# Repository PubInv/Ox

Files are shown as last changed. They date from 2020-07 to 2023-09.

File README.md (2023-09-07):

# NASA-COG

## Final Report

The final report delivered to NASA for this project can be [read here](https://drive.google.com/file/d/1jfJcSLfsybuC49I7llPhfTNI8ucRUW3h/view?usp=sharing).

## Introduction

This is a repo for a control system made for NASA to drive a Ceramic Oxygen Generation
technology they have developed. It was forked from ["The Ox"]() project of Public Invention run by Mr. Ben Coombs, which was in turn a fork of the VentOS project of Helpful Engineering let my Ben Coombs, Dr. Erich Schulz, and Robert L. Read.

However, the main reason we are starting with this fork is not that the Pressure Swing
Adsorption system of the Ox is a particularly relevant, but rather that the code
represents a nice platform of simple microcontroller control of related machines.

To wit, includes PlatformIO configuration, a state machine (finite automata),
a superloop architecutre, and a hardware abstraction layer.

This particular project of NASA will improve life support technology in space,
but may eventually greatly improve global health.

An unlisted [YouTube video](https://youtu.be/1nq-Mw7jZ5A) has been uploaded that shows this work in progress as of September, 2022.

## How to run

At present, this code does little (for the NASA COG project). We intend
to build a native (that is, laptop) simulation using mock hardware components.
The fundamental way to run this is to perform:
> cd firmware

> pio run -e native && ./.pio/build/native/program

We are currently creating the [RibbonFish](https://github.com/PubInv/NASA-COG/blob/develop/RibbonFish.md) proof-of-concept.

This can be run on a Due by executing:

> make pio-run-due_ribbonfish

As this develops, it will use a specific Due hardware configuration,
please see the [documentation](https://github.com/PubInv/NASA-COG/blob/develop/RibbonFish.md) for details to build your own.

## Annoyances

AFAIK, PlatformIO forces a directory tree depth of 5 levels.

This is not enough to organize the Hardware Abstraction Level they way I would prefer, forcing us to make some messy directories that are less than clear.

For example, to implement a Temperature Sensor, we would ideally have an
abstract (or virtual) implementation, a folder for real hardware,
and a folder for mock sensors.  I have no choice now but to jam
the mock sensors into the same directory with the real hardware and
use a naming convnention.

## The Command System

The NASA-COG system needs to allow the user to enter commands. The most obvious of these is "turn off".
Because the system should avoid thermal shocks, this is actually not simple.

We have previously used an [approach](https://github.com/PubInv/PIRCS-pubinv-respiration-control-standard) of using simple JSON objects to represent commands. We propose to use the same idea here, but obviously,
the command will be custom to the NASA-COG.

### Parameter Setting Commands
The general scheme is to use a JSON object like:

```JavaScript
{ "com": "T",
  "par": 7,
  "mod": "T",
  "val" : 732.3
  }
```

1. "com" is the command. For example, "T" can mean "set Temperature".
2. "par" is a parameter used to specify something about how to execute the command. For example, 7 could mean location 7, which might be between the 6th and 7th stack.
3. "mod" is a modifier of the command. For example, the "set Temperature" command could be used to
set the minimum, maximum, or the target temperature.
4. "val" is the value that is to be set.

For this problem space, we can specify some global parameters of the problem, some of which
involve safety. These can of course have default values "hard wired" into the code, but an
experimenter may wish to change these values (carefully).

1. The maximum rate of voltage change applied to a stack. Nominally we have defined this as 1 volt/second.
We have evidence that too rapid a voltage change (such as that caused by pulse-width modulation) can destroy
a stack.
2. The maximum rate of temperature change for a stack. Nominally we may say this as 2 degree K per minute,
which would allow the machine to reach operating temperature in 6 hours.
3. The maximum temperature difference across a stack in any dimenstion. We may not be able to control
this directly, but we can use it as a target.
4. The maximum voltage applied to a stack.
5. The maximum amperage applied to a stack.

### Event-like Commands

We will need other commands that represent discrete events in time. For example, each transition in the
state transition diagram below may be initiated by a command from the user (they may also occur
automatically due to an internal fault or even normal operation.)

COG State Machine

We can implement particular commands with the same scheme.

For example, the simple object:

```JavaScript
{ "com": "C",
  "par": 0,
  "int": "s",
  "mod": "U",
  "val" : 0.0
  }
```

Could mean "Cool Down". The value "U" is used becasue the "mod" command is "unusued" in this case.

```JavaScript
{ "com": "W",
  "par": M,
  "int": "s",
  "mod": "U",
  "val" : 0.0
  }
```

In actual practice, these commands will be pasted into the serial port using either PlatformIO or the Arduino IDE.

Eventually, a user interface may be implemented that uses a knob or a nice webpage to enter commands.
However, by having each of these take only actions that can be implemented as such a command,
we bring discipline to the internal code.

## Actual Serial Commands

The serial port currently supports 6 one-character commands: w,c,e,a,i,o.
These mean:
1. warmup
2. cool down
3. emergency shutdown
4. acknowledge
5. idle
6. operate

Note: "acknowledge" means that the operator acknowledges that a critical
state has occurred and asserts it is okay to return to normal operation,
either because the problem as been removed or for some other reason.

Addtionally, the system supports "full commands", that look like this:

> { "com": "W", "par": "M", "int": "s", "mod": "U", "val" : 0.0 }

> { "com": "C", "par": "M", "int": "s", "mod": "U", "val" : 0.0 }

> { "com": "E", "par": "M", "int": "s", "mod": "U", "val" : 0.0 }

> { "com": "A", "par": "M", "int": "s", "mod": "U", "val" : 0.0 }

> { "com": "I", "par": "M", "int": "s", "mod": "U", "val" : 0.0 }

> { "com": "O", "par": "M", "int": "s", "mod": "U", "val" : 0.0 }

In fact, each "one character" command is a short hand for these commands.

The following format can be used to set parameters (P).
The three most important parameters are:
1. T : Temperature (in C) going into the stack
2. C : Current (in milliamps) going into the stack
3. F : Fan speed in RPM (we expect this to change to flow rate in SLM)
> { "com": "P", "par": "T", "int": "T", "mod": "U", "val" : 35 }

> { "com": "P", "par": "C", "int": "T", "mod": "U", "val" : 500 }

> { "com": "P", "par": "F", "int": "T", "mod": "U", "val" : 2000 }

These three commands set the:
1. Temperature into the stack to 35C
2. Set the Target current into the stack to 500 milliamps
3. Set the flow rate to 2000 ml/seconds

## License

In general we intend to follow the [Public Invention Licensed Guidelines](https://github.com/PubInv/PubInv-License-Guidelines) unless
NASA requests something different. If you are starting your own project, please
feel free to fork the license guidelines as a starting point if you like our
license policy.

This program includes free software: you can redistribute it and/or modify it under the terms of the GNU Affero General Public License as published by the Free Software Foundation, either version 3 of the License, or (at your option) any later version.

See the GNU Affero General Public License for more details. You should have received a copy of the GNU Affero General Public License along with this program. If not, see <https://www.gnu.org/licenses/>.

This program is distributed in the hope that it will be useful, but WITHOUT ANY WARRANTY; without even the implied warranty of MERCHANTABILITY or FITNESS FOR A PARTICULAR PURPOSE.

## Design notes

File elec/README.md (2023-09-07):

# Electrical Information on ODECOS Controler(s) and Plant(s)
PCB Connector Pin signal names, Due Signal Names, Chassis wiring and related information
Inverse cronological order

## Unit 3-???
A place holder for future work
See: TBD

## Unit 2
### Notes for creation of a new PCB  
This table pulls from information in the references 1 and 2.   
References:
1. Due Pin-Out Map for OEDCS1 : https://docs.google.com/spreadsheets/d/18wP1Cyg5-j3FP92x7no_JsCCFNvo9y2avyn5nvmAj6I/edit#gid=0
2. Fan Controller and Fan Wiring for OEDCS1: https://docs.google.com/document/d/1n3v-AxqNKEzcKqmHicGKnFmG8sKbNEL_pGaUlU9CZ8U/edit

   WARNING! At present pin D4 works without an external pull up resistor for the termocouples, but D5 does not; it requires an external pull up resistor
   Until we have time to rework our perf board, I am going to continue to use D4 for the MAX31850 OneWire interface.

#### Due Pin Wiring
| **Due Pin Number** 	| **Breakout** 	| **Signal Name** 	| **Set as I/O** 	| **Connection** 	| **Notes** 	|
|---	|---	|---	|---	|---	|---	|
| D0 	| J6-2 	| NA 	| Input pullup. 	| None 	| Not used 	|
| D1 	| J6-1 	| NA 	| Input pullup. 	| None 	| Not used 	|
| D2 	| J6-3 	| NA 	| Input pullup. 	| None 	| Not used 	|
| D3 	| J6-4 	| NA 	| Input pullup. 	| None 	| Not used 	|
| D4 	| J6-5 	| SD ENABLE (BUT ALSO TEMP1) | Input pullup. 	| None 	| SD CS on Ethernet card. 	|
| D5 	| J6-6 	| TEMP1 	| BiDirection 	| Dallas 1 Wire / MAX31850K 	| Three daisy chained, requires 4.7k ohm pull up resistor (but D4 does not!) Please see note 	|
| D6 	| J6-7 	| NA 	| Input pullup. 	| None 	| Not used 	|
| D7 	| J6-8 	| NA 	| Input pullup. 	| None 	| Not used 	|
| D8 	| J7-1 	| NA 	| Input pullup. 	| None 	| Not used 	|
| D9 	| J7-2 	| nFAN1_PWM 	| Output 	| Controlles transistor Q1 	| Was BLOWER_PWM 	|
| D10 	| J7-3 	| NA 	| Input pullup. 	| None 	| Not used 	|
| D11 	| J7-4 	| NA 	| Input pullup. 	| None 	| Not used 	|
| D12 	| J7-5 	| NA 	| Input pullup. 	| None 	| Not used 	|
| D13 	| J7-6 	| NA 	| Input pullup. 	| None 	| Not used 	|
| D13 	| J7-6 	| NA 	| Input pullup. 	| None 	| Not used 	|
| D14 	| J2-1 	| NA 	| 	| None 	| Not used 	|
| D15 	| J2-2 	| NA 	| Input pullup. 	| None 	| Not used 	|
| D16 	| J2-3 	| NA 	| Input pullup. 	| None 	| Can be TX2 	|
| D17 	| J2-4 	| NA 	| Input pullup. 	| None 	| Can be RX2 	|
| D18 	| J2-5 	| D_PSU_TX 	| UART1 TX 	| D_PSU_TX, R15 (then to Power Supply 	| TX1 	|
| D19 	| J2-6 	| D_PSU_RX 	| UART1 RX 	| D_PSU_RX, R14 (then to Power Supply 	| RX1 	|
| D20 	| J2-7 	| SDA 	| SDA 	| test point SDA1, R4, R13 	| SDA 	|
| D21 	| J2-8 	| SCL 	| SCL 	| test point SCL1, R2, R16 	| SCL 	|
| D22 	| J8-4 	| BLOWER_ENABLE 	| OUTPUT 	| R10 	| Enable Switched_Fan_Power at J15 9-12 	|
| D23 	| J8-3 	| NA 	| Input pullup. 	| None 	| Not used 	|
| D24 	| J8-6 	| NA 	| Input pullup. 	| None 	| Not used 	|
| D25 	| J8-5 	| NA 	| Input pullup. 	| None 	| Not used 	|
| D26 	| J8-8 	| NA 	| Input pullup. 	| None 	| Not used 	|
| D27 	| J8-7 	| NA 	| Input pullup. 	| None 	| Not used 	|
| D28 	| J8-10 	| NA 	| Input pullup. 	| None 	| Not used 	|
| D29 	| J8-9 	| NA 	| Input pullup. 	| None 	| Not used 	|
| D30 	| J8-12 	| NA 	| Input pullup. 	| None 	| Not used 	|
| D31 	| J8-11 	| NA 	| Input pullup. 	| None 	| Not used 	|
| D32 	| J8-14 	| nCS_GPAD 	| Output for nCS 	| R55, R61, Q5 	| on 3.3 Volt 	|
| D33 	| J8-13 	| TC_nCS1 	| Output for nCS 	| Thermocouple 1, R7 	| on 3.3 Volt 	|
| D34 	| J8-16 	| TC_nCS2 	| Output for nCS 	| Thermocouple 2, R3 	| on 3.3 Volt 	|
| D35 	| J8-15 	| TC_nCS3 	| Output for nCS 	| Thermocouple 3, R1 	| on 3.3 Volt 	|
| D36 	| J8-18 	| NA 	| Input pullup. 	| None 	| Not used 	|
| D37 	| J8-17 	| NA 	| Input pullup. 	| None 	| Not used 	|
| D38 	| J8-20 	| NA 	| Input pullup. 	| None 	| Not used 	|
| D39 	| J8-19 	| NA 	| Input pullup. 	| None 	| Not used 	|
| D39 	| J8-19 	| NA 	| Input pullup. 	| None 	| Not used 	|
| D40 	| J8-22 	| NA 	| Input pullup. 	| None 	| Not used 	|
| D41 	| J8-21 	| NA 	| Input pullup. 	| None 	| Not used 	|
| D42 	| J8-24 	| NA 	| Input pullup. 	| None 	| Not used 	|
| D43 	| J8-23 	| NA 	| Input pullup. 	| None 	| Not used 	|
| D44 	| J8-26 	| NA 	| Input pullup. 	| None 	| Not used 	|
| D45 	| J8-25 	| NA 	| Input pullup. 	| None 	| Not used 	|
| D46 	| J8-28 	| NA 	| Input pullup. 	| None 	| Not used 	|
| D47 	| J8-27 	| NA 	| Input pullup. 	| None 	| Not used 	|
| D48 	| J8-30 	| NA 	| Input pullup. 	| None 	| Not used 	|
| D49 	| J8-29 	| NA 	| Input pullup. 	| None 	| Not used 	|
| D50 	| J8-32 	| NA 	| Input pullup. 	| None 	| Not used 	|
| D51 	| J8-31 	| SSR_PWM 	| OUTPUT 	| R9 	| Active High. 	|
| D52 	| J8-34 	| NA 	| Input pullup. 	| None 	| Not used 	|
| D53 	| J8-33 	| NA 	| Input pullup. 	| None 	| Not used 	|
| SDA1 	| J7-9 	| NA 	| Input pullup. 	| None 	| Not used 	|
| SCL1 	| J7-10 	| NA 	| Input pullup. 	| None 	| Not used 	|
| CANR 	| J4-7 	| NA 	| Input pullup. 	| None 	| Not used 	|
| CANT 	| J4-8 	| NA 	| Input pullup. 	| None 	| Not used 	|
| DAC0 	| J4-5 	| Disable 	| Only Output 	| None 	| Not used 	|
| DAC1 	| J4-6 	| Disable 	| Only Output 	| None 	| Not used 	|
| A0 	| J5-1 	| BLOWER_TACH 	| Input pullup. 	| R11 	| Measure RPM 	|
| A1 	| J5-2 	| NA 	| Input pullup. 	| None 	| Not used 	|
| A2 	| J5-3 	| NA 	| Input pullup. 	| None 	| Not used 	|
| A3 	| J5-4 	| NA 	| Input pullup. 	| None 	| Not used 	|
| A4 	| J5-5 	| NA 	| Input pullup. 	| None 	| Not used 	|
| A5 	| J5-6 	| NA 	| Input pullup. 	| None 	| Not used 	|
| A6 	| J5-7 	| NA 	| Input pullup. 	| None 	| Not used 	|
| A7 	| J5-8 	| NA 	| Input pullup. 	| None 	| Not used 	|
| A8 	| J4-1 	| NA 	| Input pullup. 	| None 	| Not used 	|
| A9 	| J4-2 	| NA 	| Input pullup. 	| None 	| Not used 	|
| A9 	| J4-2 	| NA 	| Input pullup. 	| None 	| Not used 	|
| A10 	| J4-3 	| NA 	| Input pullup. 	| None 	| Not used 	|
| A11 	| J4-4 	| NA 	| Input pullup. 	| None 	| Not used 	|
| AREF 	| J7-8 	| NA 	| From DUE 	| None 	| Not used 	|
| nRST1 	| J3-6 	| NA 	| Pulled up on DUE 	| None 	| Not used 	|
| IOREF 	| J3-7 	| NA 	| NA 	| None 	| Not used 	|
| VIN 	| J3-1 	| VIN 	| NA 	| +12V into this pin through R76 	| 	|
| +5V 	| J3-4 	| VIN+5V 	| NA 	| Power from Due voltage regulator 	| Three pins. 	|
| 3.3V 	| J3-5 	| 3.3V 	| NA 	| Power from Due voltage regulator 	| One pin. 	|
| MISO 	| tp CPIO1 	| CIPO 	| Input 	| SPI bus 	| 	|
| MOSI 	| tp COPI 	| COPI 	| Output 	| SPI bus 	| 	|
| SCK 	| tp SPI_SCK 	| SPI_SCK 	| Output 	| SPI bus 	| 	|
| nRST2 	| NA 	| SPI_nRST 	| Input 	| S1 reset switch 	| 	|
| end 	| 	| 	| 	| 	| 	|  

**Ethernet pin usage:**
Pins usage on Arduino
* D4: SD card chip select
* D10: W5200 Chip Select
* D11: SPI MOSI
* D12: SPI MISO
* D13: SPI SCK

### Chassis Wiring of ODECOS Unit 2.
Diagram(s) here...

## Unit 1
Wiring of ODECOS Unit 1 Notes
1. Due Pin-Out Mape for OEDCS1 : https://docs.google.com/spreadsheets/d/18wP1Cyg5-j3FP92x7no_JsCCFNvo9y2avyn5nvmAj6I/edit#gid=0
2. Fan Controller and Fan Wiring for OEDCS1: https://docs.google.com/document/d/1n3v-AxqNKEzcKqmHicGKnFmG8sKbNEL_pGaUlU9CZ8U/edit

Wiring of thermocouple amplifires


Revisions:
* 20230821, Update DB25 Male 2-5 from +12V to "+24V Switched (fans)"

| Fan Breakout 	| Signal-Function 	| DB25 MALE Pin # 	| DB25 FEMALE Pin # 	| Other 	| Due Pin 	| Due Signal 	|
|---	|---	|---	|---	|---	|---	|---	|
| 1 	| +24V Switched (fans) 	| 2-5 	| 9-12 	| 	| ??? 	| FAN_POWER 	|
| 2 	| GND for all fans  	| 22-25 	| 14-17 	| 	| GND 	| NA 	|
| 3 	| #1 PWM 	| 13 	| 1 	| J10-1 	| D9 	| nFAN1_PWM  	|
| 4 	| #1 Tach 	| 9 	| 5 	| J9-1  	| A0 	| FAN1_FG 	|
| 5 	| #2 PWM 	| 12 	| 2 	| J10-2 	| 	| nFAN2_PWM  	|
| 6 	| #2 Tach 	| 8 	| 6 	| J9-2  	| 	| FAN2_FG 	|
| 7 	| #3 Tach 	| 11 	| 3 	| J10-3 	| 	| nFAN3_PWM  	|
| 8 	| #3 PWM 	| 7 	| 7 	| J9-3  	| 	| FAN3_FG 	|
| 9 	| #4 Tach 	| 10 	| 4 	| J10-4 	| 	| nFAN4_PWM  	|
| 10 	| #4 PWM 	| 6 	| 8 	| J9-4  	| 	| FAN4_FG 	|
| 	| 	| 	| 25 	| J11-3 	| 	| 	|
| 	| 	| 	| 13 	| J11-4 	| 	| 	|
| 	| 	| 	| 18 	| J12-1 	| 	| 	|
| 	| 	| 	| 19 	| J12-2 	| 	| 	|
| 	| 	| 	| 20 	| J12-3 	| 	| 	|
| 	| 	| 	| 21 	| J12-4 	| 	| 	|
| 	| 	| 	| 22 	| J12-5 	| 	| 	|
| 	| 	| 	| 23 	| J12-6 	| 	| 	|
| 	| 	| 	| 24 	| J12-7 	| 	| 	|

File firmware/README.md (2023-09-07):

# Firmware
This folder contains...

### References:

* Data sheet of the ST Power Electronics power supply TF800A12K  
[https://slpower.com/data/collateral/AN_TF800.pdf](https://slpower.com/data/collateral/AN_TF800.pdf)
* Programing of the ST Power Electronics power supply  
[https://slpower.com/data/collateral/AN-P0036%20TF%20Series%20Communication%20Protocal%20User%20Manual.pdf](https://slpower.com/data/collateral/AN-P0036%20TF%20Series%20Communication%20Protocal%20User%20Manual.pdf)

# Ox Firmware

Ox firmware uses [PlatformIO](https://platformio.org/) for development.

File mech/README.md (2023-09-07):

# OEDCS
Oxygen Engine Digital Control System, enclosure for.

## Mechanical Files

* The "frontpanel" folder has FreeCAD drawing which generate the DXF and other files for fabrication of the frontpanel, bottompanel and rear panel.
* The "enclosure" folder has an OpenSCAD drawing of the Unit 1 enclosure. With in the folder is a folder "FreeCADAssy" which has a FreeCAD drawing using the A2plus work bench and duplicates roughly the Unit 1 assembly but which has the Unit 2 frontpanel, bottompanel and rear panel files.

## Front Panel and Enclosure Folders  Unit 2
Place holder for July-August 2023 Begin Construction of Unit 2. 

* Goal: Mimimal design changes from Unit 1. Possible retrofit to Unit 1 of any changes.
* Fabrication of Version 2 unit Frontpanel, Bottompanel and Rearpanel not by hand in house. 
* The Frontpanel Version 2 has enlarged AC receiptical opehnings and will require reciptical cover plates.

## Front Panel and Enclosure Folders  Unit 1
A March 2023 enclosure for prototyping, proof of concept for the COG controller. 
This prototype has:
* A programmable power supply (Voltage and current), 
* Solid state relays for switching AC power to preheaters
* Power and PWM control for fans to force air into the COG
* Air Temperature and air flow rate sensors
* An Arduino Due for system control.
Navigate into the folders to see more.

Overhead view of Unit 1 wiring as of June - July 2023

https://user-images.githubusercontent.com/5836181/250552512-68546480-32a5-4593-8a75-600ff2462f9f.png

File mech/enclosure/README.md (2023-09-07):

# Enclosure
Bottom, back and sides on which to mount the Front Panel which is defined in the front panel folder

## Details
Parts drawings developed in OpenSCAD
An assembly drawing in FreeCAD. This drawing shows an intermediate horizontal shelf which was not fabricated. This drawing does not show the sides or rear panel.  

## First Enclosure Fabrication Notes and Photos

Open SCAD View of Enclosure
Drawings used during parts order for Unit 1
  

Drawings used during parts order for Unit 2
FreeCAD view of Assembly (including one power supply)  


## Parts List (Partial)
| Quantity 	| Description 	| Manufacturer 	| Man Part Number 	| Distributor 	| Distributor Part Number 	| Drawing 	| Cost Each 	|
|---	|---	|---	|---	|---	|---	|---	|---	|
| 1 	| BottomPanelTechDrawVersion120230406_0024.pdf 	| PublicInvention 	| TBD 	| NA 	| NA 	| [BottomPanelTechDrawVersion120230406_0024.pdf](../frontpanelBottomPanelTechDrawVersion120230406_0024.pdf) 	| 	|
| 1 	| RearPanel2Version120230407_1358.pdf 	| PublicInvention 	| TBD 	| 	| 	| [RearPanel2Version120230407_1358.pdf](RearPanel2Version120230407_1358.pdf) 	| 	|
| 1 	| Side Panel Left 	| PublicInvention 	| TBD 	| 	| 	| None, Freehanded. 	| 	|
| 1 	| Side Panel Left 	| PublicInvention 	| TBD 	| 	| 	| None, Freehanded. 	| 	|
| 10 approximately 	| 2020 Corner Bracket Plate Anodised L Shape 5 Hole 90 Degree Outside Joining Plate 	| 	| 	| Amazon 	| 10 approximately 	| 	| 1.50 	|
| 150 	| 2020 Series Screws and T Nuts T-Slot Nut Hammer Head Fastener, (M5) 	| 	| 	| Amazon 	| https://www.amazon.com/Fastener-Nickel-Plated-Sliding-Aluminum-Profile/dp/B086MKNYDS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 	| 	| 0.06 	|
| 2 	| 400mm V Slot 2040 Aluminum Extrusion European Standard Anodized Black Linear Rail 	| 	| 	| Amazon 	| https://www.amazon.com/Aluminum-Extrusion-European-Standard-Anodized/dp/B0BZ57L6CB/ref=sr_1_1_sspa 	| 	| 9.50 	|
| 4 	| 400mm T Slot 2020 Aluminum Extrusion European Standard Anodized Linear Rail 	| 	| 	| Amazon 	| https://www.amazon.com/European-Standard-Anodized-Aluminum-Extrusion/dp/B099MRRKJ2/ref=sr_1_2_sspa 	| 	| 4.75 	|
| 4 	| 700mm T Slot 2020 Aluminum Extrusion European Standard Anodized Linear Rail 	| 	| 	| Amazon 	| https://www.amazon.com/Aluminum-Extrusion-European-Standard-27-56inch/dp/B09SF2TX3G/ref=sr_1_1 	| Cut down for cabnet length. 	| 10.00 	|
| 1 	| Rocker Switch DPST 4 Pin Red Lighted 120V Rocker Toggle Switch ON Off 	| 	| 	| Amazon 	| https://www.amazon.com/Yoiilnz-250VAC-125VAC-Rocker-Lighted/dp/B0BB9KJDCN/ref=sr_1_1 	| 	| 2.73 	|
| 1 	| 10 ft - 12 Gauge Heavy Duty Lighted SJTW Indoor/Outdoor Yellow Extension 	| 	| 	| Amazon 	| https://www.amazon.com/10-Extension-12-Gauge-Grounded-Power-Cord/dp/B0835TCLF5/ref=sr_1_2 	| 	| 	|
| 1 	| 1-1/4-in Die Cast Zinc Clamp-on Type Service Entrance Connector Conduit Fittings  	| 	| 	| Lowes 	| https://www.lowes.com/pd/Sigma-Electric-ProConnex-1-1-4-in-Clamp-on-Type-Service-Entrance-Connector-Conduit-Fitting/1087431 	| 	| 2.65 	|
| 1 	| 3/4-in Die Cast Zinc Clamp-on Type Service Entrance Connector Conduit Fittings 	| 	| 	| Lowes 	| https://www.lowes.com/pd/Sigma-Electric-ProConnex-3-4-in-Clamp-on-Type-Service-Entrance-Connector-Conduit-Fitting/1087283 	| 	| 1.50 	|
| 1 	| 1/2" NM Clamp Type Cable Connectors 	| 	| 	| Amazon 	| https://www.amazon.com/Connectors-Metallic-Conduit-Protect-Silver-Zinc/dp/B09M3MKL74/ref=sr_1_1_sspa 	| 	| 0.91 	|
| 3 	| DIN Rail Slotted Aluminum RoHS 12" Inches Long 35mm Wide 7.5mm High 	| 	| 	| Amazon 	| https://www.amazon.com/Pieces-Slotted-Aluminum-Inches-7-5mm/dp/B079TX7WDQ/ref=sr_1_1_sspa 	| Cut to fit. 	| 5.00 	|

Other:
This does not include the internal wiring description.
Does not include the COG power supply, Due controller, thermocouple amplifiers, Fan Relays, air heater Controllers, 
This does not include systems external to the enclosure such as thermocouple wires, air flow sensors or their wiring.  

### Some deviations of note:
Miscellaneous 6-32, 8-32 and 10-24 screws may have been used.  
? April 2023? Robert relocated the ground lug terminal strip inside the cabinet. Lee believes new holes had to be drilled.

### Wiring of Assemblies In Enclosure
**The Arduino Due Ethernet Rail Mount Shield. ** 
For controller Unit 1, before we have the Controller V1 PWA, make doe with this for Due and Ethernet on Rail mount 
 
**From an email:**
> On Wed, Aug 23, 2023 at 10:00 AM Robert Read wrote:
Last night I used a variant of Lawrence's approach; after talking with him, I used not one but TWO stack able headers to obtain the correct height on all pins. I had to trim the posts to about half their normal height with side cutters to make this work. (The two-row header at the end is a pain, I need to order proper headers for it, I built it out of spare parts.)
> But the result works. I have notest connectivity on every pin, but it works for the Ethernet card, which is now working. I am working with Geoff to make some tweaks, but we are now producing a datalog at his data server which we can feed into Cumulocity, though at present it is boring because I am not turning it on.

### Cautions
None.

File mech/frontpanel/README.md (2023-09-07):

# Frontpanel
An aluminum plate on which the NASA-COG control system electrical intefaces are mounted from, and presented to the controlled elements.
This front panel was later mounted to an enclosure defined in the enclosure folder.

## Details
Developed in FreeCAD
One FreeCAD drawing defins the **Frontpanel**, **Rearpanel** and **Bottompanel**. There is a drawing representing two DIN rails that may be mounted on the bottom panel.
Images of many parts to be mounted on the front panel are scaled and place in a group. This group can be displayed on the front panel to check the design and convey the resulting device.

## Second Front Panel Fabrication Notes
Fabrication of a Second controler beginning late July 2023.
Version 2 front panel.
FreeCAD view


Fabrication drawing for front panel Version 2.0 of 20230731


## Parts List Second Controller (Partial)
| Quantity 	| Description 	| Manufacturer 	| Man Part Number 	| Distributor 	| Distributor Part Number 	| Drawing 	| Cost Each 	|
|---	|---	|---	|---	|---	|---	|---	|---	|
| 1 	| frontpanel-PartFrontPanel2frontpanel2.dxf 	| PublicInvention 	| TBD 	| NA 	| NA 	| [frontpanel-PartFrontPanel2frontpanel2.dxf](frontpanel-PartFrontPanel2frontpanel2.dxf) 	| 	|

<hr> 

## First Front Panel Fabrication Notes
Fabrication drawing for front panel of 20230324


## Parts List (Partial)

| Quantity | Description | Manufacturer | Man Part Number | Distributor | Distributor Part Number | Drawing | Cost Each |
|---|---|---|---|---|---|---|---|
| 1 | frontpanel_Rev1_3.dxf | PublicInvention | TBD | NA | NA | [frontpanel_Rev1_3.dxf](frontpanel_Rev1_3.dxf) | |
| 3 | Panel Plate SB1 Dual | | | Powerwerx | PanelPlateSBDual | [SB1 Drawing](Parts/Mech/PanelplateSB1-SB1DuaulDimensions.pdf) | 14.99 |
| 6 | Protective Plug with Lanyard | | | Powerwerx | PLUG-SB50 | https://powerwerx.com/rigid-plug-cap-lanyard-sb50 | 4.49 |
| 3 | Circuit Breaker | Carling Technologies | AA1-B0-34-615 -5D1-C | Granger | 10C591 | [Breaker Drawing](Parts/Mech/Breaker_10C588_1.pdf) | 14.77 |
| 3 | GFI Receptical | | | Harbor Freight | 57958 | https://www.harborfreight.com/15-amp-125v-self-test-gfci-duplex-outlet-57958.html | 9.99 |
| 1 | DB25 Panel Mount, FanControllerBareBoardPCB  | PublicInvention | TBD | | | [FanControllerBareBoardPCB.jpg](../develop/elec/FanControllerBareBoardPCB.jpg) | |
| 1 | DB9 Panel Mount, I2C interface | PublicInvention | TBD | | | | |
| 1 | ground bar | GE | TGK12CP | Lowes | 105748 | https://www.lowes.com/pd/GE-1-in-Ground-Bar-Kit/1001535 | $8.98 |
| 1 | Jack Panel for Thermocouple 1x12 | Omega | MJP1-12-BLANK | Omega | MJP1-12-BLANK | [Jack Panel Drawing](Parts/Mech/mpj-j-f-thermocouple/JackPanel_MJP.pdf) | $26.76 |
| 1 | Snap Strip for Thermocouple  1x12 | Omega | MMS-12 | Omega | MSS-12 | [SnapStrip Drawing](Parts/Mech/MSS_Series.pdf) | 12.34 |
| 3 | Miniature Thermocouple Panel Jack Connectors | Omega | MPJ-K-F | Omega | MPJ-K-F | [SnapStrip Drawing](Parts/Mech/MSS_Series.pdf) | $4.26 |
| 24 | M5-8mm pan head screw | | | Amazon | | https://www.amazon.com/M5-0-8-Button-Socket-Stainless-Quantity/dp/B084MMND2L/ref=asc_df_B084MMND2L | $.0899 |
| 24 | 5mm T Nut Sliding 10mmx6mm | | | Amazon | | https://www.amazon.com/Fastener-Nickel-Plated-Sliding-Aluminum-Profile/dp/B086MKNYDS/ref=sr_1_1_sspa | $0.053 |

### Some deviations of note:
I drilled and tapped the holes for mounting the GFI receipticals for 6-32 screw holes and screwed the GFI from the rear with shortened screws. The protuding ends of these screews are a minor hazard for scratching flesh.  
I drilled and tapped the screw holes for 10-32 for mounting the ground bar.
I attached a single teathered connector cap for the Anderson connector with a plastic cable clamp to a near by screw mounting the circuit breaker.  

?April 2023? Robert relocated the ground lug terminal strip inside the cabnet. Lee believes new holes had to be drilled.

## Older FreeCAD screen capture showing images of some of the parts behind the "frontpanel".  
These drawings and ideas lead up to the first fabricated front panel and differ from it.  
Images as of 20230317 2107 EDT




### Cautions
There appears to be an error on the holes for the Anderson front panel connector mount. (20230326 FLE, Corrected before fabrication.)

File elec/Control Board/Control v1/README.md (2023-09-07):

# Control V1
Version 1 control board for NASA COG
On line schematic viewing from **Kicanvas** See: https://kicanvas.org  
The Control V1 is an Arduino DUE "Shield". The DUE will live below this printed wiring assembly. An Ethernet shield will live above as a "Socket". See KiCad Symbol & Footprint Library for Arduino Modules for "Shield" and "Socket"

## Schematics
### Browser page view of the schematic by KiCanvas.org 
Top page is "Control v1.kicad_sch". Note the page for MAX31856 is actualy for an MCP9600 but the page was not renamed (as of 20230830)
*  [Control v1.kicad_sch](https://kicanvas.org/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)
* [Adafruit-MAX31850-thermocouple-breakout-board.kicad_sch](https://kicanvas.org/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)
* [Adafruit-MAX31855-breakout-board.kicad_sch](https://kicanvas.org/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)
* [Adafruit-MAX31856-PCB-master.kicad_sch](https://kicanvas.org/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)
* [Fan controller.kicad_sch](https://kicanvas.org/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)
* [I2C_Level_Shifter.kicad_sch](https://kicanvas.org/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)
* [SPI_ControllerLevel_Shifter.kicad_sch](https://kicanvas.org/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)
* [SSR Interface.kicad_sch](https://kicanvas.org/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)

## PCB / PWA
### Browser page view of the PCB by KiCanvas.org 
Printed Circuit Board, Printed Wiring Assembly
* [Control v1.kicad_pcb](https://kicanvas.org/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](https://kicanvas.org/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))

### PCB / PWA 3D Snapshot


File Notes:
Add BOM spread sheet and a JLCPCB BOM.  The instructions / notes for generating the BOM and JLCPCB BOM are embedded in the file, Control_V1_BOM.xls. The proccess starts in KiCad with the BOM gewnerator nick name, "bom_csv_grouped_by_value"
* Control_V1_BOM.xls
* Control_V1_BOM_JLCPCB_20230829_2137.csv

## License, Public Invention for this PCB, PWA
* [Firmware: Affero GPL 3.0](https://www.gnu.org/licenses/agpl-3.0.en.html#license-text)
* [CERN Open Hardware Licence Version 2 - Strongly Reciprocal](https://ohwr.org/cern_ohl_s_v2.txt)
<hr> 

## KiCad Symbol & Footprint Library for Arduino Modules
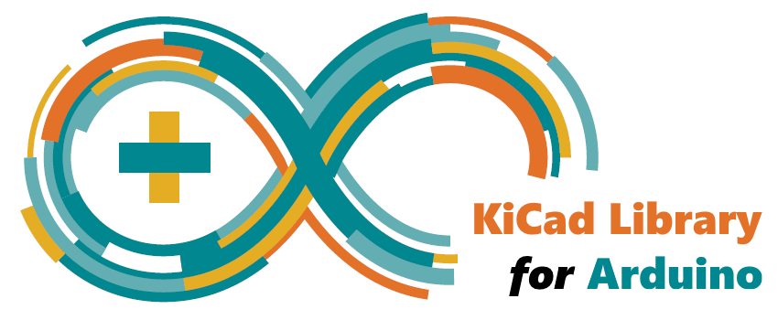
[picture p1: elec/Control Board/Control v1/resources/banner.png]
<a href="./PICS/Rev2/PWA_FrontView.png">  
*Version 4.1.0*  

     

This is a library of KiCad schematic symbols and PCB footprints for most Arduino modules. You can use them to make your own PCB design which will effortlessly connect with your chosen Arduino module.

Currently included modules:
- Arduino **101** Shield
- Arduino **Due** Shield
- Arduino **Giga R1 WiFi** Shield
- Arduino **Leonardo** Shield
- Arduino **M0** Shield
- Arduino **M0 Pro** Shield
- Arduino **Mega 2560 R3** Shield
- Arduino **Micro** Socket
- Arduino **Mini** Socket
- Arduino **MKR 1000 WiFi** Socket
- Arduino **MKR WiFi 1010** Socket
- Arduino **MKR FOX 1200** Socket
- Arduino **MKR WAN 1300** Socket
- Arduino **MKR WAN 1310** Socket
- Arduino **MKR GSM 1400** Socket
- Arduino **MKR NB 1500** Socket
- Arduino **MKR Vidor 4000** Socket
- Arduino **MKR Zero** Socket
- Arduino **Nano** Socket
- Arduino **Nano 33 BLE** Socket / Tile
- Arduino **Nano 33 BLE Sense** Socket / Tile
- Arduino **Nano 33 BLE Sense R2** Socket / Tile
- Arduino **Nano 33 IoT** Socket / Tile
- Arduino **Nano Every** Socket / Tile
- Arduino **Nano RP2040 Connect** Socket / Tile
- Arduino **Nicla Sense ME** Socket / Tile
- Arduino **Nicla Vision** Socket / Tile
- Arduino **Nicla Voice** Socket / Tile
- Arduino **Pro Mini** Socket
- Arduino **Uno R1** Shield
- Arduino **Uno R2** Shield
- Arduino **Uno R3** Shield
- Arduino **Uno R3 SMD** Shield
- Arduino **Uno R4 Minima** Shield
- Arduino **Uno R4 WiFi** Shield
- Arduino **Uno WiFi R2** Shield
- Arduino **Zero** Shield
- Clone **Mega 2560 Pro** Socket
- Clone **Pro Mini** Socket

*"Shield" means the module is designed to plug in from beneath your PCB. "Socket" means the module is designed to plug in from above your PCB. "Tile" means the module is designed to be soldered directly on to your PCB using surface-mount pads.*

## KiCad Version Compatibility
This library requires at least KiCad 6 to function, and is tested on KiCad versions 6.0.8 and 7.0.2. Note that the installation procedure is different for KiCad 6 and 7; please see the [Library Installation](#library-installation) section below.

## Comments, Requests, Bugs & Contributions
All are welcome!
Please open an [Issue](https://github.com/Alarm-Siren/arduino-kicad-library/issues) or [Pull Request](https://github.com/Alarm-Siren/arduino-kicad-library/pulls), as appropriate.

## Library Installation
To install this library in your copy of KiCad, choose the correct section for your version of KiCad and follow the steps given. These instructions only cover automated installation using KiCad's built-in Package and Content Manager (PCM); manual installation is possible but not supported.

### KiCad 7

**Warning**: Do not change the nickname prefix from that given in step 4 below. If you do so KiCad will not assign the correct footprints to the symbols by default.

1. Open KiCad and open the Preferences window at "Preferences" -> "Preferences..."
2. Select the "Plugin and Content Manager" section in the left-hand pane.
3. Ensure that the "Automatically add installed libraries to the global lib table" option is ticked.
4. Ensure that the "Library nickname prefix" is set to "PCM_".
5. Ensuring that the "Check for package updates on startup" option is ticked is recommended. **(Optional)**
6. Click "OK" to close the Preferences window.
7. Click the "Plugin and Content Manager" button.
8. Select the "KiCad official repository" from the top drop-down box (if not already selected).
9. Go the Libraries tab and locate the "KiCad Library for Arduino Modules" in the list.
10. Click the "Install" button for that entry in the list.
11. Click "Apply Pending Changes".
12. Close the "Applying Package Changes" window once it has finished.
13. You should now find that this library is listed in the "Installed" tab.
14. Close the Plugin and Content Manager.
15. You may need to restart KiCad for the library installation to fully take effect. **(Optional)**
16. All done: you are now ready to use these schematic components and footprints in your projects!

### KiCad 6
**Recommendation:** If you can, you should upgrade to KiCad 7.

**Warning**: Do not change the Nicknames from those given in steps 12 and 18 below. If you do so KiCad will not assign the correct footprints to the symbols by default.

1. Open KiCad and click the "Plugin and Content Manager" button.
2. Select the "KiCad official repository" from the top drop-down box (if not already selected).
3. Go the Libraries tab and locate the "KiCad Library for Arduino Modules" in the list.
4. Click the "Install" button for that entry in the list.
5. Click "Apply Changes".
6. Close the "Applying Package Changes" window once it has finished.
7. You should now find that this library is listed in the "Installed" tab.
8. Close the Plugin and Content Manager.
9. Go to the "Preferences" -> "Manage Symbol Libraries..." menu option.
10. In the Symbol Libraries dialogue that appears, switch to the "Global Libraries" tab (if not already selected).
11. Click "Add empty row to table" button (the button with a big cross in it, beneath the table).
12. In the new line of the table, set the Nickname to "PCM_arduino-library", and ensure the Library Format is set to "KiCad".
13. In the same line of the table, set Library Path to "${KICAD6_3RD_PARTY}/symbols/com_github_alarm-siren_arduino-kicad-library/arduino-library.kicad_sym".
14. Click "OK" to close the Symbol Libraries dialogue.
15. Go to "Preferences" -> "Manage Footprint Libraries..." menu option.
16. In the Footprint Libraries dialogue that appears, switch to the "Global Libraries" tab (if not already selected).
17. Click "Add empty row to table" button (the button with a big cross in it, beneath the table).
18. In the new line of the table, set the Nickname to "PCM_arduino-library", and ensure the Library Format is set to "KiCad".
19. In the same line of the table, set Library Path to "${KICAD6_3RD_PARTY}/footprints/com_github_alarm-siren_arduino-kicad-library/arduino-library.pretty".
20. Click "OK" to close the Footprint Libraries dialogue.
21. All done: you are now ready to use these schematic components and footprints in your projects!

## Donations

I really hope you've found this library useful. If you'd like to buy me a beer in thanks for the work I put into it, you can make a donation using the button below:



## License & Legal
Copyright 2017-2023, [Nicholas Parks Young](https://github.com/Alarm-Siren).

Except as otherwise noted, all content of this library is licensed under the 
[Creative Commons Attribution-ShareAlike 4.0 International License](https://creativecommons.org/licenses/by-sa/4.0/), with the following additional exception:
> To the extent that the creation of electronic designs that use the Licensed Material can be considered to be Adapted Material, the Licensor waives Section 3 of the Public License with respect to these electronic designs and any generated files which incorporate data provided as part of the Licensed Material.



### "KiCad Library for Arduino" Banner & Icon

The two images "resources/banner.png" and "resources/icon.png" are licensed under the [Creative Commons Attribution-NonCommercial-ShareAlike 4.0 International License](https://creativecommons.org/licenses/by-nc-sa/4.0/). These images are derivatives of ["Arduino Open-Source Community: Main Logotype RGB Colors" originally created by Arduino](https://www.arduino.cc/en/trademark/community-logo). 

Original Images: Copyright 2013, [Arduino](https://www.arduino.cc/). Derived Images: Copyright 2023, [Nicholas Parks Young](https://github.com/Alarm-Siren).



### Arduino Trademark

The word "Arduino" is a registered trademark of [Arduino](https://www.arduino.cc/). This trademark is used in this library to refer to Arduino products and to identify Arduino-related non-commercial content, as permitted by Arduino's [trademark guidelines](https://www.arduino.cc/en/trademark). This project is not affiliated with nor endorsed by Arduino.

## FAQ

Answers to some common questions about this library.

### Is this library in active development?

Yes. For the foreseeable future, I will be providing support, bug-fixes and updating the library with any new Arduino modules as they are released.

### What does the license exception in the License & Legal section mean?

This library uses the same license as KiCad's own built-in parts library does, including the exception. The KiCad Libraries team have a [page which explains the meaning of the exception](https://www.kicad.org/libraries/license/). My version of the exception uses slightly better wording, but the effect is the same.

### Why do the footprints not have an `Edge.Cuts` outline?

If I put in an `Edge.Cuts` outline, then those users who want to have a PCB larger than the module footprint would have to modify the footprint to do so. In my experience, it is far more common for users to want a PCB larger than the module anyway, so I prefer to cater to those users. If you want your PCB to be the same size and shape as the Arduino module, you can trace the `F.Silkscreen` or `B.Silkscreen` layer (as appropriate) out in the `Edge.Cuts` layer yourself, or you can modify the footprint to change the outline from `F.Silkscreen` or `B.Silkscreen` layer to `Edge.Cuts`.

### Why do the Nicla Vision and Nicla Voice tile footprints have cut-outs?

The cut-outs are necessary to accommodate components on the back of those modules; without them the components would physically prevent you from getting the module's pads down to the footprint's SMD pads.

### Why does the whole footprint have an `F.Courtyard` or `B.Courtyard` outline? I can't place my components where I need to!

Firstly, this does not stop you from placing your components wherever you want. It does mean that the KiCad DRC will, by default, report errors or warnings in some circumstances because the module footprint and your circuit's footprints' courtyards are overlapping, but you can ignore or disable these errors/warnings without issue.

Secondly, the intention is that it acts as a warning to the user that they've put components in the 'danger zone' between their PCB and the Module. I do not model all of the tall components on the module, so it is possible that a user might unknowingly place their own tall component in a position that would conflict with one on the module. My hope is that the DRC errors/warnings will flag this potential problem to the user to manually check that their placement does not conflict with the module.

In principle I'm open to marking the taller components specifically, which would remove this issue, but this is a lot of work and requires data I don't have access to for all the modules.

### Why is this Power Pin set to Power Input/Power Output/Unconnected? I get DRC errors because of it!

The short answer is that some power pins on some modules can be used as either inputs or outputs, depending on your circuit design / where you're powering the assembly from.

For those pins where I've been able to categorically confirm that the given power pin is Unconnected by default, or must necessarily be a Power Input or a Power Output, I have set it as such. For those pins that can be used as either an input or output, I have set it to Power Input as this is the more flexible option whilst still preserving some element of DRC capability. If you're using one of these Power Input pins as a Power Output from the module, you'll need to add the special "PWR_FLAG" component to the affected net to make the DRC error go away.

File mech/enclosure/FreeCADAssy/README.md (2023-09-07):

# Enclosure Drawings

## FreeCAD Drawing of Enclosure Unit 2



Note the 20x20mm extrustions are approximated by square tubes.

## Parts List, Unit 2
| **Item** | **Quantity** | **Part Number** | **Description** | **Cost** | **Note** |
|---|---|---|---|---|---|
| 1 | 4 | | 20x20x240mm Extrusion  | | Sets height when combined with 40mm |
| 2 | 4 | | 20x20x460mm Extrusion  | | Sets length when combined with 3.15mm |
| 3 | 4 | | 20x20x400mm Extrustion | | Sets width when combined with 40mm |
| 4 | 2 | | 20x20x420mm Extrusion  | | Possible shelf support. |
| 5 | 1 | frontpanel-PartFrontPanel2frontpanel2.dxf | Front panel V2 DXF | | |
| 6 | 1 | frontpanel-PartBottomPlateV2.oBodyBottomPlateV2.dxf | Bottom panel V2 DXF | | |
| 7 | 1 | RearPanel3.dxf | Rear panel for V2 DXF  | | |
| 8 | | | | | |
| 9 | | | | | |

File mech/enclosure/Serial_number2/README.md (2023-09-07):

# Serial Number 2 OEDCS Enclosure
Information capturing the build of Serial_number2 OEDCS 

## Details

## Second Enclosure Fabrication Notes and Photos
### CAD drawings. 
Isometric view of FreeCad assembly drawing showing the Ethernet, Controller V1 and Due assembly off to the side.
> 

### Parts
Enclosure 2 parts and assembly stuff  
> 

Front and bottom panels  
> 

Bottom and rear panel  
> 

### Some deviations of note during assembly
We had to......
Lawrence made modifications to the DXF files for rear panel holes
and may include the following
> On 08/14/2023 5:56 PM EDT Lawrence Kincheloe <lokimail@gmail.com> wrote:
> I would also like to add a USB and Ethernet jack to the back as well.
> Both require a 30 mm hole. 
> https://www.adafruit.com/product/4212
> https://www.adafruit.com/product/4130
> Something missing from this diagram is cutouts for the fans for the power supplies and SSR. These WILL need active cooling and we will need to account for air flow from the back to the side panels 

## Parts List (Partial)
*stuff here in a table*

### Other:
This does not include the ...

### Wiring of Assemblies In Enclosure

*stuff here such as the asembly of the DUE, Controller V1, and Ethernet cards*
The Due and ethernet cards mount with the Controler V1 card something like this:
Perspective view showing the ethernet card above the Controler V1 card  
>   

Top view showing the ethernet card above the Controler V1 card  
>   

Bottom view showing the Due card above the Controler V1 card  
> 

Side view showing the ethernet card above the Controler V1 card and the Due below
> 

### Cautions
None.

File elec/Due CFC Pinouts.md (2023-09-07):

# Due CFC Pinouts

This document describes the pinouts for the OEDCS designed for the CFC of approximately Aug. 18th.

| Due Pin Number  | 	Signal Name  | Set as I/O  | Connection  |  Notes |
|---|---|---|---|---|
| A0 |	FAN1_FG | Input | Blower 1 Tachometer
| D4 |	TEMP1	| BIDirect |	Dallas One-Wire connection to Thermocouple Breakouts |	Daisy chain connection to temprature probes. Address of ???
| D9 | nFAN1_PWM | Output | Blower PWM | This output will be inverted
| D18 |	TX1 | Output |	Digital Power Supply TF800 Pin 23 | This is Serial1 TX for (power supply)[https://assets.alliedelec.com/v1560852133/Datasheets/1d230174086e96b6e4801d1c963649f3.pdf]
| D19 | RX1 |Input | Digital Power Supply TF800 Pin 24 | This is Serial1 RX for (power supply) [https://assets.alliedelec.com/v1560852133/Datasheets/1d230174086e96b6e4801d1c963649f3.pdf]
| D22 | BLOWER_ENABLE |Output |	Blower Enable 
| D32 | GPAD_nCS | Output |	 External SPI inverted select (for the GPAD)
| D44 |LPBK0 |Output |	Varying loopback signal
| D45 |LPBK1 |Input |	Read of digital loopback signal
| D51 |HEAT1 |Output |	Positive SSR signal
| 3.3V | Pull up rail of blower board| Source | This is the small perfboard I soldered to gether with pullup/pulldown reistors and then glued onto the DB25 PCB.
| GND |	Pull down rail and GND of blower board |Sink|	Please see the Fritzing Diagram of this breakout board: https://github.com/PubInv/NASA-COG/blob/develop/fancontroller/SanyoAceBreakout.fzz
| GND | | Sink | |			Digital Power Supply TF800 Pin 22
| GND |

Notes: 			
Most components require a GND rail. There are three of them on the DUE. I have tied the all of these to GND.			
The GND rail is tied to the GND of the 12V (fixed) power supply, which is also tied to the GND bus bar.			
Pin Signal Names are constant, all upper case. 			
Leading "n" indicated active low naming convention			

## Digitaly controled Power Supply				
Note: The DPS connections are particularly delicate in the OEDCS SN#1.				
Two signal wires and one GND wire are used. Jumper wires are plugged into a female connector which is plugged into the power supply. 				
The numbering of this power supply is a little tricky. Please see the datasheet: [https://assets.alliedelec.com/v1560852133/Datasheets/1d230174086e96b6e4801d1c963649f3.pdf](https://assets.alliedelec.com/v1560852133/Datasheets/1d230174086e96b6e4801d1c963649f3.pdf)			
In additon to the GND wire, the DUE's Serial1 interface is used. This is pins 19(RX) and 18(TX). 				
These are connected to Pins on the TF800:				

| TF800 Signal Name  | 	TF800 PIN  | Due PIN  | Due Signal Name  |
|---|---|---|---|
| TX|	24|	19|	RX|	
|RX |	23|	18|	TX|	
|GND|	22|	GND|	GND|

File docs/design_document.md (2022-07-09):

# Design Document
## Public Invention OxyCon

### 1.0 Design Specification

The Public Invention OxyCon aims to meet or exceed the WHO specification for oxygen concentrators [1]. OxyCon is intended for use in remote communities with little access to medical resources and basic infrastructure.

#### 1.1 Functional
1. Deliver medical grade oxygen at 90% O2 concentration or greater at a flow rate of 20LPM or greater.
1. Meets FDA safety regulations for design.
1. Documentation completed sufficiently for a 3rd party to manufacture.
1. Can be manufactured with common engineering tools such as those found in a car mechanics workshop - drill press, lathe etc.
1. Can be made from local resources using local labor.
1. Multi-lingual touch screen interface.
1. Operate in field hospital conditions - hot, humid and/or dusty.
1. Minimum maintenance required - ideally 6+ months between servicing.
1. Tool-less servicing.
1. Uses external air supply of 50-100PSI at 200LPM.
1. Clean, dry and filter the air to provide medical grade air from a standard workshop-type pneumatic ring main.
1. Easy to transport.
1. Sound level less than 40dB at 1m (WHO suggests 60dB).
1. Battery backup power supply for 20 minutes.
1.
#### 1.2 Performance
1. Flow rate shall be +- 5% of the target value.
1. Pressure shall be +- 5% of the target value.
1. Oxygen concentration shall be += 3% of the target value.
1. No more than 70W electrical power is to be consumed per LPM of oxygen delivered.
1. Operational temperature 0-50 degrees Celcius.
1. Operational humidity 0-95% humidity.
#### 1.3 Usability
1. Multi-language UI
1. Graphics display with language agnostic design
#### 1.4 Materials
1. Biocompatability
1. Flammability
1. Standards compliance.
#### 1.5 Electrical
1. 110-240V 50Hz electrical input.
1. Must be able to handle electrical spike up to 480V.
#### 1.6 Manufacturing
1. Can be assembled from components that are sourced and shipped internationally.
1. Large components shall able to be manufactured in a car mechanics workshop or engineering workshop with local skills.
1. Standards compliance.
#### 1.7 Servicing
1. Instructional maintenance process on labels inside device and on interactive walk-through on touch screen
1. Consider Android app to support servicing model
#### 1.8 Documentation
1. Documentation to be completed per Quality Plan.
#### 1.9 Standards
1. Insert relevant standards.
#### 2.0 Regulatory
#### 2.1 Relevant Standards
1. Regulatory requirements

#### 2.2 Failure Mode and Effects Analysis

#### 2.3 Risk Management

### 3.0 Literature Review
#### 3.1 Open Source Projects
- Project Apollo
- Enaccess Open O2
- OxiKit
- Zurich ETH

#### 3.2 Commercial Units

#### 3.3 Processing Methods
##### 3.3.1 Pressure Swing Adsorption

##### 3.3.2 Membrane Filtration

### 4.0 User Needs Research

### 5.0 Concept Design

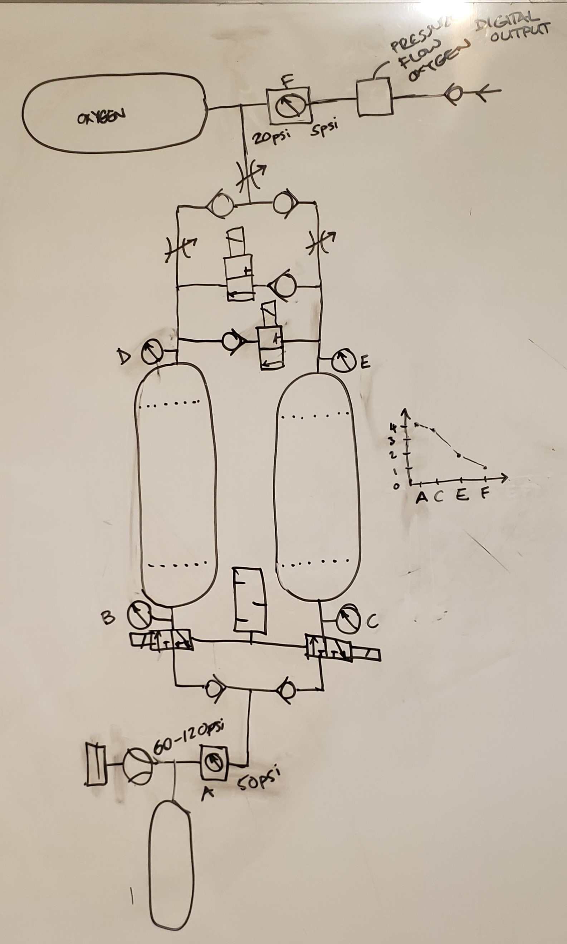
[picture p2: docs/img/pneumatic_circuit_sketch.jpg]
sketch


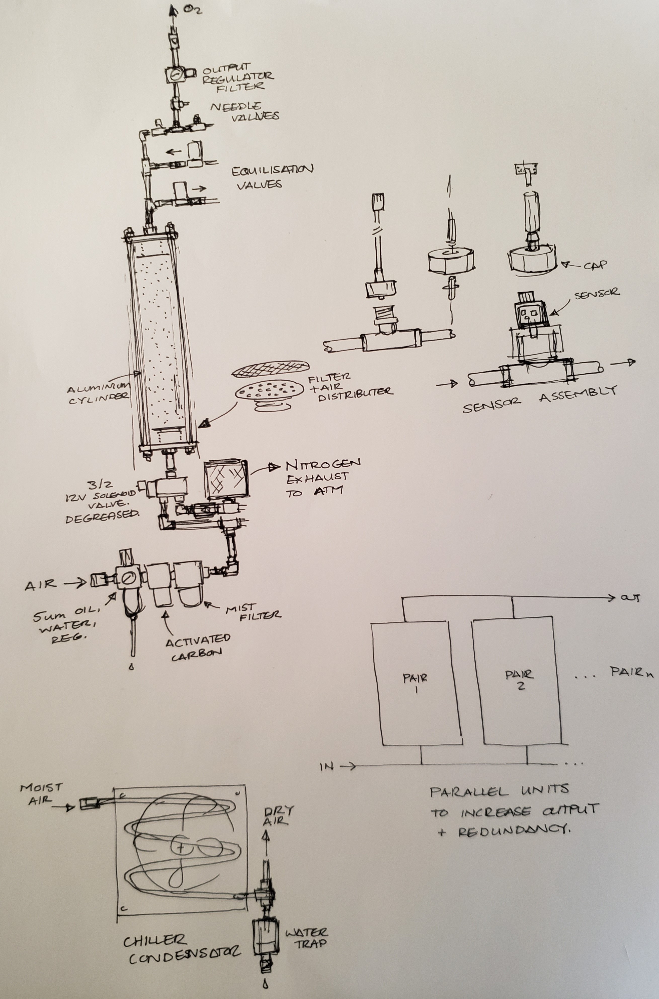
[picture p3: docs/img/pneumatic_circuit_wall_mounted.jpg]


### 6.0 Prototyping
#### 6.1 Requirements

#### 6.2 First Protoype
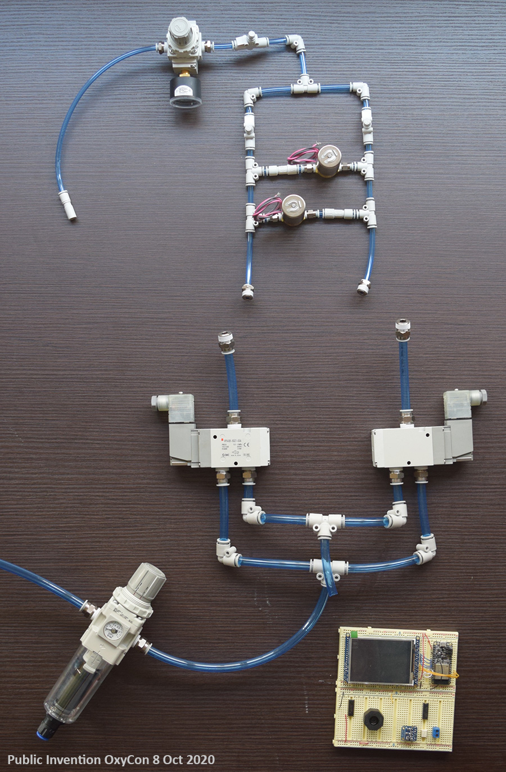
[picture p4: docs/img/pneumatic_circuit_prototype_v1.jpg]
OxyCon Pneumatic Circuit Prototype


### 7.0 Software Architecture
#### 7.1 Overview
RTOS
Timing requirements
Logging
Connectivity
Security
Libraries
### 8.0 Electrical
#### 8.1 Architecture

### References

1. COVID-19 Technical specifications for procurement of oxygen therapy and monitoring devices. 2015. World Health Organization. https://www.who.int/medical_devices/publications/tech_specs_oxygen-concentrators/en/

2. Technical Specifications for Oxygen Concentrators. World Health Organization.

To organise:
https://www.who.int/medical_devices/management_use/mde_tech_spec/en/

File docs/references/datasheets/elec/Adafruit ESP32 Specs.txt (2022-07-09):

240 MHz dual core Tensilica LX6 microcontroller with 600 DMIPS
Integrated 520 KB SRAM
Integrated 802.11b/g/n HT40 Wi-Fi transceiver, baseband, stack and LWIP
Integrated dual mode Bluetooth (classic and BLE)
4 MByte flash
On-board PCB antenna
Ultra-low noise analog amplifier
Hall sensor
10x capacitive touch interface
32 kHz crystal oscillator
3 x UARTs (only two are configured by default in the Feather Arduino IDE support, one UART is used for bootloading/debug)
3 x SPI (only one is configured by default in the Feather Arduino IDE support)
2 x I2C (only one is configured by default in the Feather Arduino IDE support)
12 x ADC input channels
2 x I2S Audio
2 x DAC
PWM/timer input/output available on every GPIO pin
OpenOCD debug interface with 32 kB TRAX buffer
SDIO main/secondary 50 MHz
SD-card interface support

https://learn.adafruit.com/adafruit-huzzah32-esp32-feather/overview
https://www.espressif.com/en/products/socs/esp32

// ADAFRUIT FEATHER ESP32
// 1 RST
// 2 3V
// 3 NC
// 4 GND
// 5 A0     BATT
// 6 A1     EN
// 7 A2     USB
// 8 A3     13 A12
// 9 A4     12 A11
// 10 A5    27 A10
// 11 SCK   33 A9
// 12 MO    15 A8
// 13 MI    32 A7
// 14 RX    14 A6
// 15 TX    SCL 22
// 16 21    SDA 23

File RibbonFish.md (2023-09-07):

# RibbonFish Proof-of-Concept

Using the principle of Agile development, we are building a quick-dirty proof-of-concept codenamed RibbonFish.

The RibbonFish is a low-temperature (less than 100C) model consisting of two heating cloths and 12V fan, controlled with three simple thermocouples.
Although weak compared to the goal-product, this allows us to exercise much of the functionality that we will
eventually need.

## Hardware Choices

Because the RibbonFish is a real machine, it forces us to make hardware pin choices for the Arduino to
control the 6 hardware electronic devices. These choices are documented here to allow duplication
of the device; the hardware choices (GPIO pins) must match the software configuration.

1. The thermocouples are DS18B20 Temperatures sensors purchased from Adafruit, and configured using the [OneWire digial
protocal](https://learn.adafruit.com/adafruits-raspberry-pi-lesson-11-ds18b20-temperature-sensing/ds18b20) We use Digial Pin 2 as the signal pin for this.
3. The Fan and Heaters #1 and #2  are controlled via PWM (ranging from 0-12V.) The pins are: Fan = PIN 3, Heater #1 (Preheater) = PIN 4, Heater #2 (stack simulation) = PIN 5

The Fan is a simple DC 12 Vote Fan that fits inside a 4" PVC pipe. The heaters are Adafruit 4" x 5"  heating cloths, around 1 ohm each.

Note: We do not believe an unfiltered PWM signal is appropriate for the actual chemical stacks due to internal chemistry,
or at least this has not yet been tested. However, as a prelude to a real system, PWM can be used with the heating cloth
using simple power transistors.

## Photo of the RibbonFish

The Ribbon Fish consists of a PVC vent fan (12V, inline) connected via a heavy paper cone to piece of 3/4" PVC piping.
There are 3 such pipe sgements, each about 16mm long. These each have a 1/4" hole for the temeperature sensor in the middle.
In the two joints between the three pipes, a heating cloth is rolled up into a cylinder and inserted into both pipes.
The leads are exposed to power the heating cloths.



## Libraries

PlatformIO provides useful package and configuration management, but
it still requires thought and documentation.

We believe teh DS18B20 thermometers require these libraries

> pio lib install paulstoffregen/OneWire
> pio lib install milesburton/DallasTemperature

## Simple Commands for the RibbonFish

In order to continue moving to more versimilitude, we need to implement a serial-port based
command structure within the RibbonFish.  Without being ready to specify everything,
let me describe a few commands.

### Parameter Commands

The first commands for the Ribbon Fish are:

1. W - Warmup
2. C - Cool Down
3. Set exhuast temperature than (first or second) heater
4. Set the speed of the fan

The command set the target temperatures for the first and second heater
```JavaScript
{ "com": "T",
  "par": 0,
  "mod": "T",
  "val" : 34.3
  }
```

```JavaScript
{ "com": "T",
  "par": 1,
  "mod": "T",
  "val" : 36.0
  }
```

This command says enter the cool down mode:
```JavaScript
{ "com": "C",
  "par": 0,
  "mod": "U",
  "val" : 0.0
  }
```

This command says enter the warm up mode:
```JavaScript
{ "com": "W",
  "par": 0,
  "mod": "U",
  "val" : 0.0
  }
```

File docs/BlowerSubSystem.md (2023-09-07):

We are currently using the SanyoAceB97 blower.

The best documentation of this is: [https://docs.rs-online.com/1c09/0900766b816e68bb.pdf](https://docs.rs-online.com/1c09/0900766b816e68bb.pdf).

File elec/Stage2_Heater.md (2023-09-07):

# Due CFC Pinouts

This document describes the pinouts for the Stage 2 heater

| Due Pin Number  | 	Signal Name  | Set as I/O  | Connection  |  Notes |
|---|---|---|---|---|
| A0 |	FAN1_FG | Input | Blower 1 Tachometer
| D4 |	TEMP1	| BIDirect |	Dallas One-Wire connection to Thermocouple Breakouts |	Daisy chain connection to temprature probes. Address of ??? and conflicts with D4: SD card chip select on Ethernet sheild 
| D9 | nFAN1_PWM | Output | Blower PWM | This output will be inverted
| D18 |	TX1 | Output |	Digital Power Supply TF800 Pin 23 | This is Serial1 TX for (power supply)[https://assets.alliedelec.com/v1560852133/Datasheets/1d230174086e96b6e4801d1c963649f3.pdf]
| D19 | RX1 |Input | Digital Power Supply TF800 Pin 24 | This is Serial1 RX for (power supply) [https://assets.alliedelec.com/v1560852133/Datasheets/1d230174086e96b6e4801d1c963649f3.pdf]
| D22 | BLOWER_ENABLE |Output |	Blower Enable 
| D32 | GPAD_nCS | Output |	 External SPI inverted select (for the GPAD)
| D44 |LPBK0 |Output |	Varying loopback signal
| D45 |LPBK1 |Input |	Read of digital loopback signal
| D51 |HEAT1 |Output |	Positive SSR signal for Internal Heater
| D50 |HEAT2 |Output |	Positive SSR signal for External Heater 1
| D49 |HEAT3 |Output |	Positive SSR signal for External Heater 2
| 3.3V | Pull up rail of blower board| Source | This is the small perfboard I soldered to gether with pullup/pulldown reistors and then glued onto the DB25 PCB.
| GND |	Pull down rail and GND of blower board |Sink|	Please see the Fritzing Diagram of this breakout board: https://github.com/PubInv/NASA-COG/blob/develop/fancontroller/SanyoAceBreakout.fzz
| GND | | Sink | |			Digital Power Supply TF800 Pin 22
| D10 | SD_CD | Pull up |	Pull Up for SD carde detect | D10: W5200 Chip Select conflict
| D24 | BTN_2 | Pull Up |	Pull up for EncoderB
| D40 | BTN_1 | Pull Up |	Pull up for EncoderA
| D39 | BTN_ENC | Pull Up |	Pull up for Encoder push button
| D48 | LCD_SS | Output |	Signal Select for LCD SPI
| D47 | MOSI | Output |	SPI MOSI signal | D11: SPI MOSI Ethernet Shield(conflict needs resolution)
| D2 | MISO | Output |	SPI MISO signal and DO signal | D12: SPI MISO Ethernet Shield (conflict needs resolution)
| D8 | CLK | Output |	SPI Clock signal | D13: SPI SCK Ethernet shield (conflict needs resolution)
| D38 | LCD_CS | Output |	SPI LCD Chip Select signal LCD_EN
| D31 | LCD_A0 | Output |	SPI LCD A0 RS signal 
| D53 | LCD_LED_Blue | Output |	LED Enable High On
| D37 | LCD_LED_Red | Output |	LED Enable High On
| D23 | LCD_LED_Green | Output |	LED Enable High On
| D30 | LCD_BEEP | Output |	Buzzer Enable High On
| D3 | TC_1_CS | Output |	SPI TC_1 Chip Select signal
| D29 | TC_2_CS | Output |	SPI TC_2 Chip Select signal
| D28 | TC_3_CS | Output |	SPI TC_3 Chip Select signal
| D46 | LCD_RST | Input |	Reset pin, could be left unconnected also indicates LCD present
| RST | KILL / RST | INPUT |	Pull Down reset pin, with external 10k pull up resistor and filter capacitor 0.1uF
| D3 | TC_1_CS | Output |	SPI TC_1 Chip Select signal

Notes: 			
Most components require a GND rail. There are three of them on the DUE. I have tied the all of these to GND.			
The GND rail is tied to the GND of the 12V (fixed) power supply, which is NOT tied to the GND bus bar.			
Pin Signal Names are constant, all upper case. 			
Leading "n" indicated active low naming convention

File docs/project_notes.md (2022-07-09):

# Project Status

[Download](docs/PubInvCon2021.pdf) the PIOC presentation from PubInvCon 2021!

**2 February 2021**

Development of an test rig has been underway. Unfortunately the pressure sensors originally intended for this purpose were not easy to prototype with which has caused delays. New sensors have been identified for testing, along with additional gas sensors to gain further insight into the process. After much research PCB design for the PIOC will be starting this month.

**10 January 2021**

PIOC was taken apart to diagnose issues in the previous iteration.

During testing the spool valves started to stick. They were disassembled which revealed significant zeolite contamination! The valves were cleaned and reassembled. An attempt to use the valves without lubrication was unsuccessful so a thin coat of silicone oil was used to lubricate the spools. The spool valves will be replaced with poppet valves in the next iteration.

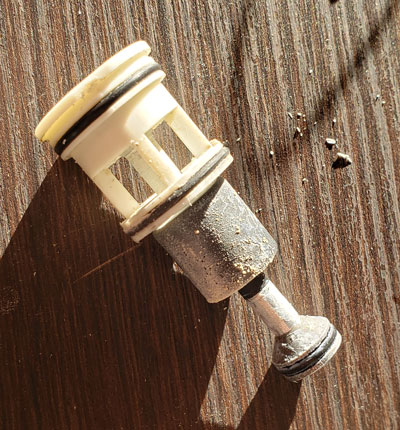
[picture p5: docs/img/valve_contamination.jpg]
valve-contamination


A compact and low-cost intercooler was built from 1 meter (3 feet) of copper gas pipe and a 120mm 12V fan. The surface area of the copper that is exposed to the fan was maximized using a spiral shape. Droplets of water were observed after the intercooler which demonstrates that the water vapour is still present after the coalescing filter. The water is directed into a reservoir with a 2/2 valve on the end - this should be replaced with an automatic drain in the future to minimize maintenance.

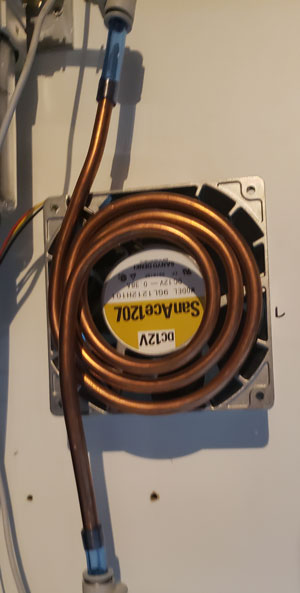
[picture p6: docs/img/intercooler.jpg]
intercooler


Various configurations of the equalizing valve have been tried and the low pressure of the circuit may allow for the 2 brass valves to be reduced to 1.

A power issue was encountered with the 12V power regulator which needs further investigation. Space for 2 additional valves has also been added to the circuit board.

Some small improvements have been made to the tanks; one end of the threaded rods is fixed to one end-plate to allow for easier assembly/disassembly, push-fit connections are being tested and a new filter design is being tested which uses a fine stainless steel mesh and improved foam filters to filter out the zeolite dust.

The latest build is shown below:

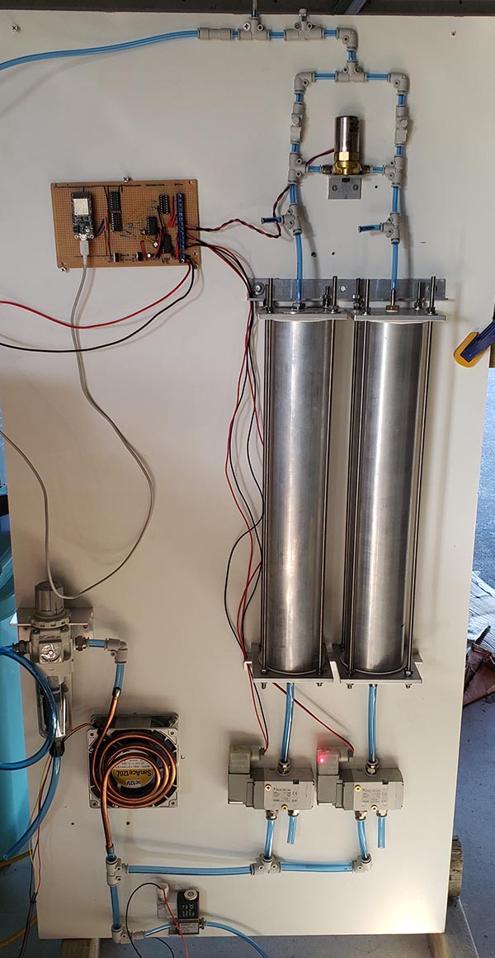
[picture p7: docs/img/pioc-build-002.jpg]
build-004


**1 November 2020**

It's alive! Running for the first time PIOC reached 95% O2! VentMon is being used to monitor the O2 output, pressure and flowrate. Unfortunately the single stage water filter let enough water vapour past that after a few hours the concentration dropped to 35% - the water separator was half full with a small puddle underneath it. PIOC has been made by hand without much effort to be exacting as to test the idea of manufacturing in an automotive or small engineering workshop - tolerances are +-millimeters not fractions of a millimeter. Next steps are to dry out the zeolite and build a simple chiller and desiccant drier to remove any excess water vapour - some digital pressure sensors will then be installed to tune the system and test various configurations.

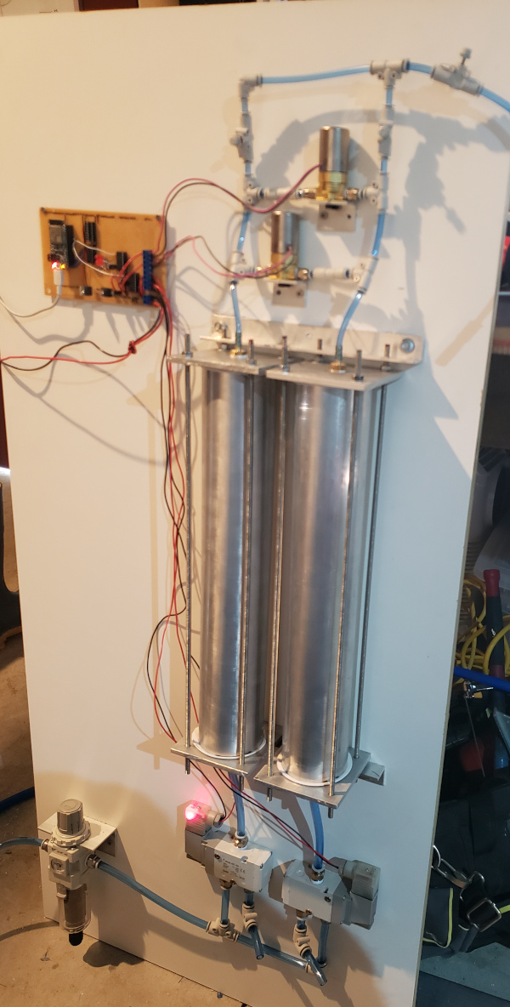
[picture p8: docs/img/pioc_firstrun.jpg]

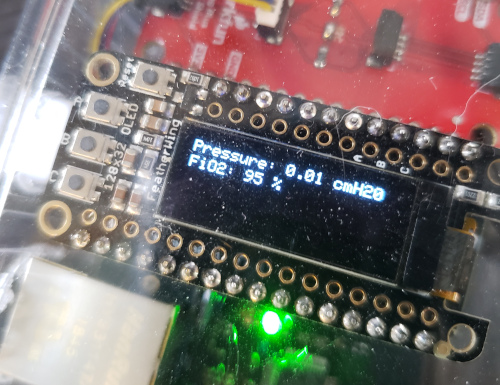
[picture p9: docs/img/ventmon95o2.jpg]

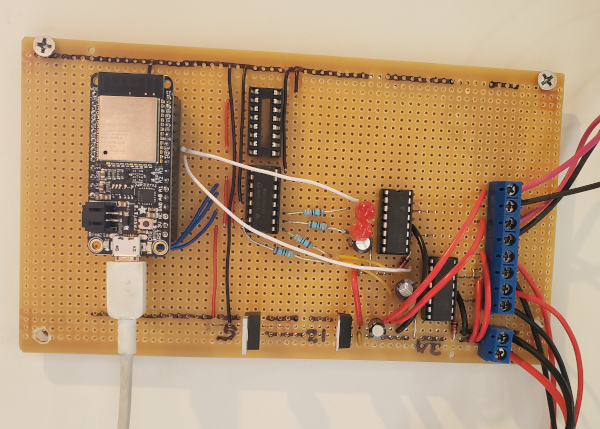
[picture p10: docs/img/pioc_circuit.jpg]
build-003


**22 October 2020**

The system is now mounted to the board! Some changes have been made during the build to simplify it - the sieves now use 1/4" NPT barb fittings as a step towards making an all metal "sealed for life" sieve that can be heated to 300C to regenerate the zeolite without opening the sieves. Standardizing the end plates also helps to make manufacturing easier and remove the need to drill and tap 3/8" BSPT which is costly and requires a drill press. The pneumatic circuit has been modified to shorten the overall height. The valves have been tested manually and the overall operation appears to be correct. Next steps are to finish the driver circuits and fill the sieves.

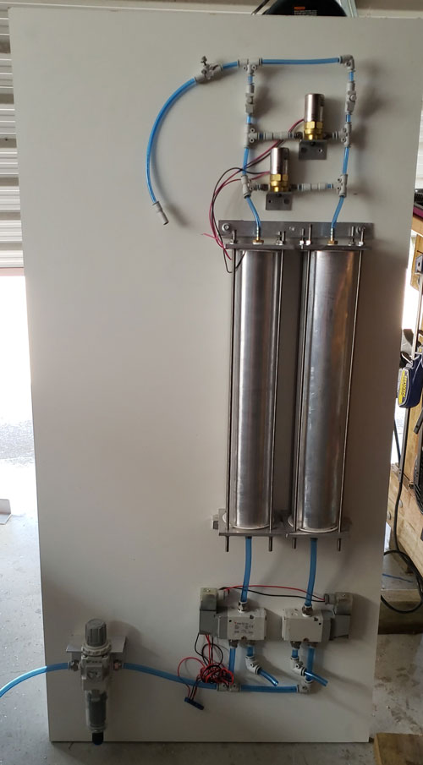
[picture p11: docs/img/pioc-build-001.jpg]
build-001


**19 October 2020**

First build is almost ready for testing! Parts of the system have been tested independently. Next is to complete assembly for a full pressure test. Then fill the sieves with zeolite and start tuning the control system.

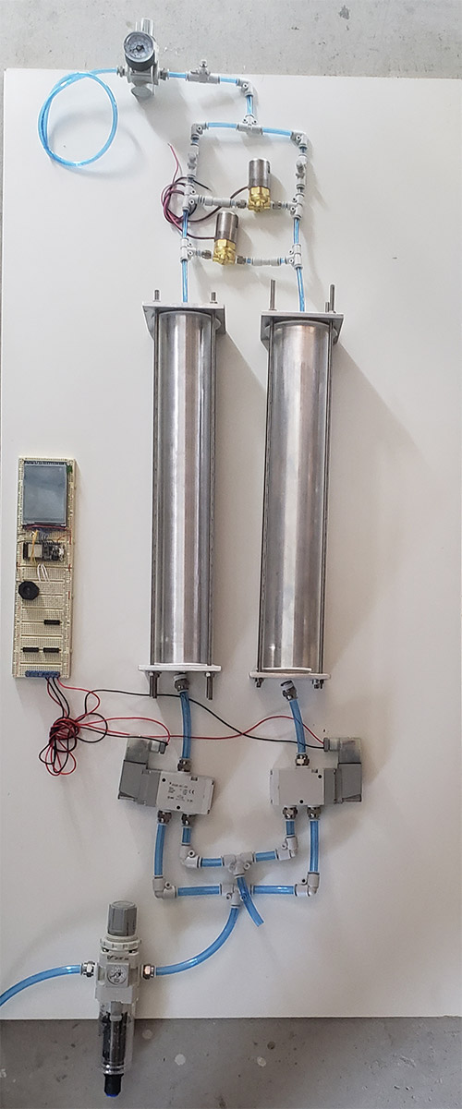
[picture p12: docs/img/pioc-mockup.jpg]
mockup


## Project Structure

Please see subdirectories for relevant files and documentation.

## Thanks

Many thanks to [Project Apollo](https://github.com/oxycon/ProjectApollo), [Helpful Engineering](https://helpfulengineering.org/) and [EnAccess OpenO2](https://enaccess.org/projects/openo2/) for their ongoing collaboration.

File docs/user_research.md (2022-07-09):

# Design Document
## Public Invention Oxygen Concentrator

### 1.0 User Needs Research

User research has been collected from the community at www.helpfulengineering.org, www.pubinv.org and one-on-one interviews.

#### 1.1 Countries

##### 1.1.1. Kenya

- Currently locally distributing oxygen cylinders from bottling facilities.
- Difficulty tracking and distributing oxygen cylinders due to theft.
- Difficulty purchasing and importing large shipments of medical aid.
- Low financial and technical resources.
- Lack of trained medical staff.
- Lack of basic medical facilities.

##### 1.1.2. Guatemala
- Lack of basic resources such as water and staff

##### 1.1.3. Afghanistan
- Home care patients currently take oxygen cylinders to fill stations.
- Cylinders cost of $200USD each, which is expensive for average citizen.
- Currently ~1500 cylinders per day in the entire country, 1 patient needs 4 cylinder per day 5-6 days
- People present to specialist hospitals at late stages (stigma), now 42 hospitals (none have central O2 supply), level of reliability of skillset poor - high fatalities
- Infection rates are very high
- What equipment?
- Cost?
- How would we use it?
- What concentration or level of O2 will they supply?
- What mechanism can we use to intro the tech into the country?
- Two approaches - central facilities for hospitals (20 person ward) or individual CPAP
- Cryogenic facilities - fill tanks, fill cryo tanks, industrial, not practical for rural areas
(estimates of 1 metric tonne for 20 beds per day)
- Pressure swing/membrane technology - these consume a lot of power
- Secure power supply or allow intermittent power supply
- Containerised high pressure cylinders - backup
- Specify power supply, geography, size of institution
- Afghanistan hospital (Kabul - dedicated 75 beds for COVID) 100 beds in another, most vary between 20-50 beds or smaller in provincial
- bring your own cylinder ($250 per cylinder, $7 per fill)
- oxygen is industrial grade not medical grade (possibly affecting level of treatment)
- what regulatory standards do we have to meet? Perhaps none - little but requests for proposals may reference international standards.
- Current: is industrial O2 with no oversight.
- Cost proportionate to level of standard of filter (perhaps target somewhere midway)
- Hospitals - 10-20 beds up to 2,3-400 beds
- Hospitals in provinces (~50)
- Maybe target 20 people
- Oxygen balloon
- Don't speak English, understand content etc. eg. they don't understand error messages
- Price point needs to be competitive.
- Bring in finished items attract customs duties
- How much can you produce in-country?
- What are the costs? Long, short term viability
- 15-20L/min for high flow oxygen therapy
- 1-3 day period with supplemental oxygen. 10-15PLM high flow oxygen.
- Goal is keep people out of hospitals.

##### 1.1.4. Indonesia
- High temperatures and humidity
- Demand but no research has been conducted by open source teams

##### 1.1.5. India
- High temperatures
- Manufacturing capacity
- Engineering capacity
- Challenges of rural locations, infrastructure, training remain

##### 1.1.6 Nepal
- Power supply spikes and interuptions
- Language barriers
- Lack of infrastructure
- Floors are not flat
- Car battery might be used
- Dust on the floor gets sucked into ground level intakes; put the units on stands/tables
- Long life ceramic bearing fans
- Modular components that are easy to replace (plug and play)
- Humidity causes mold build up on HEPA filters

#### 1.2 Proposed Generic Solution

The proposed generic solution is to mail essential components such as the electronics, valves and zeolite. The larger and heavier materials such as aluminum plates and cylinders can be sourced locally and manufactured using basic workshop tools such as drill presses and lathes - simple 3 axis CNC machining could be used in countries with the capability to manufacture at scale.

The proposed design connects to a standard engineering workshop-style pneumatic ring main. It is assumed that a locally sourced compressor will be used to supply a group of oxygen concentrators - this is likely to be a diesel compressor from a local mechanic or engineering workshop. This will save shipping the heaviest component, the oil-less compressor, from overseas suppliers - these compressors also draw a lot of power which creates a fire risk with poor electrical infrastructure.

An industrial compressor will not be oil-less, as such the air must first be filtered to become medical grade air, before the oxygen concentration process begins. Modular air filtration units are proposed to be flexible to the users needs - these could be per unit or per group of units. The assumption is a filter setup will be more compact, lighter to ship and be more robust and long lasting compared to compressors.

The electrical demand must be low and adapt to a wide range of voltages, from a 12V car battery to a 480V power spike. Electricity is not a given and availability is irregular. Therefore the electronics and valves should work at 12V.

The shipped device must be lightweight and compact to minimize the burden on logistics.

The device must be robust to survive the supply chain, including bumpy roads and being dropped from trucks.

A multi-lingual touch screen with a visual interface that uses icons and language agnostic visual design to communicate visually to the end user. Touch screen must be robust. The only other UI component is a power on/off switch.

Maintenance periods must be as long as possible, with tool-less servicing and frequently used spare parts included within the device, eg. washers, fuses etc.

#### 1.3 Questions Remaining

1. What is the flow rate required? Indications of flow rate of 5, 10, 15 and 20LPM as the target. 20LPM is the target for this device, although this could be as low as 5LPM for a portable 12V at-home device, or multiple 100LPM+ units for a small clinic. Currently keeping the design flexible to accomodate changing user needs.
2. What is the FiO2 required? Current target is minimium 90% O2, ideally 95% O2. Costs raise disproportionally beyond 95% O2 as further steps to remove Argon are required.
3. What is the distribution mechanism of the devices? Carried by hand, bicycles, cars, trucks?
4. What are the local manufacturing capabilities? Currently assumed to be a car mechanics workshop, up to basic engineering facilities to service local industries.
5. Some countries could have great capabilities for production at scale, for example India. What are these capacities? Potential for partnerships?
6. What local universities and governing bodies could support local research and development of the proposed generic design?
7. How would local manufacture and testing work in practice? Keeping in mind the need for 'clean room' conditions.
8. Our current best research indicates the need for a bedside unit connected to a remote air supply providing 20LPM for high flow nasal canular oxygen therapy. This needs to be confirmed as medically impactful.
9. Demand for oxygen concentrators for invasive ventilation has not been analysed.
10. What documentation would need to be produced for local health authorities? Currently working to FDA requirements.
11. What languages would the documentation need to be translated to?
12. What manufacturing guides would be required? Can paper or 3D printed jigs/templates be made and distributed to aid manufacturing?
13. What bureaucratic and security concerns are there? Large containers may be held up at customs and are targets for theft.
14. How would servicing work? What service facilities or training is required for maintenance of the devices?
15. What is the demand for rural care vs hospital care? Stigma and population distrition creates rural demand, however hospitals have better infrastructure, staff and presumably shorter distance to engineering workshops.
16. What is the current state of the electrical wiring in the hospital and the load that can be placed on it?
17. How can we make the cost competitive with existing solutions?
18. How can we overcome stigma? What local words, symbols, colors are taboo and should be avoided in our design?
19. What international manufacturers need to be contacted? Multiple vendors have been identified and outreach has begun to supply electronics, valves and zeolite.
20. What local manufacturers, assemblers, service agents need to be contacted?

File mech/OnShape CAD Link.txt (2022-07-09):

View the latest OnShape CAD design here:

https://cad.onshape.com/documents/c00f6fd6678c69ef9431de94/w/14a281098703d7aa957a6ca3/e/0b25edb21b265ac0a5709a8b

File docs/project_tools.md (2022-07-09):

# Project Tools

All of the following tools are available on Mac OS, Linux and Windows for free, or have free licenses for open source projects.

GitHub is used for version control and collaboration. https://github.com/

VSCode is used to edit text files and code - or use your favorite text editor.  https://code.visualstudio.com/

PlatformIO is used for C/C++ firmware development and Unit Testing. https://platformio.org/

Python 3 is used for scripting and modelling. https://www.python.org/

Jupyter Notebooks are useful for organising Python code, math and notes. https://jupyter.org/

EAGLE is used for electronic CAD. https://www.autodesk.com/products/eagle/overview

Fusion 360 is used for mechanical CAD. https://www.autodesk.com/products/fusion-360/personal

Libre Office is used for general engineering calcs and diagrams. https://www.libreoffice.org/

Markdown is used for text documentation. https://www.markdownguide.org/

LaTeX is used for scientific papers. https://www.latex-project.org/

GIMP is used for image editing. https://www.gimp.org/

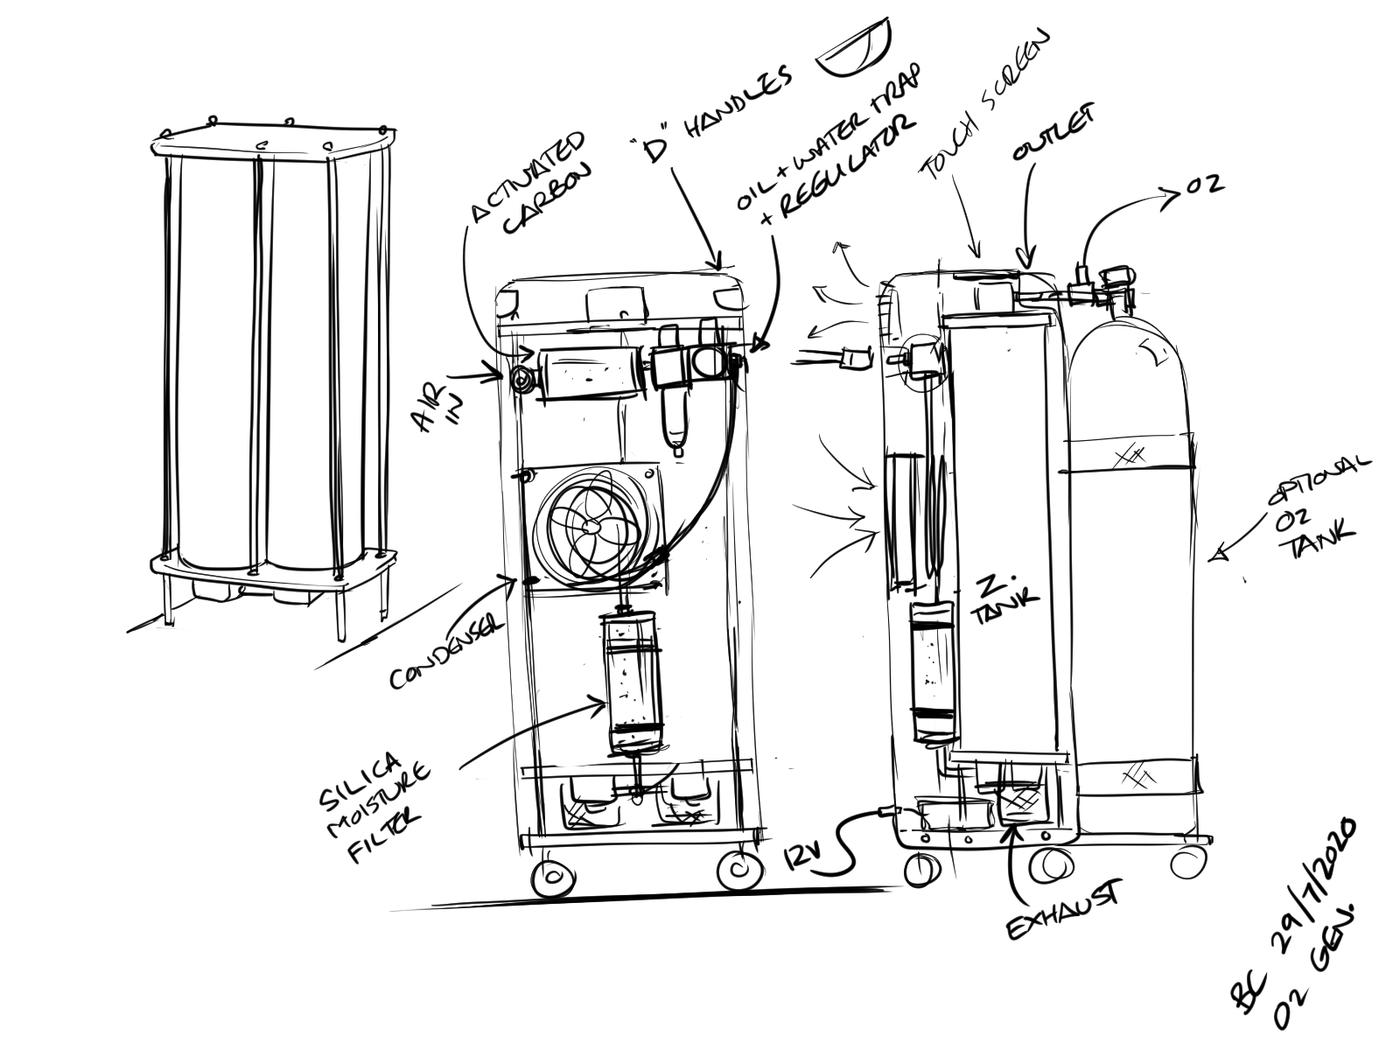
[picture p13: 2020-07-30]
docs/img/concept_sketch.jpg

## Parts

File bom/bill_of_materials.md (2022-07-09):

# Bill of Materials

## Mechanical 

| Name | Description | Supplier | Part Number | Quantity |
| --- | --- | --- | --- | --- |
| Pressure vessel cylinder wall | 2 x 70 x 500mm | | | 2 |
| Pressure vessel end cap | 100 x 100 x 6mm | | | 4 |
| Pressure vessel threaded rod | M6 x 550mm | | | 8 |
| Nuts | M6 | | | 16 |
| Flat washers | M6 | | | 16 |
| Spring washers | M6 | | | 16 |
| NPT push fitting | 1/4" x 8mm | | | 16 |
| NPT push fitting | 1/4" x 6mm | | | 16 |
| 2/3 solenoid valve | 24V | SMC | | 4 |
| 2/2 solenoid valve | 12V | SMC | | 2 |
| 2/2 proportional solenoid valve  | 12V | SMC | | 2 |
| Regulator, filter, drier | | SMC | | 1 |
| Muffler | | SMC | | 2 |

## Electrical

| Name | Description | Supplier | Part Number | Quantity |
| --- | --- | --- | --- | --- |
| | | | | |
| | | | | |
| | | | | |

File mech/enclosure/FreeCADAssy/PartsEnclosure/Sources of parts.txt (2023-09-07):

20x20x100 extrustions from 
https://grabcad.com/library/aluminium-extrusion-20x20-1

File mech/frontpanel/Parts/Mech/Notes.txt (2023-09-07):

Origin of models:

https://grabcad.com/library/extrusion-profile-20x20mm-1

https://grabcad.com/library/2020-extrusion-corner-bracket-1

https://grabcad.com/library/aluminium-corner-bracket-2028-1

https://grabcad.com/library/mpj-j-f-thermocouple-connector-omega-1

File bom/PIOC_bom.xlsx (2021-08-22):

License Info for this sheet: | CC0 Public Domain License | https://creativecommons.org/publicdomain/zero/1.0/
Manufacturer | Mfr Part Number | Supplier | Supplier Part Number | Part Description | Unit | Qty | Unit Price (USD) | Total Price (USD) | Notes
Adafruit | 3405 | Mouser | 485-3405 | HUZZAH32 - ESP32 Feather Board | each | 2 | $19.95 | $39.90
Arduino | ABX00027 | Mouser | 782-ABX00027 | ARM Arduino Nano 33 IoT | each | 2 | $20.25 | $40.50
Adafruit | 2652 | Mouser | 485-2652 | BME280 Temp Humidity Press | each | 2 | $19.95 | $39.90
Honeywell | MPRLS0025PA00001AB | Mouser | 785-MPRLS25PA00001AB | Breakout board with 0 psi to 25 psi absolute sensor, long port, with gel, SPI | each | 2 | $15.00 | $30.00
Honeywell | ABP2LSNT060PG2A3XX | Mouser | 785-P2LSNT060PG2A3XX | Board Mount Pressure Sensors BASIC PRESSURE 60PSI GAU SMT | each | 6 | $11.98 | $71.88
Honeywell | ABP2LANT150PG2A3XX | Mouser | 785-P2LANT150PG2A3XX | Board Mount Pressure Sensors BASIC PRESSURE 150PSI GAU SMT | each | 2 | $11.98 | $23.96
Adafruit | 2478 | Mouser | 485-2478 | Adafruit 2.4 TFT LCD with Touchscreen Breakout w/MicroSD Socket – ILI9341 | each | 0 | $27.50 | $0.00
Adafruit | 1743 | Mouser | 485-1743 | 3.2 TFT LCD with Touchscreen Breakout Board w/MicroSD Socket - ILI9341 | each | 2 | $29.95 | $59.90
Artesyn Embedded Technologies | DA10-050AU-M | Mouser | 826-DA10-050AU-M | Wall Mount AC Adapters 10W 5V 2A 2.5mm DC AU AC Contacts | each | 2 | $13.16 | $26.32
CUI Inc. | SMM30-24-K-P5 | Mouser | 490-SMM30-24-K-P5 | Wall Mount AC Adapters ac-dc, 24 Vdc, 1.5 A, SW, multi-blade, no blades, P5 center pos, level VI, MED | each | 2 | $20.63 | $41.26
Mallory Sonalert | MSS5M0 | Mouser | 539-MSS5M0 | Speakers & Transducers IEC ALARM 4-6VDC 90DB CONTINUOUS | each | 2 | $12.41 | $24.82
Mallory Sonalert | MSS5MMG | Mouser | 539-MSS5MMG | Speakers & Transducers IEC SPKR ALARM 90DB GENERAL | each | 0 | $22.86 | $0.00
Toshiba | TB67S112PG,HJ | Mouser | 757-TB67S112PGHJ | Motor/Motion/Ignition Controllers & Drivers 50V 1.5A DIP16 2-n-1 Solenoid Drive | each | 6 | $2.36 | $14.16
ON Semiconductor / Fairchild | 1N4758A | Mouser | 512-1N4758A | 56V 1W Zener diode | each | 10 | $0.25 | $2.50
Welwyn Components / TT Electronics | MFR3-10KFC | Mouser | 756-MFR3-10KFC | 10k 0.4W Resistor | each | 10 | $0.10 | $1.00
United Chemi-Con | ELE-500ELL470MF11D | Mouser | 661-E-500L470MF11D | 47uF 50V capacitor | each | 10 | $0.29 | $2.90
Nichicon | UVR2A0R1MDD1TA | Mouser | 647-UVR2A0R1MDD1TA | 0.1uF 100V Capacitor | each | 10 | $0.16 | $1.60
Sanyo Denki | 9GL1212H101 | Mouser | 978-9GL1212H101 | DC Fan, 120x38mm, 12VDC, 4.56W Long Life, High Performance, Ribless, Tachometer | each | 2 | $25.83 | $51.66
STMicroelectronics | L7812CV | Mouser | 511-L7812CV | Linear Voltage Regulators 12V 1.5A Positive | each | 4 | $0.45 | $1.80
Texas Instruments | LM7805CT/NOPB | Mouser | 926-LM7805CT/NOPB | Linear Voltage Regulators 5 Volt Reg | each | 4 | $1.54 | $6.16
AVX | SR125C104KAATR1 | Mouser | 581-SR125C104KAATR1 | 0.1uF 50V Ceramic Capacitor | each | 10 | $0.74 | $7.40
AVX | AR205C224K4R3347 | Mouser | 581-AR205C224K4R3347 | .22uF 50V Ceramic Capacitor | each | 10 | $1.01 | $10.10
AVX | 581-SR215E334MARAP1 | Mouser | 581-SR215E334MARAP1 | .33uF 50V Ceramic Capacitor | each | 10 | $0.27 | $2.70
 |  |  |  |  |  |  |  | $500.42
Cubic |  | Cubic |  | O2/flow ultrasonic sensor combo unit (<10LPM) | each | 1 |  |  | Select if flow <= 10LPM
Cubic |  | Cubic |  | O2 ultrasonic sensor (>10LPM) | each | 1 |  |  | Select if flow > 10LPM
Sensiron |  |  |  | Flow sensor (>10LPM) | each | 1 |  |  | Select if flow > 10LPM
 |  |  |  | Clean Series https://www.smcworld.com/products/en/s.do?ca_id=561#rp
 |  |  |  | Moisture filter
 |  |  |  | Super Mist Separator AME (equivalent to oiless)
SMC |  | SMC |  | Oder Removal Separator AMF
SMC |  | SMC | LVMK20/200 | Direct Operated 2/3 Port Isolated Valve LVMK20/20
SMC |  | SMC | VDW | Compact Direct Operated 2 Port Solenoid Valve (2 Way Valve)
SMC |  | SMC | VXZ | Zero Differential Pressure Type/Pilot Operated 2 Port Solenoid Valve (2 Way Valve), 10mm- 1”
SMC |  | SMC | VXS | Zero Differential Pressure Type/Pilot Operated 2 Port Solenoid Valve (2 Way Valve) 1/4”-1” | each | 1
SMC |  | SMC | VXB | Angle Seat Valve (2 Way Valve)/Air Operated Type
SMC
 |  |  |  | SMC 5/3 Pneumatic Control Valve Pilot/Pilot G 1/4 SYA7000 Series
 |  |  |  | SMC 5/2 Pneumatic Control Valve Solenoid/Pilot G 1/4 SY7000
 |  |  |  | VUVG-L18-M52-MT-G14-1P3 solenoid valve
SMC JP |  | SMC |  | Pressure regulator | each | 1
 |  |  |  | Silencer/Compact Resin Type AN 30dB | each | 2
 |  |  |  | 3/8" NPT fittings | each
 |  |  |  | Pressure tubing, 10mm Polyurethane? | m
ZeoChem |  | ZeoChem |  | Zeolite Nax 13X 0.4mm (04-08) | kg | 12 |  | $200.00 | Shipping only for sample
Xintao |  | Xintao |  | Zeolite Nax 13X 0.4mm (04-08) | kg | 5 | $25.00 | $125.00
Xintao |  | Xintao |  | Zeolite LiX 0.4mm (04-08) | kg | 2 | $45.00 | $90.00
Xintao |  | Xintao |  | Alumina Silica | kg | 2 | $25.00 | $50.00
Xintao |  | Xintao |  | Silica Gel | kg | 2 | $25.00 | $50.00
Xintao |  | Xintao |  | Activated Carbon | kg | 2 | $25.00 | $50.00
 |  |  |  |  |  |  |  | $365.00
 |  |  |  | Sieve plunger filter | each
 |  |  |  | HEPA filter + housing | each
 |  |  |  | Bacterial filter + housing | each
 |  | Ulrich Aluminium | UA1658 | Aluminium tube 1.2x75 | m | 2 |  |  | NZD$136+gst per 5m, half length available
 |  | Ulrich Aluminium | UA1557 | Aluminium plate 6x150mm | m | 1 |  |  | NZD$332+gst per 5m, half length available
 |  | Bunnings |  | Threaded rod M6 | m | 3
 |  | Bunnings |  | Nuts M6 | each | 6
 |  | Bunnings |  | Zip ties | each
 |  | Bunnings |  | Cooling coil (copper) | each
 |  | RS-Components |  | 1.5mm Silicone gasket sheet | each | 1
 |  |  |  | Viton O-rings | each | 4
 |  |  |  | Stainless steel mesh 100 grade
 |  | 3D Printer Store NZ/Stratasys |  | Sieve plunger, PEEK, 3D printed for test | each | 4
 |  |  |  | Sieve plunger alternative, SS punched mesh
 |  |  |  | Sieve plunger spring, SS316, 50x50mm, 30kg? | each | 4
 |  |  |  | Body | each | 1
 |  |  |  | Chassis base plate, steel | each | 1
 |  |  |  | Castor wheels, rubber, 50mm | each | 4
 |  |  |  | Wheel fasteners | each | 16

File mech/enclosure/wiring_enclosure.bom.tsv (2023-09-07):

Id | Description | Qty | Unit | Designators
1 | Connector, Anderson Power SB50 SB, Dual, 4 pins | 4 |  | X3, X4, X5, X6
2 | Connector, Crimp ferrule, spade | 46
3 | Connector, D-Sub, male, 25 pins | 1 |  | X2
4 | Connector, D-Sub, male, 9 pins | 1 |  | X1
5 | Connector, JST PHDR-24VS, female, 24 pins | 1 |  | CN2
6 | Connector, jumpers, 42 pins | 1 |  | Arduino_Due
7 | Wire, 0.25 mm², BK | 1.0 | m | W2
8 | Wire, 0.25 mm², BN | 1.5 | m | W2
9 | Wire, 0.25 mm², BU | 1.0 | m | W2
10 | Wire, 0.25 mm², GN | 1.0 | m | W2
11 | Wire, 0.25 mm², GY | 1.0 | m | W2
12 | Wire, 0.25 mm², OG | 1.5 | m | W2
13 | Wire, 0.25 mm², RD | 1.5 | m | W2
14 | Wire, 0.25 mm², VT | 1.0 | m | W2
15 | Wire, 0.25 mm², WH | 1.0 | m | W2
16 | Wire, 0.25 mm², YE | 1.5 | m | W2
17 | Wire, 1 mm², BN | 0.5 | m | W0
18 | Wire, 1 mm², OG | 0.5 | m | W0
19 | Wire, 1 mm², RD | 0.5 | m | W0
20 | Wire, 12 AWG, BK | 0.6 | //15ft | W7, W8, W9
21 | Wire, 12 AWG, GN | 0.6 | //15ft | W7, W8, W9
22 | Wire, 12 AWG, WH | 0.6 | //15ft | W7, W8, W9
23 | Wire, 6.0 mm², BK | 0.5 | m | W1
24 | Wire, 6.0 mm², RD | 0.5 | m | W1
25 | Wire, 6.00 mm², BK | 1.6 | m | W3, W4, W5, W6
26 | Wire, 6.00 mm², RD | 1.6 | m | W3, W4, W5, W6
27 | Wire, BK | 5000.0 | //15ft | power_cord
28 | Wire, GN | 5000.0 | //15ft | power_cord
29 | Wire, WH | 5000.0 | //15ft | power_cord

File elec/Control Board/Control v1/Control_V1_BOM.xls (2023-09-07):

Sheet: RAW
Source: | C:\Users\Public\Downloads\Arduino\PubInv\NASA-COG\elec\Control Board\Control v1\Control v1.kicad_sch
Date: | 8/29/2023 9:37:10 PM
Tool: | Eeschema 7.0.5
Generator: | C:\Program Files\KiCad\6.0\bin\scripting\plugins/bom_csv_grouped_by_value.py
Component Count: | 215
Individual Components:
Item | Qty | Reference(s) | Value | LibPart | Footprint | Datasheet | Assembly Type | AssemblyType | Category | Cost | DK_Datasheet_Link | DK_Detail_Page | Description | Digi-Key_PN | Distributor 1 | Distributor 1 PN | Distributor 2 | Distributor 2 PN | Family | LongLead | MPN | Manufacturer | Part Number | Status
 |  | A1 | Arduino_Due_Shield | arduino-library:Arduino_Due_Shield | Arduino:Arduino_Due_Shield | https://docs.arduino.cc/hardware/due
 |  | C1 | 39pF | Device:C | Capacitor_SMD:C_0603_1608Metric_Pad1.08x0.95mm_HandSolder | https://datasheet.lcsc.com/lcsc/1811082118_YAGEO-CC0603JRNPO9BN390_C107049.pdf |  | SMT |  | 0.003 |  |  | 50V 39pF NP0 Â±5% 0603 Multilayer Ceramic Ca |  | JLCPCB | C107049 |  |  |  | NO | CC0603JRNPO9BN390 | YAGEO
 |  | C2 | 39pF | Device:C | Capacitor_SMD:C_0603_1608Metric_Pad1.08x0.95mm_HandSolder | https://datasheet.lcsc.com/lcsc/1811082118_YAGEO-CC0603JRNPO9BN390_C107049.pdf |  | SMT |  | 0.003 |  |  | 50V 39pF NP0 Â±5% 0603 Multilayer Ceramic Ca |  | JLCPCB | C107049 |  |  |  | NO | CC0603JRNPO9BN390 | YAGEO
 |  | C3 | 39pF | Device:C | Capacitor_SMD:C_0603_1608Metric_Pad1.08x0.95mm_HandSolder | https://datasheet.lcsc.com/lcsc/1811082118_YAGEO-CC0603JRNPO9BN390_C107049.pdf |  | SMT |  | 0.003 |  |  | 50V 39pF NP0 Â±5% 0603 Multilayer Ceramic Ca |  | JLCPCB | C107049 |  |  |  | NO | CC0603JRNPO9BN390 | YAGEO
 |  | C4 | 39pF | Device:C | Capacitor_SMD:C_0603_1608Metric_Pad1.08x0.95mm_HandSolder | https://datasheet.lcsc.com/lcsc/1811082118_YAGEO-CC0603JRNPO9BN390_C107049.pdf |  | SMT |  | 0.003 |  |  | 50V 39pF NP0 Â±5% 0603 Multilayer Ceramic Ca |  | JLCPCB | C107049 |  |  |  | NO | CC0603JRNPO9BN390 | YAGEO
 |  | C5 | 39pF | Device:C | Capacitor_SMD:C_0603_1608Metric_Pad1.08x0.95mm_HandSolder | https://datasheet.lcsc.com/lcsc/1811082118_YAGEO-CC0603JRNPO9BN390_C107049.pdf |  | SMT |  | 0.003 |  |  | 50V 39pF NP0 Â±5% 0603 Multilayer Ceramic Ca |  | JLCPCB | C107049 |  |  |  | NO | CC0603JRNPO9BN390 | YAGEO
 |  | C6 | 39pF | Device:C | Capacitor_SMD:C_0603_1608Metric_Pad1.08x0.95mm_HandSolder | https://datasheet.lcsc.com/lcsc/1811082118_YAGEO-CC0603JRNPO9BN390_C107049.pdf |  | SMT |  | 0.003 |  |  | 50V 39pF NP0 Â±5% 0603 Multilayer Ceramic Ca |  | JLCPCB | C107049 |  |  |  | NO | CC0603JRNPO9BN390 | YAGEO
 |  | C7 | 39pF | Device:C | Capacitor_SMD:C_0603_1608Metric_Pad1.08x0.95mm_HandSolder | https://datasheet.lcsc.com/lcsc/1811082118_YAGEO-CC0603JRNPO9BN390_C107049.pdf |  | SMT |  | 0.003 |  |  | 50V 39pF NP0 Â±5% 0603 Multilayer Ceramic Ca |  | JLCPCB | C107049 |  |  |  | NO | CC0603JRNPO9BN390 | YAGEO
 |  | C8 | 39pF | Device:C | Capacitor_SMD:C_0603_1608Metric_Pad1.08x0.95mm_HandSolder | https://datasheet.lcsc.com/lcsc/1811082118_YAGEO-CC0603JRNPO9BN390_C107049.pdf |  | SMT |  | 0.003 |  |  | 50V 39pF NP0 Â±5% 0603 Multilayer Ceramic Ca |  | JLCPCB | C107049 |  |  |  | NO | CC0603JRNPO9BN390 | YAGEO
 |  | C9 | 39pF | Device:C | Capacitor_SMD:C_0603_1608Metric_Pad1.08x0.95mm_HandSolder | https://datasheet.lcsc.com/lcsc/1811082118_YAGEO-CC0603JRNPO9BN390_C107049.pdf |  | SMT |  | 0.003 |  |  | 50V 39pF NP0 Â±5% 0603 Multilayer Ceramic Ca |  | JLCPCB | C107049 |  |  |  | NO | CC0603JRNPO9BN390 | YAGEO
 |  | C10 | 39pF | Device:C | Capacitor_SMD:C_0603_1608Metric_Pad1.08x0.95mm_HandSolder | https://datasheet.lcsc.com/lcsc/1811082118_YAGEO-CC0603JRNPO9BN390_C107049.pdf |  | SMT |  | 0.003 |  |  | 50V 39pF NP0 Â±5% 0603 Multilayer Ceramic Ca |  | JLCPCB | C107049 |  |  |  | NO | CC0603JRNPO9BN390 | YAGEO
 |  | C11 | 39pF | Device:C | Capacitor_SMD:C_0603_1608Metric_Pad1.08x0.95mm_HandSolder | https://datasheet.lcsc.com/lcsc/1811082118_YAGEO-CC0603JRNPO9BN390_C107049.pdf |  | SMT |  | 0.003 |  |  | 50V 39pF NP0 Â±5% 0603 Multilayer Ceramic Ca |  | JLCPCB | C107049 |  |  |  | NO | CC0603JRNPO9BN390 | YAGEO
 |  | C12 | 39pF | Device:C | Capacitor_SMD:C_0603_1608Metric_Pad1.08x0.95mm_HandSolder | https://datasheet.lcsc.com/lcsc/1811082118_YAGEO-CC0603JRNPO9BN390_C107049.pdf |  | SMT |  | 0.003 |  |  | 50V 39pF NP0 Â±5% 0603 Multilayer Ceramic Ca |  | JLCPCB | C107049 |  |  |  | NO | CC0603JRNPO9BN390 | YAGEO
 |  | C13 | 39pF | Device:C | Capacitor_SMD:C_0603_1608Metric_Pad1.08x0.95mm_HandSolder | https://datasheet.lcsc.com/lcsc/1811082118_YAGEO-CC0603JRNPO9BN390_C107049.pdf |  | SMT |  | 0.003 |  |  | 50V 39pF NP0 Â±5% 0603 Multilayer Ceramic Ca |  | JLCPCB | C107049 |  |  |  | NO | CC0603JRNPO9BN390 | YAGEO
 |  | C14 | 39pF | Device:C | Capacitor_SMD:C_0603_1608Metric_Pad1.08x0.95mm_HandSolder | https://datasheet.lcsc.com/lcsc/1811082118_YAGEO-CC0603JRNPO9BN390_C107049.pdf |  | SMT |  | 0.003 |  |  | 50V 39pF NP0 Â±5% 0603 Multilayer Ceramic Ca |  | JLCPCB | C107049 |  |  |  | NO | CC0603JRNPO9BN390 | YAGEO
 |  | C15 | 39pF | Device:C | Capacitor_SMD:C_0603_1608Metric_Pad1.08x0.95mm_HandSolder | https://datasheet.lcsc.com/lcsc/1811082118_YAGEO-CC0603JRNPO9BN390_C107049.pdf |  | SMT |  | 0.003 |  |  | 50V 39pF NP0 Â±5% 0603 Multilayer Ceramic Ca |  | JLCPCB | C107049 |  |  |  | NO | CC0603JRNPO9BN390 | YAGEO
 |  | C16 | 1uF | Device:C | Capacitor_SMD:C_0603_1608Metric_Pad1.08x0.95mm_HandSolder | CC0603JRX7R9BB104.pdf |  | SMT |  | 0.0037 |  |  | 50V 1uF Â±5% 0603 Multilayer Ceramic Ca |  | JLCPCB | C91183 |  |  |  | NO | CC0603JRX7R9BB104 | YAGEO
 |  | C17 | 1uF | Device:C | Capacitor_SMD:C_0603_1608Metric_Pad1.08x0.95mm_HandSolder | CC0603JRX7R9BB104.pdf |  | SMT |  | 0.0037 |  |  | 50V 1uF Â±5% 0603 Multilayer Ceramic Ca |  | JLCPCB | C91183 |  |  |  | NO | CC0603JRX7R9BB104 | YAGEO
 |  | C18 | 1uF | Device:C | Capacitor_SMD:C_0603_1608Metric_Pad1.08x0.95mm_HandSolder | CC0603JRX7R9BB104.pdf |  | SMT |  | 0.0037 |  |  | 50V 1uF Â±5% 0603 Multilayer Ceramic Ca |  | JLCPCB | C91183 |  |  |  | NO | CC0603JRX7R9BB104 | YAGEO
 |  | C19 | 1uF | Device:C | Capacitor_SMD:C_0603_1608Metric_Pad1.08x0.95mm_HandSolder | CC0603JRX7R9BB104.pdf |  | SMT |  | 0.0037 |  |  | 50V 1uF Â±5% 0603 Multilayer Ceramic Ca |  | JLCPCB | C91183 |  |  |  | NO | CC0603JRX7R9BB104 | YAGEO
 |  | C20 | 39pF | Device:C | Capacitor_SMD:C_0603_1608Metric_Pad1.08x0.95mm_HandSolder | https://datasheet.lcsc.com/lcsc/1811082118_YAGEO-CC0603JRNPO9BN390_C107049.pdf |  | SMT |  | 0.003 |  |  | 50V 39pF NP0 Â±5% 0603 Multilayer Ceramic Ca |  | JLCPCB | C107049 |  |  |  | NO | CC0603JRNPO9BN390 | YAGEO
 |  | C21 | 39pF | Device:C | Capacitor_SMD:C_0603_1608Metric_Pad1.08x0.95mm_HandSolder | https://datasheet.lcsc.com/lcsc/1811082118_YAGEO-CC0603JRNPO9BN390_C107049.pdf |  | SMT |  | 0.003 |  |  | 50V 39pF NP0 Â±5% 0603 Multilayer Ceramic Ca |  | JLCPCB | C107049 |  |  |  | NO | CC0603JRNPO9BN390 | YAGEO
 |  | C22 | 10nF | Device:C | Capacitor_SMD:C_0603_1608Metric_Pad1.08x0.95mm_HandSolder | ~ |  | SMT |  | 0.0132 |  |  |  |  | JLCPCB | C389113 |  |  |  |  | CC0603JRNPO9BN103 | YAGEO
 |  | CIPO1 | CIPO | Connector:TestPoint | TestPoint:TestPoint_Loop_D2.54mm_Drill1.5mm_Beaded | ~ |  | HAND |  | 0
 |  | COPI1 | COPI | Connector:TestPoint | TestPoint:TestPoint_Loop_D2.54mm_Drill1.5mm_Beaded | ~ |  | HAND |  | 0
 |  | D1 | DNI | Diode:BZV55B3V3 | Diode_SMD:D_MiniMELF | https://assets.nexperia.com/documents/data-sheet/BZV55_SER.pdf BZV55B3V3 |  | SMT |  | 1000000
 |  | D2 | DNI | Diode:BZV55B3V3 | Diode_SMD:D_MiniMELF | https://assets.nexperia.com/documents/data-sheet/BZV55_SER.pdf BZV55B3V3 |  | SMT |  | 1000000
 |  | D_PSU_RX1 | D_PSU_RX | Connector:TestPoint | TestPoint:TestPoint_Loop_D2.54mm_Drill1.5mm_Beaded | ~ |  | HAND |  | 0
 |  | D_PSU_TX1 | D_PSU_TX | Connector:TestPoint | TestPoint:TestPoint_Loop_D2.54mm_Drill1.5mm_Beaded | ~ |  | HAND |  | 0
 |  | H1 | MountingHole_Pad_3.5mm | GPAD_SCH_LIB:MountingHole_Pad_3.5mm | PubInv_KiCad_PCB:MountingHole_3.5mm_Pad_Via | ~ |  | NA |  | 0 |  |  | MountingHole_Pad_3.5mm |  | NA | NA
 |  | H2 | MountingHole_Pad_3.5mm | GPAD_SCH_LIB:MountingHole_Pad_3.5mm | PubInv_KiCad_PCB:MountingHole_3.5mm_Pad_Via | ~ |  | NA |  | 0 |  |  | MountingHole_Pad_3.5mm |  | NA | NA
 |  | H3 | MountingHole_Pad_3.5mm | GPAD_SCH_LIB:MountingHole_Pad_3.5mm | PubInv_KiCad_PCB:MountingHole_3.5mm_Pad_Via | ~ |  | NA |  | 0 |  |  | MountingHole_Pad_3.5mm |  | NA | NA
 |  | H4 | MountingHole_Pad_3.5mm | GPAD_SCH_LIB:MountingHole_Pad_3.5mm | PubInv_KiCad_PCB:MountingHole_3.5mm_Pad_Via | ~ |  | NA |  | 0 |  |  | MountingHole_Pad_3.5mm |  | NA | NA
 |  | H5 | MountingHole_Pad_3.5mm | GPAD_SCH_LIB:MountingHole_Pad_3.5mm | PubInv_KiCad_PCB:MountingHole_3.5mm_Pad_Via | ~ |  | NA |  | 0 |  |  | MountingHole_Pad_3.5mm |  | NA | NA
 |  | ISO1 | MountingHole_Pad_3.5mm | GPAD_SCH_LIB:MountingHole_Pad_3.5mm | PubInv_KiCad_PCB:MountingHole_3.5mm_Pad_Via | ~ |  | NA |  | 0 |  |  | MountingHole_Pad_3.5mm |  | NA | NA
 |  | ISO2 | MountingHole_Pad_3.5mm | GPAD_SCH_LIB:MountingHole_Pad_3.5mm | PubInv_KiCad_PCB:MountingHole_3.5mm_Pad_Via | ~ |  | NA |  | 0 |  |  | MountingHole_Pad_3.5mm |  | NA | NA
 |  | ISO3 | MountingHole_Pad_3.5mm | GPAD_SCH_LIB:MountingHole_Pad_3.5mm | PubInv_KiCad_PCB:MountingHole_3.5mm_Pad_Via | ~ |  | NA |  | 0 |  |  | MountingHole_Pad_3.5mm |  | NA | NA
 |  | ISO4 | MountingHole_Pad_3.5mm | GPAD_SCH_LIB:MountingHole_Pad_3.5mm | PubInv_KiCad_PCB:MountingHole_3.5mm_Pad_Via | ~ |  | NA |  | 0 |  |  | MountingHole_Pad_3.5mm |  | NA | NA
 |  | ISO5 | MountingHole_Pad_3.5mm | GPAD_SCH_LIB:MountingHole_Pad_3.5mm | PubInv_KiCad_PCB:MountingHole_3.5mm_Pad_Via | ~ |  | NA |  | 0 |  |  | MountingHole_Pad_3.5mm |  | NA | NA
 |  | J1 | DB9_Female_MountingHoles | Connector:DB9_Female_MountingHoles | Connector_Dsub:DSUB-9_Female_Horizontal_P2.77x2.84mm_EdgePinOffset4.94mm_Housed_MountingHolesOffset7.48mm | C141882_D-DMR009PF-D002.pdf |  | HAND |  | 0.2718 |  |  | 9P Female D-Sub Shrouded 2 3A -50â„ƒ~+105â„ƒ Plugin D-Sub/DVI/HDMI Connectors ROHS |  | JLCPCB | C141882 |  |  |  |  | D-DMR009PF-D002 | Ckmtw(Shenzhen Cankemeng)
 |  | J2 | Conn_01x08 | Connector_Generic:Conn_01x08 | Connector_PinSocket_2.54mm:PinSocket_1x08_P2.54mm_Vertical | https://jlcpcb.com/partdetail/Hctl-PZ254_1_08_Z_85/C2894931 |  | HAND |  | 0.0762 |  |  | 3A Straight Square Pins 2.5mm 8P 6mm -40â„ƒ~+105â„ƒ 3mm 2.54mm Plugin Black 1x8P Plugin,P=2.54mm Pin Headers ROHS |  | JLCPCB | C2894931 |  |  |  |  | PZ254-1-08-Z-8.5 | HCTL
 |  | J3 | Conn_01x08 | Connector_Generic:Conn_01x08 | Connector_PinHeader_2.54mm:PinHeader_1x08_P2.54mm_Vertical | https://jlcpcb.com/partdetail/Hctl-PZ254_1_08_Z_85/C2894931 |  | HAND |  | 0.0762 |  |  | 3A Straight Square Pins 2.5mm 8P 6mm -40â„ƒ~+105â„ƒ 3mm 2.54mm Plugin Black 1x8P Plugin,P=2.54mm Pin Headers ROHS |  | JLCPCB | C2894931 |  |  |  |  | PZ254-1-08-Z-8.5 | HCTL
 |  | J4 | Conn_01x08 | Connector_Generic:Conn_01x08 | Connector_PinSocket_2.54mm:PinSocket_1x08_P2.54mm_Vertical | https://jlcpcb.com/partdetail/Hctl-PZ254_1_08_Z_85/C2894931 |  | HAND |  | 0.0762 |  |  | 3A Straight Square Pins 2.5mm 8P 6mm -40â„ƒ~+105â„ƒ 3mm 2.54mm Plugin Black 1x8P Plugin,P=2.54mm Pin Headers ROHS |  | JLCPCB | C2894931 |  |  |  |  | PZ254-1-08-Z-8.5 | HCTL
 |  | J5 | Conn_01x08 | Connector_Generic:Conn_01x08 | Connector_PinSocket_2.54mm:PinSocket_1x08_P2.54mm_Vertical | https://jlcpcb.com/partdetail/Hctl-PZ254_1_08_Z_85/C2894931 |  | HAND |  | 0.0762 |  |  | 3A Straight Square Pins 2.5mm 8P 6mm -40â„ƒ~+105â„ƒ 3mm 2.54mm Plugin Black 1x8P Plugin,P=2.54mm Pin Headers ROHS |  | JLCPCB | C2894931 |  |  |  |  | PZ254-1-08-Z-8.5 | HCTL
 |  | J6 | Conn_01x08 | Connector_Generic:Conn_01x08 | Connector_PinSocket_2.54mm:PinSocket_1x08_P2.54mm_Vertical | https://jlcpcb.com/partdetail/Hctl-PZ254_1_08_Z_85/C2894931 |  | HAND |  | 0.0762 |  |  | 3A Straight Square Pins 2.5mm 8P 6mm -40â„ƒ~+105â„ƒ 3mm 2.54mm Plugin Black 1x8P Plugin,P=2.54mm Pin Headers ROHS |  | JLCPCB | C2894931 |  |  |  |  | PZ254-1-08-Z-8.5 | HCTL
 |  | J7 | Conn_01x10 | Connector_Generic:Conn_01x10 | Connector_PinSocket_2.54mm:PinSocket_1x10_P2.54mm_Vertical | https://jlcpcb.com/partdetail/Hctl-PZ254_1_10_Z_85/C2894933 |  | HAND |  | 0.0942 |  |  | 3A Straight Square Pins 2.5mm 10P 6mm -40â„ƒ~+105â„ƒ 3mm 2.54mm Plugin Black 1x10P Plugin,P=2.54mm Pin Headers ROHS |  | JLCPCB | C2894933 |  |  |  |  | PZ254-1-10-Z-8.5 | HCTL
 |  | J8 | Conn_02x18_Odd_Even | Connector_Generic:Conn_02x18_Odd_Even | Connector_PinSocket_2.54mm:PinSocket_2x18_P2.54mm_Vertical | C132131_DS1023-2_18SF11.pdf |  | HAND |  | 0.3441 |  |  | 2.54mm 2.54mm åŒæŽ’ 36P Straight 2x18P Plugin,P=2.54mm Female Headers ROHS |  | JLCPCB | C132131
 |  | J9 | Conn_01x10 | Connector_Generic:Conn_01x10 | Connector_PinSocket_2.54mm:PinSocket_1x10_P2.54mm_Vertical | https://jlcpcb.com/partdetail/Hctl-PZ254_1_10_Z_85/C2894933 |  | HAND |  | 0.0942 |  |  | 3A Straight Square Pins 2.5mm 10P 6mm -40â„ƒ~+105â„ƒ 3mm 2.54mm Plugin Black 1x10P Plugin,P=2.54mm Pin Headers ROHS |  | JLCPCB | C2894933 |  |  |  |  | PZ254-1-10-Z-8.5 | HCTL
 |  | J10 | Conn_02x12_Odd_Even | Connector_Generic:Conn_02x12_Odd_Even | Connector_PinHeader_2.00mm:PinHeader_2x12_P2.00mm_Vertical | https://www.jst-mfg.com/product/pdf/eng/ePHD.pdf |  | HAND |  | 1000000 |  |  |  |  |  |  | JLCPCB ?https://jlcpcb.com/partdetail/566831-B24B_XADSS_N_A_LF_SN/C545730? | ? https://jlcpcb.com/partdetail/Cnjm-CNJMA2006WV_2X12P9T/C2834570 ? |  |  |  |  | B24B-PHDSS
 |  | J11 | Screw_Terminal_01x02 | Connector:Screw_Terminal_01x02 | TerminalBlock_TE-Connectivity:TerminalBlock_TE_282834-2_1x02_P2.54mm_Horizontal | DB128V-5.08-2P-GN-S.pdf |  | HAND |  | 0.1537 |  |  | 1x2P 20A -40â„ƒ~+105â„ƒ 300V Green 12~30 Straight pin 5.08mm 2.5 1 2 Plugin,P=5.08mm Screw terminal ROHS |  | JLCPCB | C918120 |  |  |  |  | DB125-2.54-2P-GN-S | DIBO
 |  | J12 | Screw_Terminal_01x02 | Connector:Screw_Terminal_01x02 | TerminalBlock_TE-Connectivity:TerminalBlock_TE_282834-2_1x02_P2.54mm_Horizontal | DB128V-5.08-2P-GN-S.pdf |  | HAND |  | 0.1537 |  |  | 1x2P 20A -40â„ƒ~+105â„ƒ 300V Green 12~30 Straight pin 5.08mm 2.5 1 2 Plugin,P=5.08mm Screw terminal ROHS |  | JLCPCB | C918120 |  |  |  |  | DB125-2.54-2P-GN-S | DIBO
 |  | J13 | Screw_Terminal_01x02 | Connector:Screw_Terminal_01x02 | TerminalBlock_TE-Connectivity:TerminalBlock_TE_282834-2_1x02_P2.54mm_Horizontal | DB128V-5.08-2P-GN-S.pdf |  | HAND |  | 0.1537 |  |  | 1x2P 20A -40â„ƒ~+105â„ƒ 300V Green 12~30 Straight pin 5.08mm 2.5 1 2 Plugin,P=5.08mm Screw terminal ROHS |  | JLCPCB | C918120 |  |  |  |  | DB125-2.54-2P-GN-S | DIBO
 |  | J14 | Conn_01x10 | Connector_Generic:Conn_01x10 | Connector_PinSocket_2.54mm:PinSocket_1x10_P2.54mm_Vertical | https://jlcpcb.com/partdetail/Hctl-PZ254_1_10_Z_85/C2894933 |  | HAND |  | 0.0942 |  |  | 3A Straight Square Pins 2.5mm 10P 6mm -40â„ƒ~+105â„ƒ 3mm 2.54mm Plugin Black 1x10P Plugin,P=2.54mm Pin Headers ROHS |  | JLCPCB | C2894933 |  |  |  |  | PZ254-1-10-Z-8.5 | HCTL
 |  | J15 | DB25_Female_MountingHoles | Connector:DB25_Female_MountingHoles | Connector_Dsub:DSUB-25_Female_Horizontal_P2.77x2.84mm_EdgePinOffset4.94mm_Housed_MountingHolesOffset7.48mm | C190083_D-DMR025PF-D002.pdf |  | HAND |  | 0.7217 |  |  | 25P Female D-Sub Shrouded 2 3A -50â„ƒ~+105â„ƒ Plugin D-Sub/DVI/HDMI Connectors ROHS |  | JLCPCB | C190083 |  |  |  |  | D-DMR025PF-D002 | Ckmtw(Shenzhen Cankemeng)
 |  | J16 | Conn_01x04 | Connector_Generic:Conn_01x04 | Connector_PinHeader_2.54mm:PinHeader_1x04_P2.54mm_Vertical | KH-2.54FH-1X4P-H8.5.pdf |  | HAND |  | 0.0342 |  |  | 2.54mm Plugin 3A 4P -40â„ƒ~+105â„ƒ Straight 1x4P 8.5mm Top Square Holes Plugin,P=2.54mm Female Headers ROHS |  | JLCPCB | C2905415 |  |  |  |  | KH-2.54FH-1X4P-H8.5 | Shenzhen Kinghelm Elec
 |  | J17 | Conn_01x05 | Connector_Generic:Conn_01x05 | Connector_PinHeader_2.54mm:PinHeader_1x05_P2.54mm_Vertical | C2897368_PM254-1-05-Z-8.5.pdf |  | HAND |  | 0.0791 |  |  | 2.54mm Plugin 3A 5P -40â„ƒ~+105â„ƒ Straight 1x5P 8.5mm Top Square Holes Plugin,P=2.54mm Female Headers ROHS |  | JLCPCB | C2897368 |  |  |  |  | PM254-1-05-Z-8.5 | HCTL
 |  | J18 | Conn_01x04 | Connector_Generic:Conn_01x04 | Connector_PinHeader_2.54mm:PinHeader_1x04_P2.54mm_Vertical | KH-2.54FH-1X4P-H8.5.pdf |  | HAND |  | 0.0342 |  |  | 2.54mm Plugin 3A 4P -40â„ƒ~+105â„ƒ Straight 1x4P 8.5mm Top Square Holes Plugin,P=2.54mm Female Headers ROHS |  | JLCPCB | C2905415 |  |  |  |  | KH-2.54FH-1X4P-H8.5 | Shenzhen Kinghelm Elec
 |  | J19 | Conn_01x07 | Connector_Generic:Conn_01x07 | Connector_PinHeader_2.54mm:PinHeader_1x07_P2.54mm_Vertical | C2932672_KH-2.54FH-1X7P-H8.5.pdf |  | HAND |  | 0.0543 |  |  | 2.54mm Plugin 3A 7P -40â„ƒ~+105â„ƒ Straight 1x7P 8.5mm Top Square Holes Plugin,P=2.54mm Female Headers ROHS |  | JLCPCB | C2932672
 |  | J20 | Conn_01x04 | Connector:Conn_01x04_Pin | Connector_PinHeader_2.54mm:PinHeader_1x04_P2.54mm_Vertical | KH-2.54FH-1X4P-H8.5.pdf |  | HAND |  | 0.0342 |  |  | 2.54mm Plugin 3A 4P -40â„ƒ~+105â„ƒ Straight 1x4P 8.5mm Top Square Holes Plugin,P=2.54mm Female Headers ROHS |  | JLCPCB | C2905415 |  |  |  |  | KH-2.54FH-1X4P-H8.5 | Shenzhen Kinghelm Elec
 |  | J21 | RJ12_6P6C_HORZ | GPAD_SCH_LIB:RJ12_6P6C_HORZ | PubInv_KiCad_PCB:RJ12_Amphenol_54601 | https://datasheet.lcsc.com/lcsc/1811141146_TE-Connectivity-5555165-1_C305981.pdf |  | HAND |  | 0.8901 |  |  | Jack Modular Connector 6p6c (RJ11, RJ12, RJ14, RJ25) 90Â° Angle (Right) Unshielded Cat3 |  | JLCPCB | C305981 | Digikey | A31422-ND |  | YES | 5555165-1 | TE Connectivity
 |  | J22 | 0.100_2Pin | GPAD_SCH_LIB:22-23-2021 | Connector_PinHeader_2.54mm:PinHeader_1x02_P2.54mm_Vertical | https://datasheet.lcsc.com/lcsc/1811011511_Amphenol-ICC-68000-102HLF_C168673.pdf | HAND | HAND | Connectors, Interconnects | 0.1458 | https://media.digikey.com/pdf/Data%20Sheets/Molex%20PDFs/A-6373-N_Series_Dwg_2010-12-03.pdf | /product-detail/en/molex/22-23-2021/WM4200-ND/26667 | HEADER VERT 2POS 2.54MM | WM4200-ND | JLCPCB | C168673 |  |  | Rectangular Connectors - Headers, Male Pins | YES | 68000-102HLF | Amphenol ICC |  | Active
 |  | J23 | 0.100_2Pin | GPAD_SCH_LIB:22-23-2021 | Connector_PinHeader_2.54mm:PinHeader_1x02_P2.54mm_Vertical | https://datasheet.lcsc.com/lcsc/1811011511_Amphenol-ICC-68000-102HLF_C168673.pdf | HAND | HAND | Connectors, Interconnects | 0.1458 | https://media.digikey.com/pdf/Data%20Sheets/Molex%20PDFs/A-6373-N_Series_Dwg_2010-12-03.pdf | /product-detail/en/molex/22-23-2021/WM4200-ND/26667 | HEADER VERT 2POS 2.54MM | WM4200-ND | JLCPCB | C168673 |  |  | Rectangular Connectors - Headers, Male Pins | YES | 68000-102HLF | Amphenol ICC |  | Active
 |  | J24 | Conn_01x04 | Connector_Generic:Conn_01x04 | Connector_PinHeader_2.54mm:PinHeader_1x04_P2.54mm_Vertical | KH-2.54FH-1X4P-H8.5.pdf |  | HAND |  | 0.0342 |  |  | 2.54mm Plugin 3A 4P -40â„ƒ~+105â„ƒ Straight 1x4P 8.5mm Top Square Holes Plugin,P=2.54mm Female Headers ROHS |  | JLCPCB | C2905415 |  |  |  |  | KH-2.54FH-1X4P-H8.5 | Shenzhen Kinghelm Elec
 |  | J25 | Screw_Terminal_01x02 | Connector:Screw_Terminal_01x02 | TerminalBlock_TE-Connectivity:TerminalBlock_TE_282834-2_1x02_P2.54mm_Horizontal | DB128V-5.08-2P-GN-S.pdf |  | HAND |  | 0.1537 |  |  | 1x2P 20A -40â„ƒ~+105â„ƒ 300V Green 12~30 Straight pin 5.08mm 2.5 1 2 Plugin,P=5.08mm Screw terminal ROHS |  | JLCPCB | C918120 |  |  |  |  | DB125-2.54-2P-GN-S | DIBO
 |  | JP1 | SolderJumper_3_Bridged12 | Jumper:SolderJumper_3_Bridged12 | Jumper:SolderJumper-3_P1.3mm_Bridged12_RoundedPad1.0x1.5mm | NA |  | DNI |  | 0 |  |  | SolderJumper_3_Bridged12 |  | PublicInvention | NA |  |  |  |  | NA | NA
 |  | JP2 | SolderJumper_3_Bridged12 | Jumper:SolderJumper_3_Bridged12 | Jumper:SolderJumper-3_P1.3mm_Bridged12_RoundedPad1.0x1.5mm | NA |  | DNI |  | 0 |  |  | SolderJumper_3_Bridged12 |  | PublicInvention | NA |  |  |  |  | NA | NA
 |  | JP3 | SolderJumper_3_Bridged12 | Jumper:SolderJumper_3_Bridged12 | Jumper:SolderJumper-3_P1.3mm_Bridged12_RoundedPad1.0x1.5mm | NA |  | DNI |  | 0 |  |  | SolderJumper_3_Bridged12 |  | PublicInvention | NA |  |  |  |  | NA | NA
 |  | JP4 | SolderJumper_3_Bridged12 | Jumper:SolderJumper_3_Bridged12 | Jumper:SolderJumper-3_P1.3mm_Bridged12_RoundedPad1.0x1.5mm | NA |  | DNI |  | 0 |  |  | SolderJumper_3_Bridged12 |  | PublicInvention | NA |  |  |  |  | NA | NA
 |  | JP5 | SolderJumper_3_Bridged12 | Jumper:SolderJumper_3_Bridged12 | Jumper:SolderJumper-3_P1.3mm_Bridged12_RoundedPad1.0x1.5mm | NA |  | DNI |  | 0 |  |  | SolderJumper_3_Bridged12 |  | PublicInvention | NA |  |  |  |  | NA | NA
 |  | JP6 | SolderJumper_3_Bridged12 | Jumper:SolderJumper_3_Bridged12 | Jumper:SolderJumper-3_P1.3mm_Bridged12_RoundedPad1.0x1.5mm | NA |  | DNI |  | 0 |  |  | SolderJumper_3_Bridged12 |  | PublicInvention | NA |  |  |  |  | NA | NA
 |  | JP7 | SolderJumper_3_Bridged12 | Jumper:SolderJumper_3_Bridged12 | Jumper:SolderJumper-3_P1.3mm_Bridged12_RoundedPad1.0x1.5mm | NA |  | DNI |  | 0 |  |  | SolderJumper_3_Bridged12 |  | PublicInvention | NA |  |  |  |  | NA | NA
 |  | JP8 | SolderJumper_3_Bridged12 | Jumper:SolderJumper_3_Bridged12 | Jumper:SolderJumper-3_P1.3mm_Bridged12_RoundedPad1.0x1.5mm | NA |  | DNI |  | 0 |  |  | SolderJumper_3_Bridged12 |  | PublicInvention | NA |  |  |  |  | NA | NA
 |  | JP9 | MAX31850K | Connector_Generic:Conn_01x08 | PubInv_KiCad_PCB:Adafruit_MAX31850K_Module | https://www.adafruit.com/product/1727 |  | HAND |  | 14.95 |  |  | Thermocouple Amplifier with 1-Wire Breakout Board - MAX31850K |  | adafruit | 1727 |  |  |  |  | 1727 | Adafruit
 |  | JP10 | MAX31850K | Control v1-eagle-import:microbuilder_HEADER-1X870MIL | PubInv_KiCad_PCB:Adafruit_MAX31850K_Module | https://www.adafruit.com/product/1727 |  | HAND |  | 14.95 |  |  | Thermocouple Amplifier with 1-Wire Breakout Board - MAX31850K |  | adafruit | 1727 |  |  |  |  | 1727 | Adafruit
 |  | JP11 | SolderJumper_3_Bridged12 | Jumper:SolderJumper_3_Bridged12 | Jumper:SolderJumper-3_P1.3mm_Bridged12_RoundedPad1.0x1.5mm | NA |  | DNI |  | 0 |  |  | SolderJumper_3_Bridged12 |  | PublicInvention | NA |  |  |  |  | NA | NA
 |  | JP12 | SolderJumper_3_Bridged12 | Jumper:SolderJumper_3_Bridged12 | Jumper:SolderJumper-3_P1.3mm_Bridged12_RoundedPad1.0x1.5mm | NA |  | DNI |  | 0 |  |  | SolderJumper_3_Bridged12 |  | PublicInvention | NA |  |  |  |  | NA | NA
 |  | JP13 | SolderJumper_3_Bridged12 | Jumper:SolderJumper_3_Bridged12 | Jumper:SolderJumper-3_P1.3mm_Bridged12_RoundedPad1.0x1.5mm | NA |  | DNI |  | 0 |  |  | SolderJumper_3_Bridged12 |  | PublicInvention | NA |  |  |  |  | NA | NA
 |  | JP14 | SolderJumper_3_Bridged12 | Jumper:SolderJumper_3_Bridged12 | Jumper:SolderJumper-3_P1.3mm_Bridged12_RoundedPad1.0x1.5mm | NA |  | DNI |  | 0 |  |  | SolderJumper_3_Bridged12 |  | PublicInvention | NA |  |  |  |  | NA | NA
 |  | JP15 | MAX31850K | Control v1-eagle-import:microbuilder_HEADER-1X870MIL | PubInv_KiCad_PCB:Adafruit_MAX31850K_Module | https://www.adafruit.com/product/1727 |  | HAND |  | 14.95 |  |  | Thermocouple Amplifier with 1-Wire Breakout Board - MAX31850K |  | adafruit | 1727 |  |  |  |  | 1727 | Adafruit
 |  | JP16 | MAX31855 | Control v1-eagle-import:HEADER-1X676MIL | PubInv_KiCad_PCB:Adafruit_MAX31855_Module | https://www.adafruit.com/product/269 |  | HAND |  | 14.95 |  |  | Thermocouple Amplifier MAX31855 breakout board (MAX6675 upgrade) |  | adafruit | 269 |  |  |  |  | 269 | Adafruit
 |  | JP17 | MAX31855 | Control v1-eagle-import:HEADER-1X676MIL | PubInv_KiCad_PCB:Adafruit_MAX31855_Module | https://www.adafruit.com/product/269 |  | HAND |  | 14.95 |  |  | Thermocouple Amplifier MAX31855 breakout board (MAX6675 upgrade) |  | adafruit | 269 |  |  |  |  | 269 | Adafruit
 |  | JP18 | MAX31855 | Control v1-eagle-import:HEADER-1X676MIL | PubInv_KiCad_PCB:Adafruit_MAX31855_Module | https://www.adafruit.com/product/269 |  | HAND |  | 14.95 |  |  | Thermocouple Amplifier MAX31855 breakout board (MAX6675 upgrade) |  | adafruit | 269 |  |  |  |  | 269 | Adafruit
 |  | JP19 | MCP9600 | Control v1-eagle-import:HEADER-1X970MIL | PubInv_KiCad_PCB:Adafruit_MCP9600_Module | https://www.adafruit.com/product/4101 |  | HAND |  | 15.95 |  |  | Adafruit MCP9600 I2C Thermocouple Amplifier - K, J, T, N, S, E, B and R Type T |  | adafruit | 4101 |  |  |  |  | 4101 | Adafruit
 |  | JP20 | MCP9600 | Control v1-eagle-import:HEADER-1X970MIL | PubInv_KiCad_PCB:Adafruit_MCP9600_Module | https://www.adafruit.com/product/4101 |  | HAND |  | 15.95 |  |  | Adafruit MCP9600 I2C Thermocouple Amplifier - K, J, T, N, S, E, B and R Type T |  | adafruit | 4101 |  |  |  |  | 4101 | Adafruit
 |  | JP21 | MCP9600 | Control v1-eagle-import:HEADER-1X970MIL | PubInv_KiCad_PCB:Adafruit_MCP9600_Module | https://www.adafruit.com/product/4101 |  | HAND |  | 15.95 |  |  | Adafruit MCP9600 I2C Thermocouple Amplifier - K, J, T, N, S, E, B and R Type T |  | adafruit | 4101 |  |  |  |  | 4101 | Adafruit
 |  | MF1 | PCB_BKT_OEDCS_01 | GPAD_SCH_LIB:PCB_GPAD_VER1 | NA | PCB_BKT_OEDCS_01 |  | HAND |  | 1000000 |  |  | PCB_BKT_OEDCS_01 |  | PublicInvention | PCB_BKT_OEDCS_01 |  |  |  | YES | PCB_BKT_OEDCS_01 | PublicInvention
 |  | MF2 | PCB_BKT_OEDCS_01 | GPAD_SCH_LIB:PCB_GPAD_VER1 | NA | PCB_BKT_OEDCS_01 |  | HAND |  | 1000000 |  |  | PCB_BKT_OEDCS_01 |  | PublicInvention | PCB_BKT_OEDCS_01 |  |  |  | YES | PCB_BKT_OEDCS_01 | PublicInvention
 |  | MF3 | Stacking Headers Pins Kit | GPAD_SCH_LIB:PCB_GPAD_VER1 | NA | https://www.amazon.com/Treedix-Stacking-Headers-Stackable-Compatible/dp/B08G4FGBPQ/ref=sr_1_6 |  | HAND |  | 4.5 |  |  | Stacking Headers Pins Kit Stackable Female Headers Compatible with Arduino Mega 2560(28pcs in Total) |  | Amazon | https://www.amazon.com/Treedix-Stacking-Headers-Stackable-Compatible/dp/B08G4FGBPQ/ref=sr_1_6 |  |  |  | YES | PCB_BKT_OEDCS_01 | TreeDix
 |  | MF4 | PCB_OEDCS_Control_Ver_0.1 | GPAD_SCH_LIB:PCB_GPAD_VER1 | NA | https://github.com/PubInv/NASA-COG/tree/develop/elec/Control%20Board/Control%20v1 |  | HAND |  | 1000000 |  |  | PCB for OEDCS_Controller Version 0.1 |  | PublicInvention | PCB_PolyVent_SPI_Controller_VER1 |  |  |  | YES | PCB_OEDCS_Control_Ver_0.1 | PublicInvention
 |  | Q1 | BSS138 | Transistor_FET:BSS138 | Package_TO_SOT_SMD:SOT-23 | https://www.onsemi.com/pub/Collateral/BSS138-D.PDF |  | SMT |  | 0.0196 |  |  | 50V 220mA 3.5Î©@10V,220mA 360mW 1.5V@1mA N Channel SOT-23 MOSFETs ROHS |  | JLCPCB | C400505 |  |  |  |  | BSS138 | Yangzhou Yangjie Electronic Technology Co., Ltd
 |  | Q2 | NCE01P30K | Transistor_FET:SUD45P03-09 | Package_TO_SOT_SMD:TO-252-2 | https://jlcpcb.com/partdetail/117243-NCE01P30K/C115991 |  | SMT |  | $0.51 |  |  | P Channel -100V 30A(Tc) 2.5V @ 250uA 58mÎ© @ 15A,10V 120W(Tc) TO-252-2L MOSFET RoHS |  | JLCPCB | C115991 |  |  |  |  | NCE01P30K | Wuxi NCE Power Semiconductor
 |  | Q3 | BSS138 | Transistor_FET:BSS138 | Package_TO_SOT_SMD:SOT-23 | https://www.onsemi.com/pub/Collateral/BSS138-D.PDF |  | SMT |  | 0.0196 |  |  | 50V 220mA 3.5Î©@10V,220mA 360mW 1.5V@1mA N Channel SOT-23 MOSFETs ROHS |  | JLCPCB | C400505 |  |  |  |  | BSS138 | Yangzhou Yangjie Electronic Technology Co., Ltd
 |  | Q4 | BSS138 | Transistor_FET:BSS138 | Package_TO_SOT_SMD:SOT-23 | https://www.onsemi.com/pub/Collateral/BSS138-D.PDF |  | SMT |  | 0.0196 |  |  | 50V 220mA 3.5Î©@10V,220mA 360mW 1.5V@1mA N Channel SOT-23 MOSFETs ROHS |  | JLCPCB | C400505 |  |  |  |  | BSS138 | Yangzhou Yangjie Electronic Technology Co., Ltd
 |  | Q5 | BSS138 | :BSS138_1 | Package_TO_SOT_SMD:SOT-23 | https://www.onsemi.com/pub/Collateral/BSS138-D.PDF |  | SMT |  | 0.0196 |  |  | 50V 220mA 3.5Î©@10V,220mA 360mW 1.5V@1mA N Channel SOT-23 MOSFETs ROHS |  | JLCPCB | C400505 |  |  |  | NO | BSS138 | Yangzhou Yangjie Elec Tech
 |  | Q6 | BSS138 | :BSS138_1 | Package_TO_SOT_SMD:SOT-23 | https://www.onsemi.com/pub/Collateral/BSS138-D.PDF |  | SMT |  | 0.0196 |  |  | 50V 220mA 3.5Î©@10V,220mA 360mW 1.5V@1mA N Channel SOT-23 MOSFETs ROHS |  | JLCPCB | C400505 |  |  |  | NO | BSS138 | Yangzhou Yangjie Elec Tech
 |  | Q7 | BSS138 | :BSS138_1 | Package_TO_SOT_SMD:SOT-23 | https://www.onsemi.com/pub/Collateral/BSS138-D.PDF |  | SMT |  | 0.0196 |  |  | 50V 220mA 3.5Î©@10V,220mA 360mW 1.5V@1mA N Channel SOT-23 MOSFETs ROHS |  | JLCPCB | C400505 |  |  |  | NO | BSS138 | Yangzhou Yangjie Elec Tech
 |  | Q8 | BSS138 | :BSS138_1 | Package_TO_SOT_SMD:SOT-23 | https://www.onsemi.com/pub/Collateral/BSS138-D.PDF |  | SMT |  | 0.0196 |  |  | 50V 220mA 3.5Î©@10V,220mA 360mW 1.5V@1mA N Channel SOT-23 MOSFETs ROHS |  | JLCPCB | C400505 |  |  |  | NO | BSS138 | Yangzhou Yangjie Elec Tech
 |  | Q9 | BSS138 | :BSS138_1 | Package_TO_SOT_SMD:SOT-23 | https://www.onsemi.com/pub/Collateral/BSS138-D.PDF |  | SMT |  | 0.0196 |  |  | 50V 220mA 3.5Î©@10V,220mA 360mW 1.5V@1mA N Channel SOT-23 MOSFETs ROHS |  | JLCPCB | C400505 |  |  |  | NO | BSS138 | Yangzhou Yangjie Elec Tech
 |  | Q10 | BSS138 | :BSS138_1 | Package_TO_SOT_SMD:SOT-23 | https://www.onsemi.com/pub/Collateral/BSS138-D.PDF |  | SMT |  | 0.0196 |  |  | 50V 220mA 3.5Î©@10V,220mA 360mW 1.5V@1mA N Channel SOT-23 MOSFETs ROHS |  | JLCPCB | C400505 |  |  |  | NO | BSS138 | Yangzhou Yangjie Elec Tech
 |  | R1 | 1R0 | Device:R | Resistor_SMD:R_0603_1608Metric_Pad0.98x0.95mm_HandSolder | ~ |  | SMT |  | 0.0015 |  |  | 0.1W Â±5% 1Î© 0603 Chip Resistor - Surface Mount ROHS |  | JLCPCB | C269434 |  |  |  |  | RMC060315%N | TyoHM
 |  | R2 | 1R0 | Device:R | Resistor_SMD:R_0603_1608Metric_Pad0.98x0.95mm_HandSolder | ~ |  | SMT |  | 0.0015 |  |  | 0.1W Â±5% 1Î© 0603 Chip Resistor - Surface Mount ROHS |  | JLCPCB | C269434 |  |  |  |  | RMC060315%N | TyoHM
 |  | R3 | 1R0 | Device:R | Resistor_SMD:R_0603_1608Metric_Pad0.98x0.95mm_HandSolder | ~ |  | SMT |  | 0.0015 |  |  | 0.1W Â±5% 1Î© 0603 Chip Resistor - Surface Mount ROHS |  | JLCPCB | C269434 |  |  |  |  | RMC060315%N | TyoHM
 |  | R4 | 1R0 | Device:R | Resistor_SMD:R_0603_1608Metric_Pad0.98x0.95mm_HandSolder | ~ |  | SMT |  | 0.0015 |  |  | 0.1W Â±5% 1Î© 0603 Chip Resistor - Surface Mount ROHS |  | JLCPCB | C269434 |  |  |  |  | RMC060315%N | TyoHM
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

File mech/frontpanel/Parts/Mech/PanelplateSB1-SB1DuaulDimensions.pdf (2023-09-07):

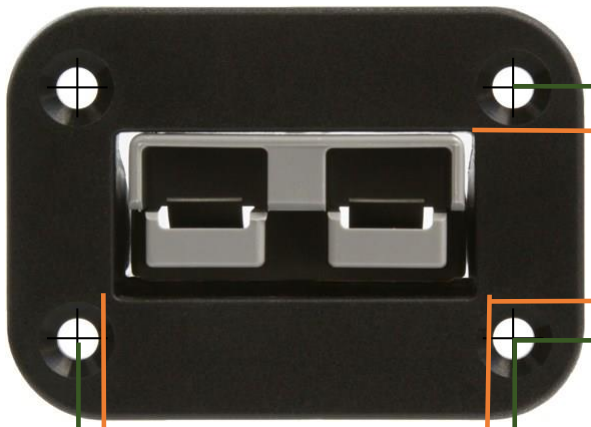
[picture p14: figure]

1.755in

1.6in

.77in 1.02in

## Panelplate SB1/ SB1 Dual Dimensions

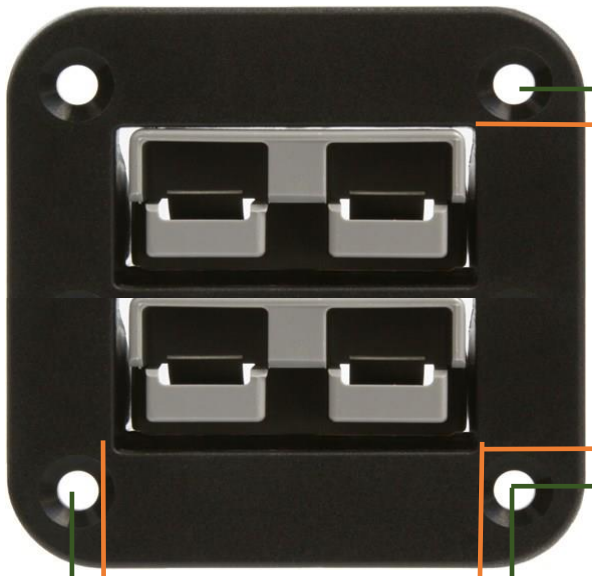
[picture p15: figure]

1.63in

1.755in

1.51in 1.88in

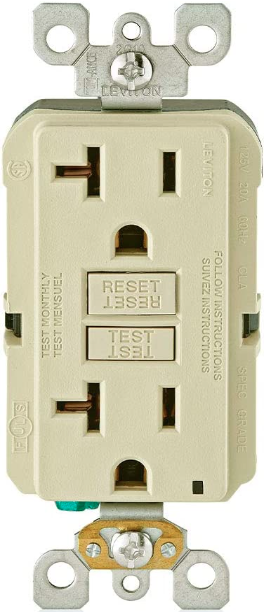
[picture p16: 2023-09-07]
mech/frontpanel/Parts/GFIReceptical.png

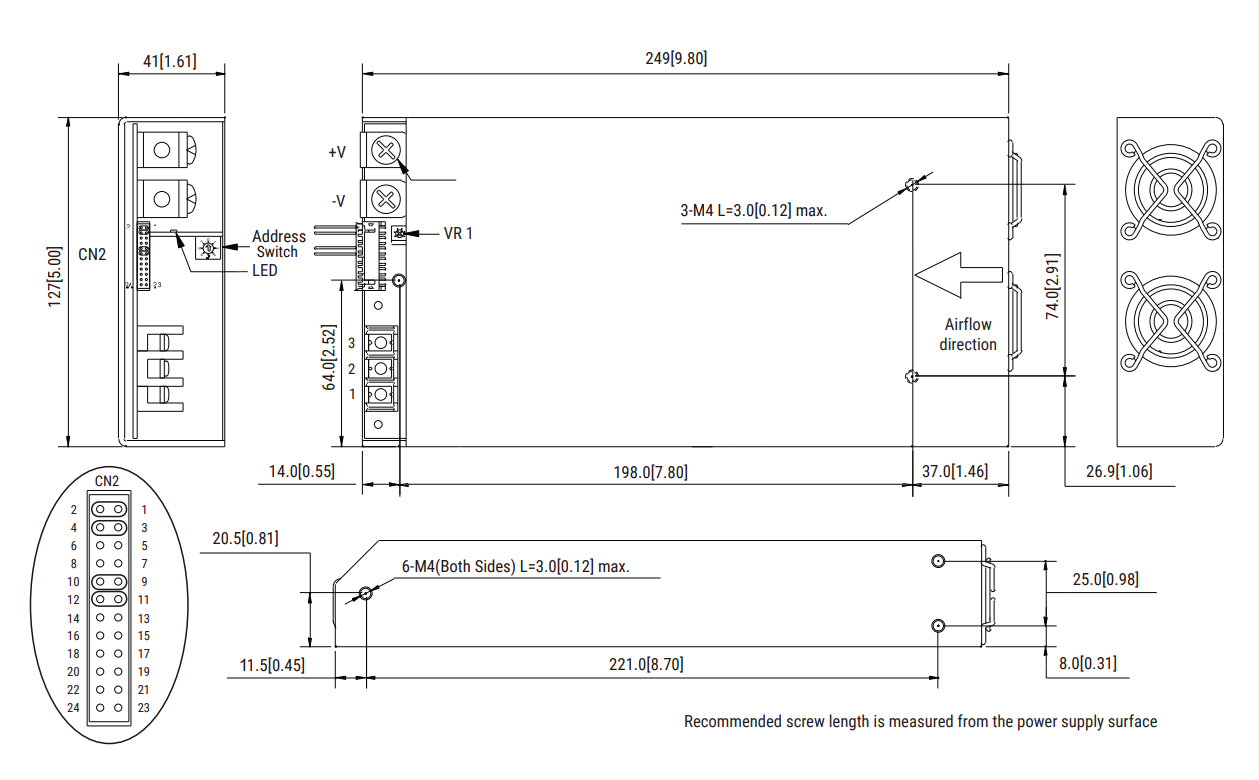
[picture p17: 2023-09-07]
mech/frontpanel/Parts/PowerSupplyDrawing.png

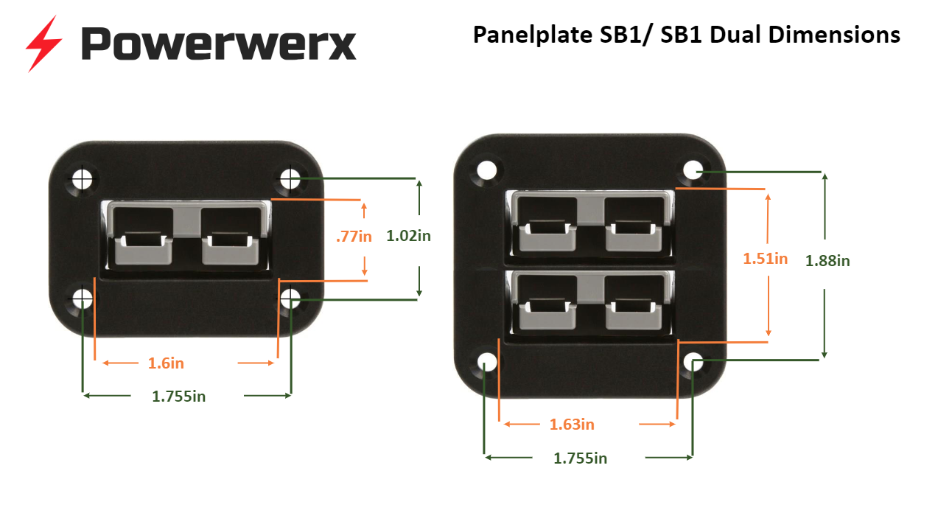
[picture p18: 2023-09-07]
mech/frontpanel/Parts/Anderson/PowererxPanelPlate.png

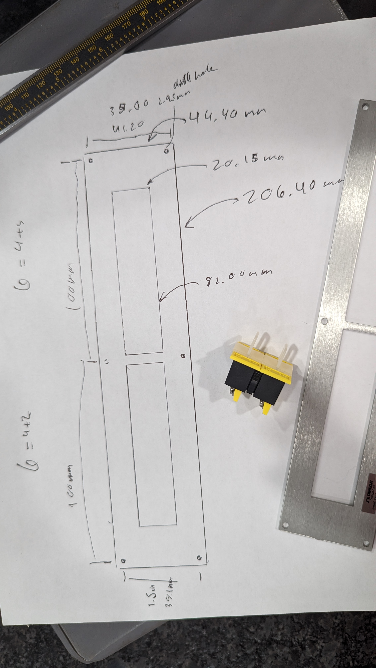
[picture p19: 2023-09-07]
mech/frontpanel/Parts/Mech/mpj-j-f-thermocouple/MJP-12_SketchHand.jpg

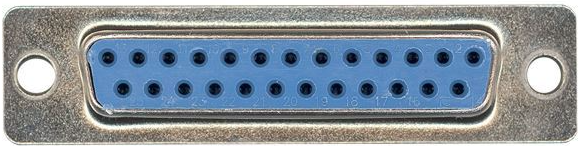
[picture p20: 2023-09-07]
mech/frontpanel/Parts/DB25Female.png

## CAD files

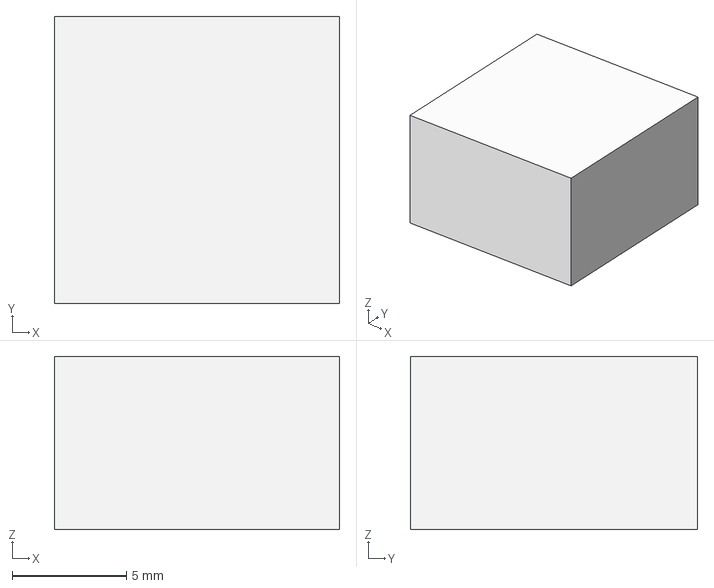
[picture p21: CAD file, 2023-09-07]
elec/fan_I2C/fan_I2C/parts/3D/Cube.step
12.5 x 12.6 x 7.59 mm

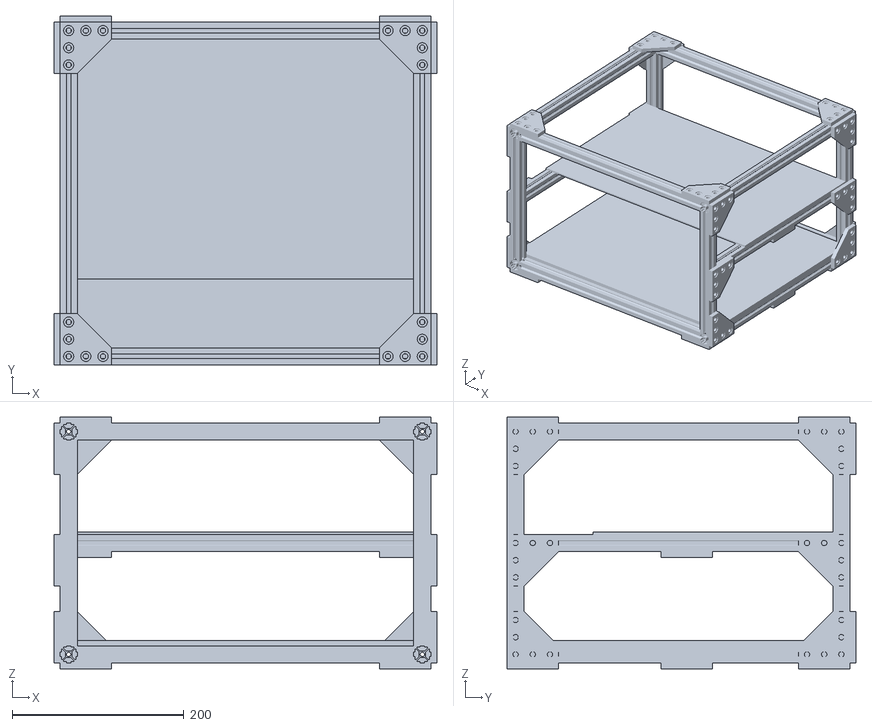
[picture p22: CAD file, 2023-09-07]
mech/enclosure/3D models/enclosure_15.stl
445.8 x 406.4 x 293.4

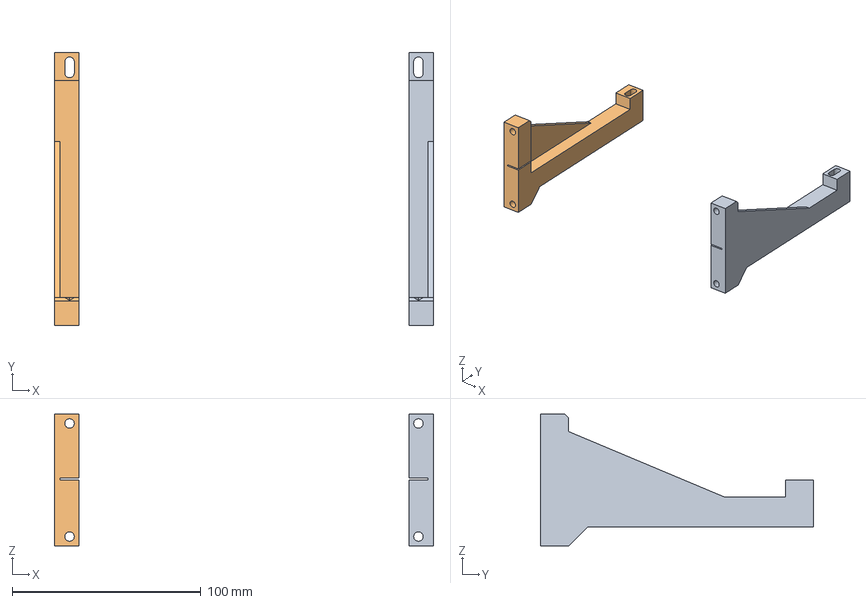
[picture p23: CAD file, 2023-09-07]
mech/enclosure/FreeCADAssy/ControllerSupportRT/ControllerSupportRT.FCStd
201.0 x 145.0 x 70.0 mm
BodySupportRT
CloneBodySupportLR

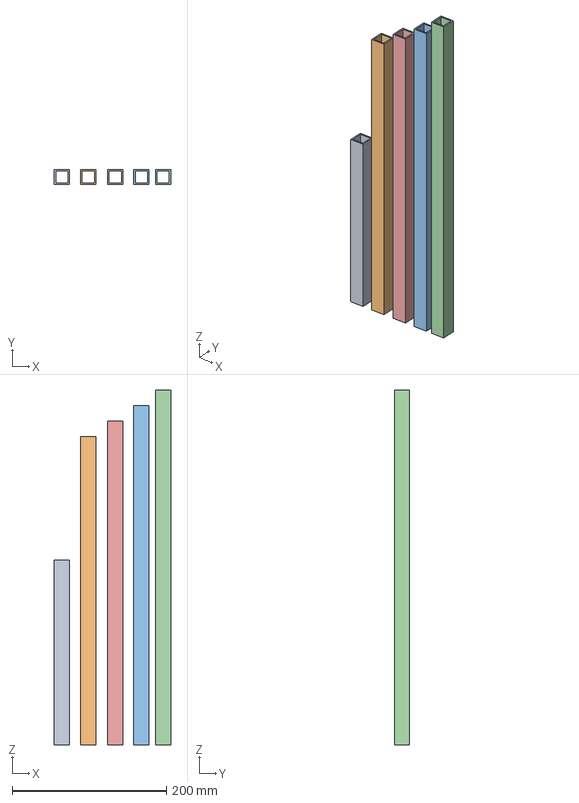
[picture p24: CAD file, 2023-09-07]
mech/enclosure/FreeCADAssy/Extrusions_Simple.FCStd
151.0 x 20.0 x 460.0 mm
Body20x20x240Tube
Body20x20x400Tube
Body20x20x440
Body20x20x460
Body20x20x420Tube

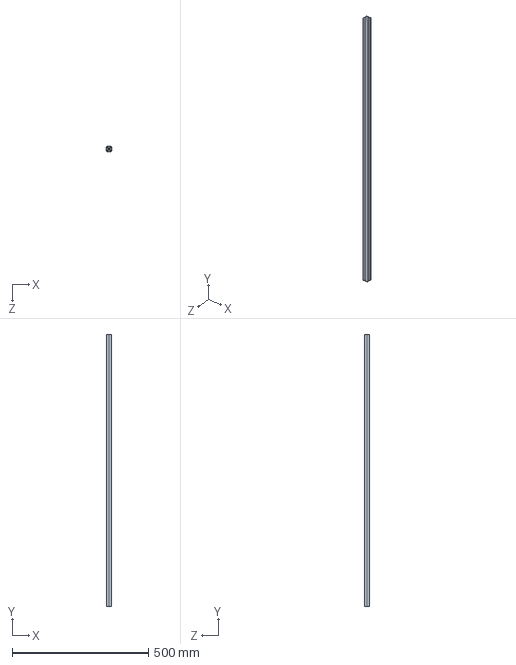
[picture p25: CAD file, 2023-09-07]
mech/enclosure/FreeCADAssy/PartsEnclosure/Aluminium extrusion 20x20x1000.STEP
20.0 x 1000.0 x 20.0 mm

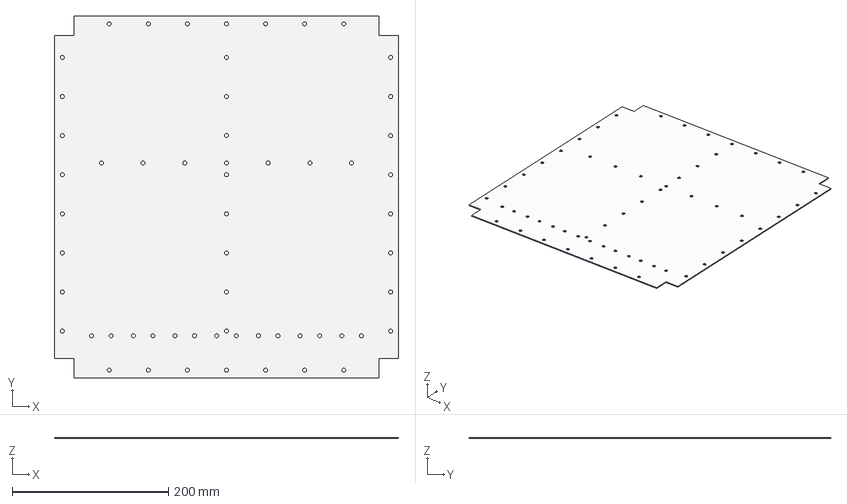
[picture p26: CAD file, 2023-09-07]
mech/frontpanel/frontpanel-PartBottomPlateV2.oBodyBottomPlateV2.step
440.0 x 463.0 x 1.57 mm

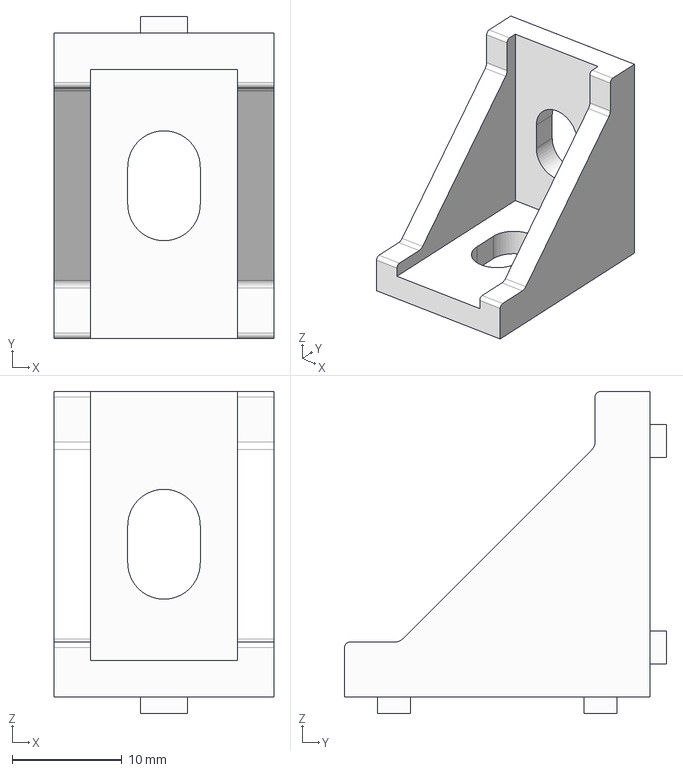
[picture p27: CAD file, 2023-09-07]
mech/frontpanel/Parts/Mech/20X28CornerBracket.step
20.0 x 29.3 x 29.3 mm

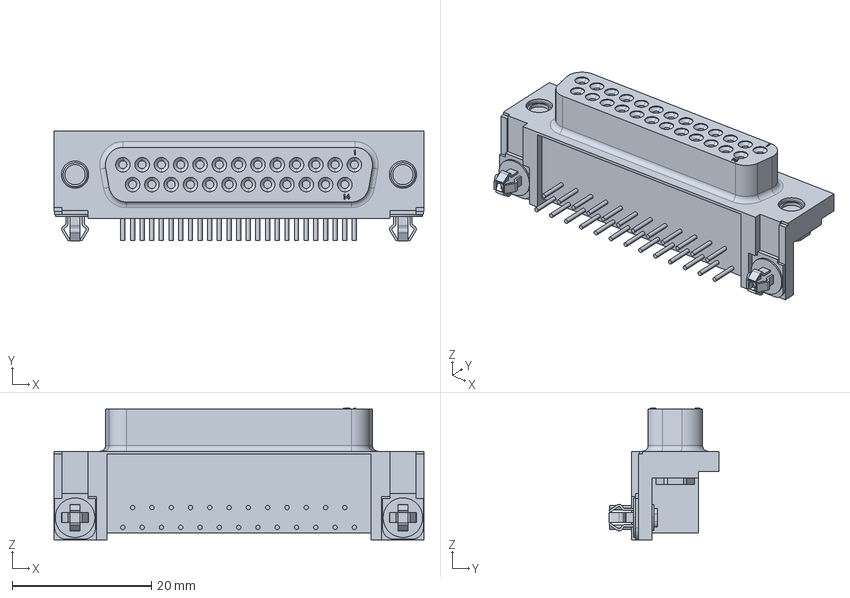
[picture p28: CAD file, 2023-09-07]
mech/frontpanel/Parts/Mech/DB25_DB9/DB25_STEP/c-5747846-4-a-3d.stp
53.1 x 15.8 x 18.9 mm

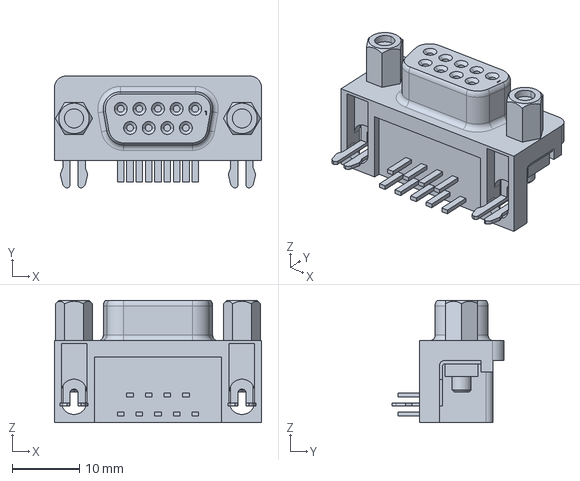
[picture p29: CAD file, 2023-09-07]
mech/frontpanel/Parts/Mech/DB25_DB9/DB9_STEP/c-2311765-1-b-3d.stp
30.8 x 16.6 x 18.2 mm

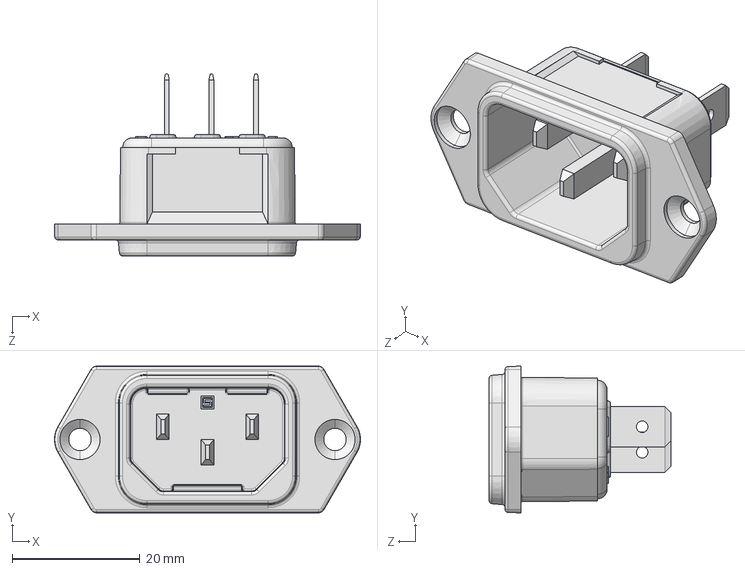
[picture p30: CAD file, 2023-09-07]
mech/frontpanel/Parts/Mech/IEC_Receptical/C14/e_0870.0001i002.step
48.0 x 23.0 x 28.5 mm

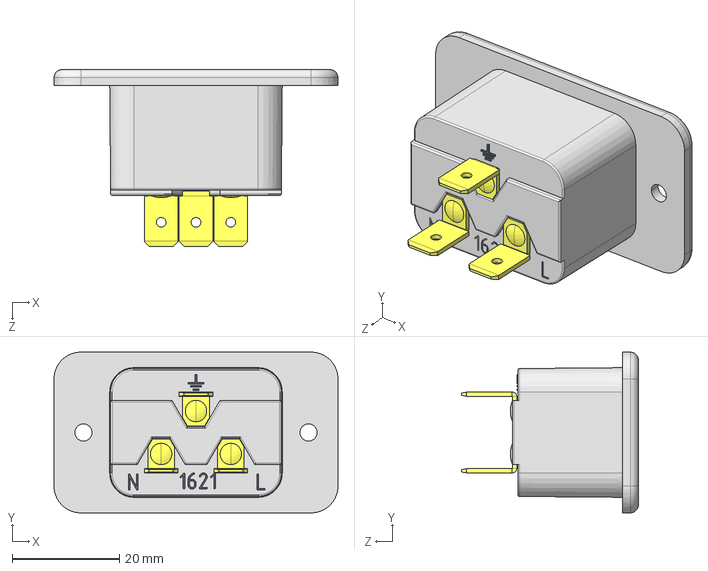
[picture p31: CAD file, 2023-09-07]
mech/frontpanel/Parts/Mech/IEC_Receptical/C20/e_0100.6436a002.step
53.0 x 30.0 x 33.0 mm

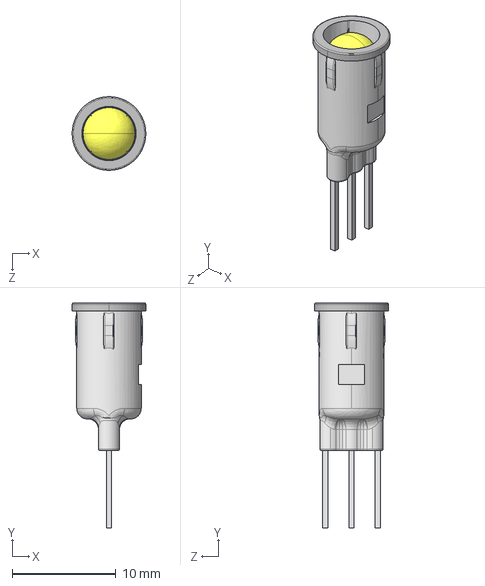
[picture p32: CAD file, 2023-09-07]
mech/frontpanel/Parts/Mech/LIB_PM5R3-BC/PM5R3-BC/3D/PM5R3-BC.stp
7.11 x 21.7 x 7.11 mm
3 lead LED
PM5-3_A1

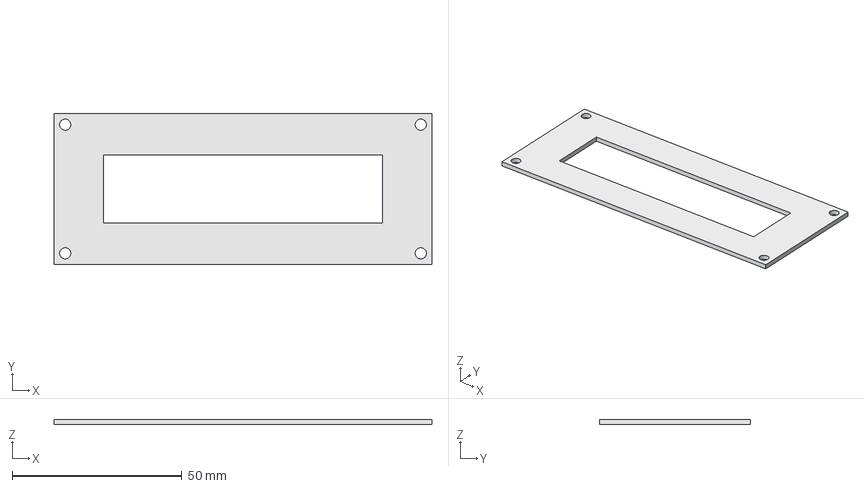
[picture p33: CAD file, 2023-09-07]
mech/frontpanel/Parts/Mech/mpj-j-f-thermocouple/JackPanel_MJP.FCStd
111.3 x 44.4 x 1.59 mm

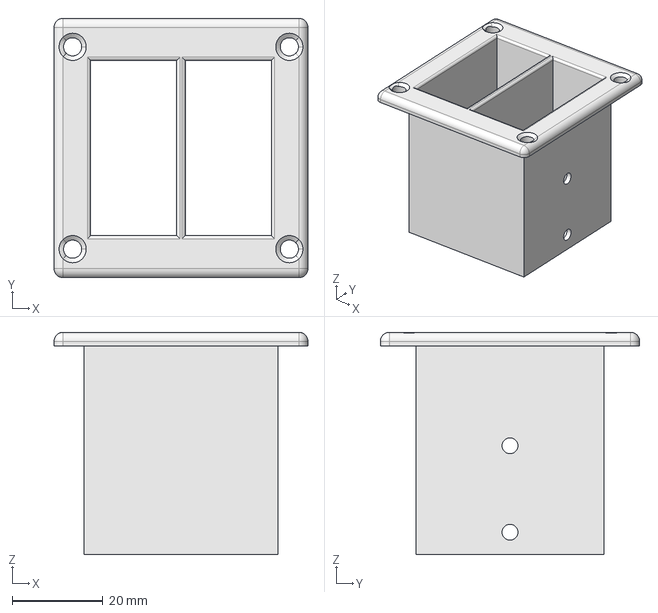
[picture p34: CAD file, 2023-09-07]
mech/frontpanel/Parts/PowerWerx/PanelPlate_SB.FCStd
56.0 x 57.1 x 49.0 mm

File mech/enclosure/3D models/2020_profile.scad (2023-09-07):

/*
***INFO***
Author: slurked
Email: slurked@starlid.com
Version: 1.0
License: Creative Commons Zero (https://creativecommons.org/publicdomain/zero/1.0)



***TO INSTALL***
To use, place this file in your OpenSCAD libraries directory. If you don't know where this is on your computer, go to the file menu and select "Show Library Folder" or check https://en.wikibooks.org/wiki/OpenSCAD_User_Manual/Libraries


***USAGE EXAMPLE***
This generates a 75mm tall 2020 extrusion:

    use <2020_profile.scad>

    linear_extrude(height=75) 2020_profile();


***NOTES***

Please be aware that there are many different variations in real world aluminum extrusions. Differences in tolerances, minor details like corner bevels, and even major variations in the interior cross section are common. This particular model is very basic with square edges.

This is a trivial item, so I have elected to release it into the public domain via the Creative Commons Zero license. No credit, attribution, or permission is needed from me to use this work. Although I would still enjoy hearing about what you put it to use for!

*/

module 2020_profile(){
difference(){
    
    square([20,20],center=true);
    square([17,17],center=true);

    square([40,5.26],center=true);
    rotate([0,0,90]) square([40,5.26],center=true);
}

difference(){
    union(){
        square([7.32,7.32],center=true); 
        rotate([0,0,45]) square([1.5,25],center=true);
        rotate([0,0,-45]) square([1.5,25],center=true);
    }
    circle(d=5,$fn=16);
}

translate([7.9975,7.9975,0]) square([4.005,4.005],center=true);
translate([-7.9975,7.9975,0]) square([4.005,4.005],center=true);
translate([7.9975,-7.9975,0]) square([4.005,4.005],center=true);
translate([-7.9975,-7.9975,0]) square([4.005,4.005],center=true);
}

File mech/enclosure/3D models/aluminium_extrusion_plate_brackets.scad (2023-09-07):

/*
 * Customizable Aluminium Extrusion Brackets - https://www.thingiverse.com/thing:2503622
 * by Dennis Hofmann - https://www.thingiverse.com/mightynozzle/about
 * created 2018-01-26
 * version v1.4
 *
 * Changelog
 * --------------
 * v1.4:
 *      - added tiny straight bracket
 * v1.3.1:
 *      - some fixes and some code cleaning. Thanks goes to Matt Stiegers (Miriax)! 
 * v1.3:
 *      - added library feature. You can use this file in your OpenSCAD project to
 *        add a bracket with a simple call. More information below.
 *        Thanks goes to Matt Stiegers (Miriax) for this suggestion!
 * v1.2:
 *      - added 25mm width option for 25-2525 (80/20 Inc.) extrusions
 * v1.1:
 *      - added 25.4mm width option for qubelok and 1010 (80/20 Inc.) extrusions 
 * v1.0:
 *      - final design
 * --------------
 *
 * This work is licensed under the Creative Commons - Attribution - Non-Commercial license.
 * https://creativecommons.org/licenses/by-nc/3.0/
 */

 /*
 
 Library instructions
 ####################

 Installation:
   - add this OpenSCAD file to the folder of your project
   - add "use <customizable_aluminium_extrusion_plate_bracket.scad>;"
     in the head of your file.
   - add "aluminium_extrusion_bracket();" below in your program section
 
 Usage:
    The module has several parameter to change the bracket. The first value is default:
      - shape = "L", "I", "T" or "X"
      - type = "uniform" (L, T, X type), "tiny" (I type) "short" (all types), "normal" (I type) or "long" (I type)
      - support = "full", "half" or "none" (support only applies to L, T, X type)
      - width_in_millimeter = 20
      - length_in_millimeter = 60
      - bracket_height_in_millimeter = 7.0
      - number_of_rails = 1
      - screw_hole_diameter_in_millimeter = 6.4
      - screw_head_offset_diamter_in_millimeter = 12.0
      - screw_head_offset_height_in_millimeter = 1.5
      - number_of_extra_holes = 1
      - preview_color = "HotPink"
      - center = false, true
      - $fn = 16
 
 Example:
     
     use <customizable_aluminium_extrusion_plate_bracket.scad>;
     aluminium_extrusion_bracket( shape = "T", support = "half", center = true );
   
     This creates a origin centered T-shape bracket with half support.

 */

 // Parameter Section //
//-------------------//

/* [Bracket Settings] */

// Which part do you want to see?
//part = "all_parts__"; //[all_parts__:All Brackets,tiny_straight_bracket__:Tiny Straight Bracket,short_straight_bracket__:Short Straight Bracket,normal_straight_bracket__:Normal Straight Bracket,long_straight_bracket__:Long Straight Bracket,short_l_shape_none_support__:Short L-shape Bracket without support,short_l_shape_half_support__:Short L-shape Bracket with half support,short_l_shape_full_support__:Short L-shape Bracket with full support,uniform_l_shape_none_support__:Uniform L-shape Bracket without support,uniform_l_shape_half_support__:Uniform L-shape Bracket with half support,uniform_l_shape_full_support__:Uniform L-shape Bracket with full support,short_t_shape_none_support__:Short T-shape Bracket without  support,short_t_shape_half_support__:Short T-shape Bracket with half support,short_t_shape_full_support__:Short T-shape Bracket with full support,uniform_t_shape_none_support__:Uniform T-shape Bracket without support,uniform_t_shape_half_support__:Uniform T-shape Bracket with half support,uniform_t_shape_full_support__:Uniform T-shape Bracket with full support,short_x_shape_none_support__:Short X-shape Bracket without support,short_x_shape_half_support__:Short X-shape Bracket with half support,short_x_shape_full_support__:Short X-shape Bracket with full support,uniform_x_shape_none_support__:Uniform X-shape Bracket without support,uniform_x_shape_half_support__:Uniform X-shape Bracket with half support,uniform_x_shape_full_support__:Uniform X-shape Bracket with full support]

// Set the width of the aluminium extrusion. If you have e.g. a 2020 one, set 20mm. If you have e.g. a 2040 one, it depends on which side you want to mount the bracket --> set 20mm or 40mm
width_in_millimeter = 20; //[20,25,25.4,30,40,45,60,80,90,120,160]

// The length of the L-bracket and the short side of the T-bracket. The length of the straight bracket, the X-bracket and the longer side of the T-bracket equals two times of the L-bracket length minus the width of the aluminium extrusion.
length_in_millimeter = 60; //[1:200]

// The height/thickness of the bracket.
bracket_height_in_millimeter = 7.0; //[0.1:0.1:30]

// Set the number of rails/slots of the aluminium extrusion. A 2020 one has one rail per side, a 2040 have one rail or two rails.
number_of_rails = 1; //[1:1:4]

// Set 4.3 for M4, 5.3 for M5, 6.4 for M6, 8.4 for M8, 10.5 for M10 screws
screw_hole_diameter_in_millimeter = 6.4;

// If you want to use a ISO7009/DIN125 washer, set 9.5 for M4, 10.5 for M5, 12.5 for M5, 16.5 for M8, 20.5 for M10... Or if you don't want to use a washer, just measure the diameter of the screw head and type it in here.
screw_head_offset_diamter_in_millimeter = 12.0;

// If you want to cover the screw head completly, you can measure the height of the head of the screws and set it here. Don't forget to add the thickness of the washer! If you set a high value or maybe a higher value than the height of the bracket, you should also increase the bracket height.
screw_head_offset_height_in_millimeter = 1.5;

// If you need only the outer holes, then set 0. But it also makes the short type brackets unsuable.
number_of_extra_holes = 1; //[0:1:4]


 // Program Section //
//-----------------//
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

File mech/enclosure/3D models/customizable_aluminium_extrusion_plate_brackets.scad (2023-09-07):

/*
 * Customizable Aluminium Extrusion Brackets - https://www.thingiverse.com/thing:2503622
 * by Dennis Hofmann - https://www.thingiverse.com/mightynozzle/about
 * created 2018-01-26
 * version v1.4
 *
 * Changelog
 * --------------
 * v1.4:
 *      - added tiny straight bracket
 * v1.3.1:
 *      - some fixes and some code cleaning. Thanks goes to Matt Stiegers (Miriax)! 
 * v1.3:
 *      - added library feature. You can use this file in your OpenSCAD project to
 *        add a bracket with a simple call. More information below.
 *        Thanks goes to Matt Stiegers (Miriax) for this suggestion!
 * v1.2:
 *      - added 25mm width option for 25-2525 (80/20 Inc.) extrusions
 * v1.1:
 *      - added 25.4mm width option for qubelok and 1010 (80/20 Inc.) extrusions 
 * v1.0:
 *      - final design
 * --------------
 *
 * This work is licensed under the Creative Commons - Attribution - Non-Commercial license.
 * https://creativecommons.org/licenses/by-nc/3.0/
 */

 /*
 
 Library instructions
 ####################

 Installation:
   - add this OpenSCAD file to the folder of your project
   - add "use <customizable_aluminium_extrusion_plate_bracket.scad>;"
     in the head of your file.
   - add "aluminium_extrusion_bracket();" below in your program section
 
 Usage:
    The module has several parameter to change the bracket. The first value is default:
      - shape = "L", "I", "T" or "X"
      - type = "uniform" (L, T, X type), "tiny" (I type) "short" (all types), "normal" (I type) or "long" (I type)
      - support = "full", "half" or "none" (support only applies to L, T, X type)
      - width_in_millimeter = 20
      - length_in_millimeter = 60
      - bracket_height_in_millimeter = 7.0
      - number_of_rails = 1
      - screw_hole_diameter_in_millimeter = 6.4
      - screw_head_offset_diamter_in_millimeter = 12.0
      - screw_head_offset_height_in_millimeter = 1.5
      - number_of_extra_holes = 1
      - preview_color = "HotPink"
      - center = false, true
      - $fn = 16
 
 Example:
     
     use <customizable_aluminium_extrusion_plate_bracket.scad>;
     aluminium_extrusion_bracket( shape = "T", support = "half", center = true );
   
     This creates a origin centered T-shape bracket with half support.

 */

 // Parameter Section //
//-------------------//

/* [Bracket Settings] */

// Which part do you want to see?
part = "all_parts__"; //[all_parts__:All Brackets,tiny_straight_bracket__:Tiny Straight Bracket,short_straight_bracket__:Short Straight Bracket,normal_straight_bracket__:Normal Straight Bracket,long_straight_bracket__:Long Straight Bracket,short_l_shape_none_support__:Short L-shape Bracket without support,short_l_shape_half_support__:Short L-shape Bracket with half support,short_l_shape_full_support__:Short L-shape Bracket with full support,uniform_l_shape_none_support__:Uniform L-shape Bracket without support,uniform_l_shape_half_support__:Uniform L-shape Bracket with half support,uniform_l_shape_full_support__:Uniform L-shape Bracket with full support,short_t_shape_none_support__:Short T-shape Bracket without  support,short_t_shape_half_support__:Short T-shape Bracket with half support,short_t_shape_full_support__:Short T-shape Bracket with full support,uniform_t_shape_none_support__:Uniform T-shape Bracket without support,uniform_t_shape_half_support__:Uniform T-shape Bracket with half support,uniform_t_shape_full_support__:Uniform T-shape Bracket with full support,short_x_shape_none_support__:Short X-shape Bracket without support,short_x_shape_half_support__:Short X-shape Bracket with half support,short_x_shape_full_support__:Short X-shape Bracket with full support,uniform_x_shape_none_support__:Uniform X-shape Bracket without support,uniform_x_shape_half_support__:Uniform X-shape Bracket with half support,uniform_x_shape_full_support__:Uniform X-shape Bracket with full support]

// Set the width of the aluminium extrusion. If you have e.g. a 2020 one, set 20mm. If you have e.g. a 2040 one, it depends on which side you want to mount the bracket --> set 20mm or 40mm
width_in_millimeter = 20; //[20,25,25.4,30,40,45,60,80,90,120,160]

// The length of the L-bracket and the short side of the T-bracket. The length of the straight bracket, the X-bracket and the longer side of the T-bracket equals two times of the L-bracket length minus the width of the aluminium extrusion.
length_in_millimeter = 60; //[1:200]

// The height/thickness of the bracket.
bracket_height_in_millimeter = 7.0; //[0.1:0.1:30]

// Set the number of rails/slots of the aluminium extrusion. A 2020 one has one rail per side, a 2040 have one rail or two rails.
number_of_rails = 1; //[1:1:4]

// Set 4.3 for M4, 5.3 for M5, 6.4 for M6, 8.4 for M8, 10.5 for M10 screws
screw_hole_diameter_in_millimeter = 6.4;

// If you want to use a ISO7009/DIN125 washer, set 9.5 for M4, 10.5 for M5, 12.5 for M5, 16.5 for M8, 20.5 for M10... Or if you don't want to use a washer, just measure the diameter of the screw head and type it in here.
screw_head_offset_diamter_in_millimeter = 12.0;

// If you want to cover the screw head completly, you can measure the height of the head of the screws and set it here. Don't forget to add the thickness of the washer! If you set a high value or maybe a higher value than the height of the bracket, you should also increase the bracket height.
screw_head_offset_height_in_millimeter = 1.5;

// If you need only the outer holes, then set 0. But it also makes the short type brackets unsuable.
number_of_extra_holes = 1; //[0:1:4]


 // Program Section //
//-----------------//
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

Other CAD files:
elec/fan_I2C/fan_I2C/parts/3D/Amphenol_54601_RT_ANGLE.step
mech/enclosure/3D models/enclosure.stl
mech/enclosure/FreeCADAssy/ControllerSupportRT/ControllerSupportRT-PartBodySupportRT.step
mech/frontpanel/Parts/Mech/Gusseted 2020 corner bracket v2.step
mech/enclosure/3D models/enclosure.scad
mech/enclosure/3D models/enclosure_15.scad
mech/enclosure/3D models/enclosure_24.scad
mech/enclosure/FreeCADAssy/ControllerSupportRT/ControllerSupportRT-CloneBodySupportLR.step
mech/enclosure/FreeCADAssy/ControllerSupportRT/ControllerSupportRT-CloneBodySupportLR.stl
mech/enclosure/FreeCADAssy/ControllerSupportRT/ControllerSupportRT-PartBodySupportRT.stl
mech/frontpanel/BottomPlateV1 edit.dxf
mech/frontpanel/BottomPlateV1.dxf
mech/frontpanel/BottomPlateV1.step
mech/frontpanel/BottomPlateV1.stl
mech/frontpanel/Parts/Mech/Decora cover v5.step
mech/frontpanel/Parts/Mech/alu extrusion profile 2020.step
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

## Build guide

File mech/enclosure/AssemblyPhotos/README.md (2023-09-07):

## File Descriptions / Quick View
This folder contains information related to the OEDCS **Serial_number1** build.

Memories of how this was assembled in March 2023

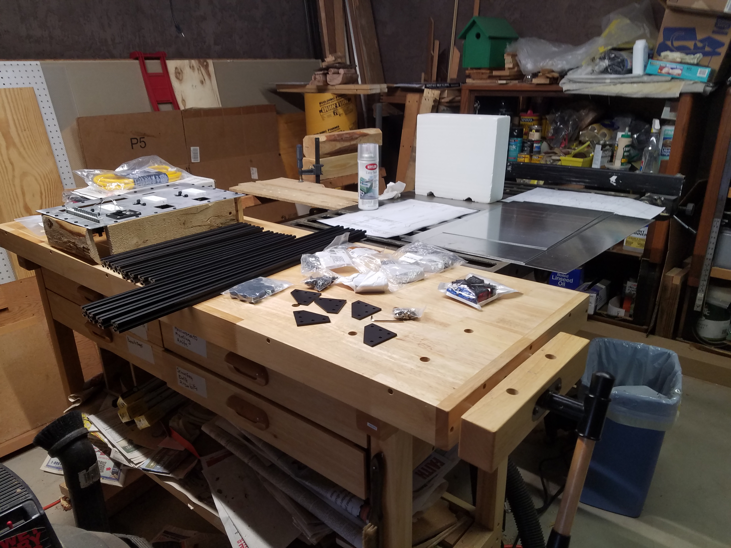
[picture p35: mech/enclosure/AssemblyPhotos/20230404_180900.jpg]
   
Front panel was assembled with components first.  
Other parts staged for start of assembly.  

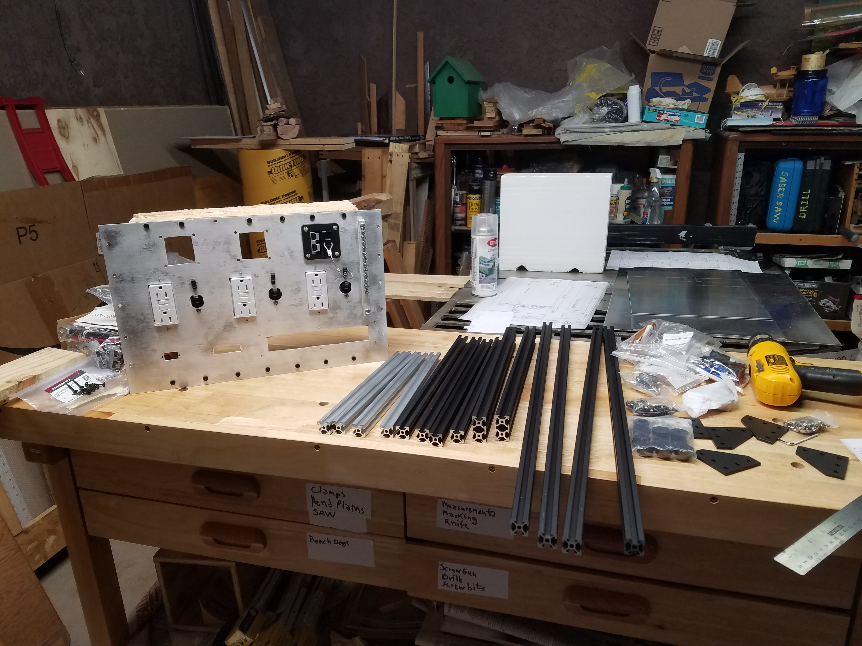
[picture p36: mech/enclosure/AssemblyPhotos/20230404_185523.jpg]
 

Parts staged for start of assembly

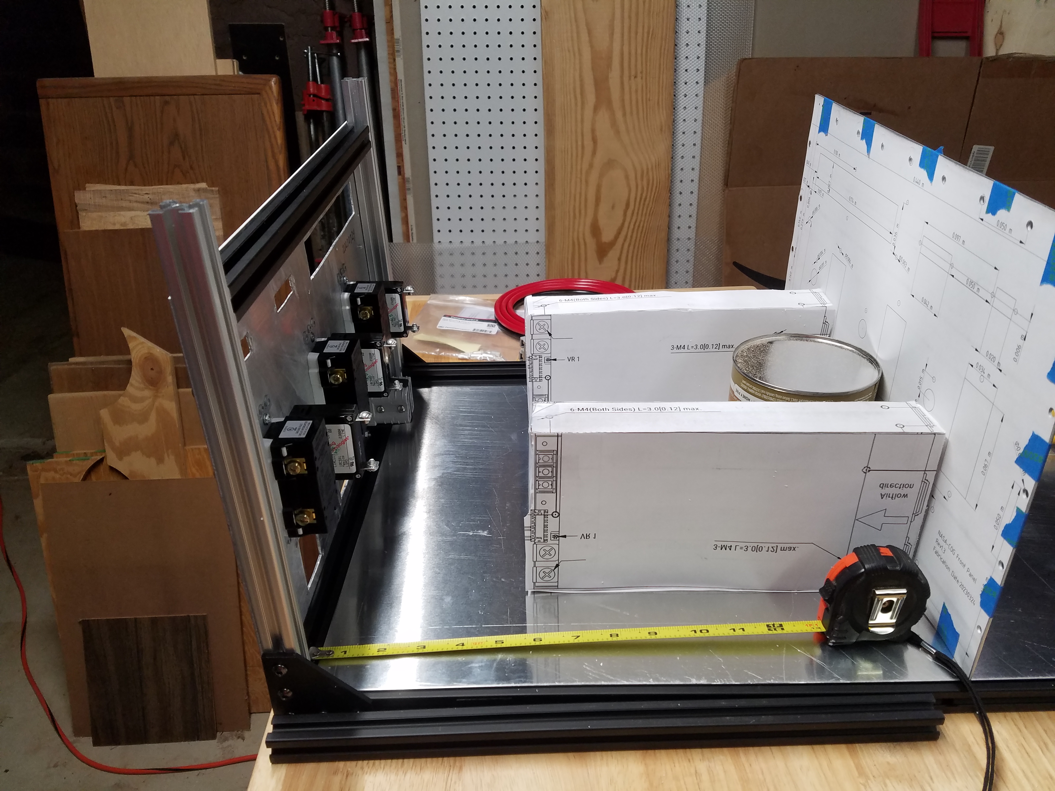
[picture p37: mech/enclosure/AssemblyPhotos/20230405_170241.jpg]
 

During efforts to decide the length of the cabnet.  
The bottom panel long dimension was set to 463mm. 

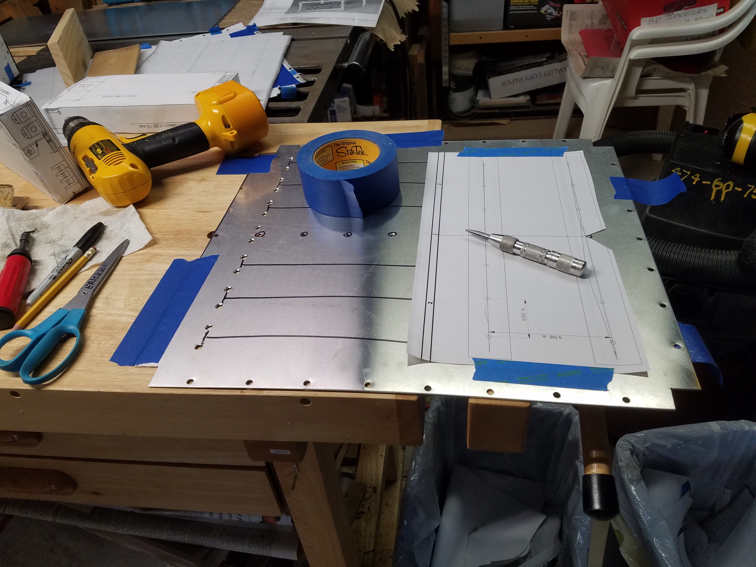
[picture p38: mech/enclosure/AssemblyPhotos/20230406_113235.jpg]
  
Prepairing to center punch the front DIN rail holes

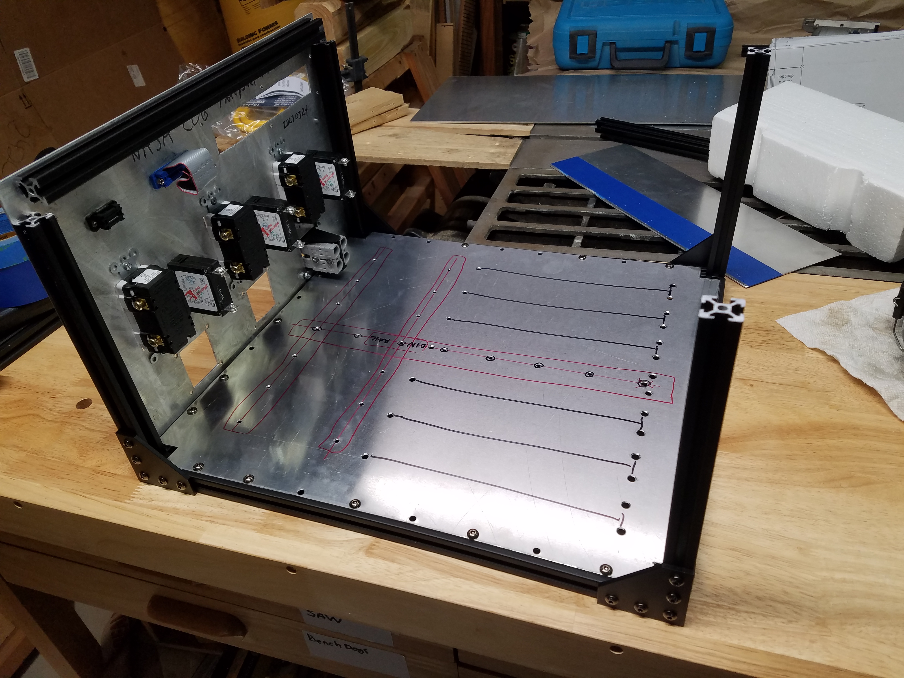
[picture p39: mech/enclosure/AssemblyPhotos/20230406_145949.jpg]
  
After punching DIN rail holes.  Red outlines the proposed approximat location of the DIN rails.

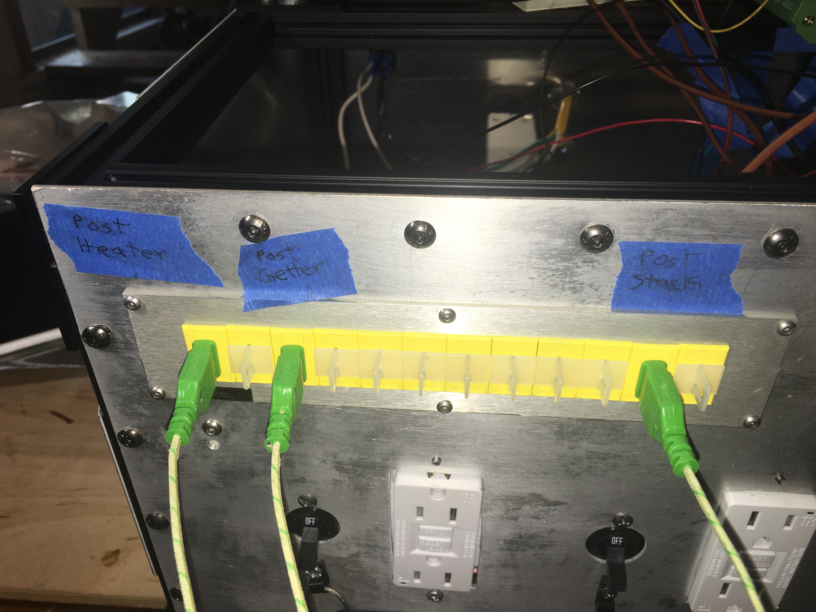
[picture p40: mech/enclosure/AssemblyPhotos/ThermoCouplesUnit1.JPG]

Detail of the thermocouple jack panel.

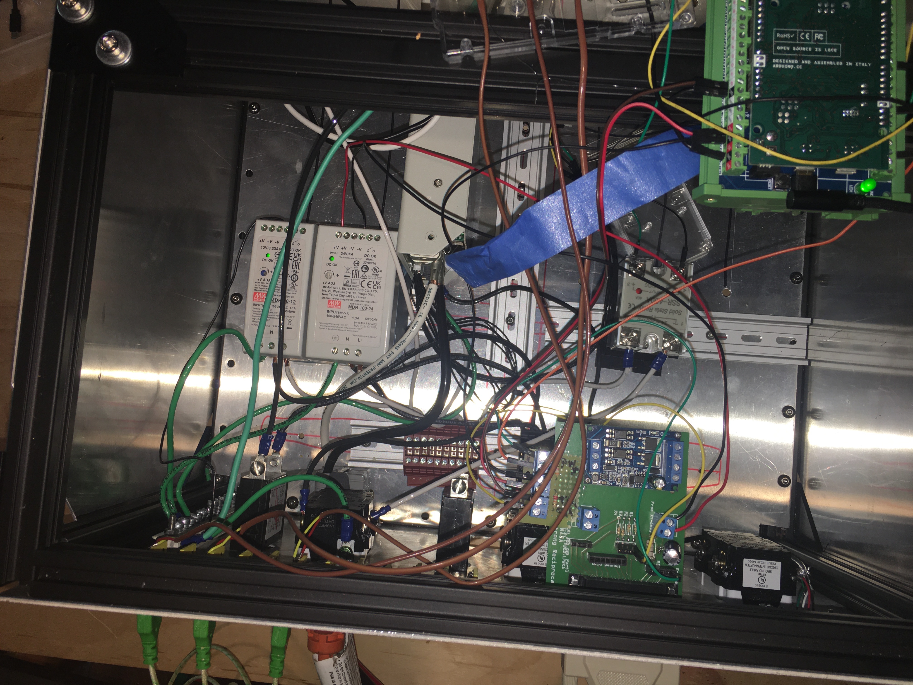
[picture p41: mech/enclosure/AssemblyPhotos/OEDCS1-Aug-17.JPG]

Overhead view of OEDCS1-Aug-17.JPG

### Videos made during assembly

[20230405_164525.mp4](20230405_164525.mp4)

[20230405_165244.mp4](20230405_165244.mp4)

[20230405_165423.mp4](20230405_165423.mp4)

[20230405_224931.mp4](20230405_224931.mp4)

[20230407_164746.mp4](20230407_164746.mp4)

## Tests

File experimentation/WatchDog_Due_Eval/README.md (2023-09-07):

# Watchdog and Save Some Variables Through Reset
This is a Proof or Concept 
Combined watchdog funcation and Flash memory storage of some variabls representing states.

Screenshot showing the first boot after programing and then some resets (watchdog time out)
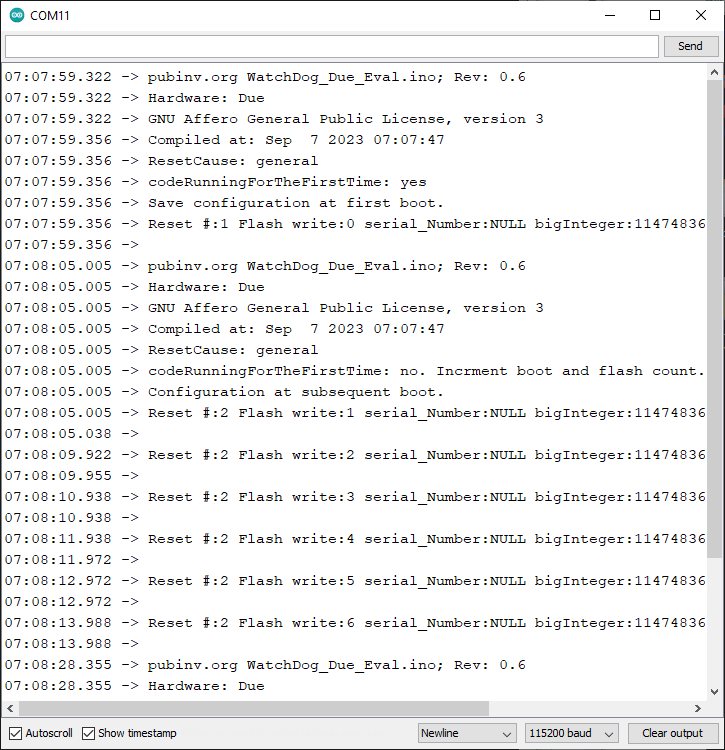
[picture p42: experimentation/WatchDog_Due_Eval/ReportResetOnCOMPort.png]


### TODO
* Needs to count power on reset and watchdog resets independantly
* Make function to report Reset #
* Make function to report Watchdog #
* Make some functions to update states.

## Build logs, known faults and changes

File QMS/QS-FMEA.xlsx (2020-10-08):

 | Failure Modes and Effects Analysis
 | Oxygen Concentrator
 | Failure Mode | Effects | Severity | Probability | Risk Management
1 | Power loss
2 | Oxygen leak
3 | Excess moisture
4 | Leaking hose
5 | Leaking o-ring
6 | Overheating electronics
7 | Dropped by user
8 | Knocked over by user
9 | Over pressure
10 | Under pressure
11 | Blocked pneumatics
12 | Sieve spring failure
13 | Touch screen failure
14 | Touch screen damage
15 | Exhaust fan failure
16 | Blocked HEPA filter
17 | Electromagnet interference
18 | Solenoid valve failure
19 | Power supply failure
20 | Oxygen sensor misreading
21 | Air leak
22 | Oil in air lines
23 | Valve seal/or-ing shedding
24 | Faulty component
25 | Deteriorated valve
26 | Slow responding valve
27 | Short circuit
28 | Pressure vessel scratched or dented
29 | Loose wiring connection
30 | Over torqued threaded fitting
31 | Under torqued threading fitting
32 | Non-square pneumatic tubing cut
33 | Burr on pneumatic tubing cut
34 | Cut or scuff on pneumatic tubing
35 | Crushed pneumatic tubing
36 | Twisted pneumatic tubing
37 | Excessive pressure
38 | Low pressure
39 | Moisture damaged zeolite
40 | Zeolite sieve spring failure
41 | Zeolite sieve air distributor failure
42 | Zeolite sieve filter blocked
43 | Zeolite sieve dust contaminates air supply
44 | Zeolite sieve dust acts as abrasive
45 | Zeolite sieve compaction
46 | Unbalanced sieve pressure drop
47 | Oil contamination
48 | Carbon dioxide
49 | Carbon monoxide
50 | Environmental gas contamination
51 | Excessive nitrogen production
52 | Incorrect assembly
53 | Incorrect maintenance
54 | Low oxygen concentration
55 | Incorrect sensor reading
56 | Compressor failure
57 | Chiller/drier failure

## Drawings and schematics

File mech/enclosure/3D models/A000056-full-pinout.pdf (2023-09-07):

# Digital pins D22-D53

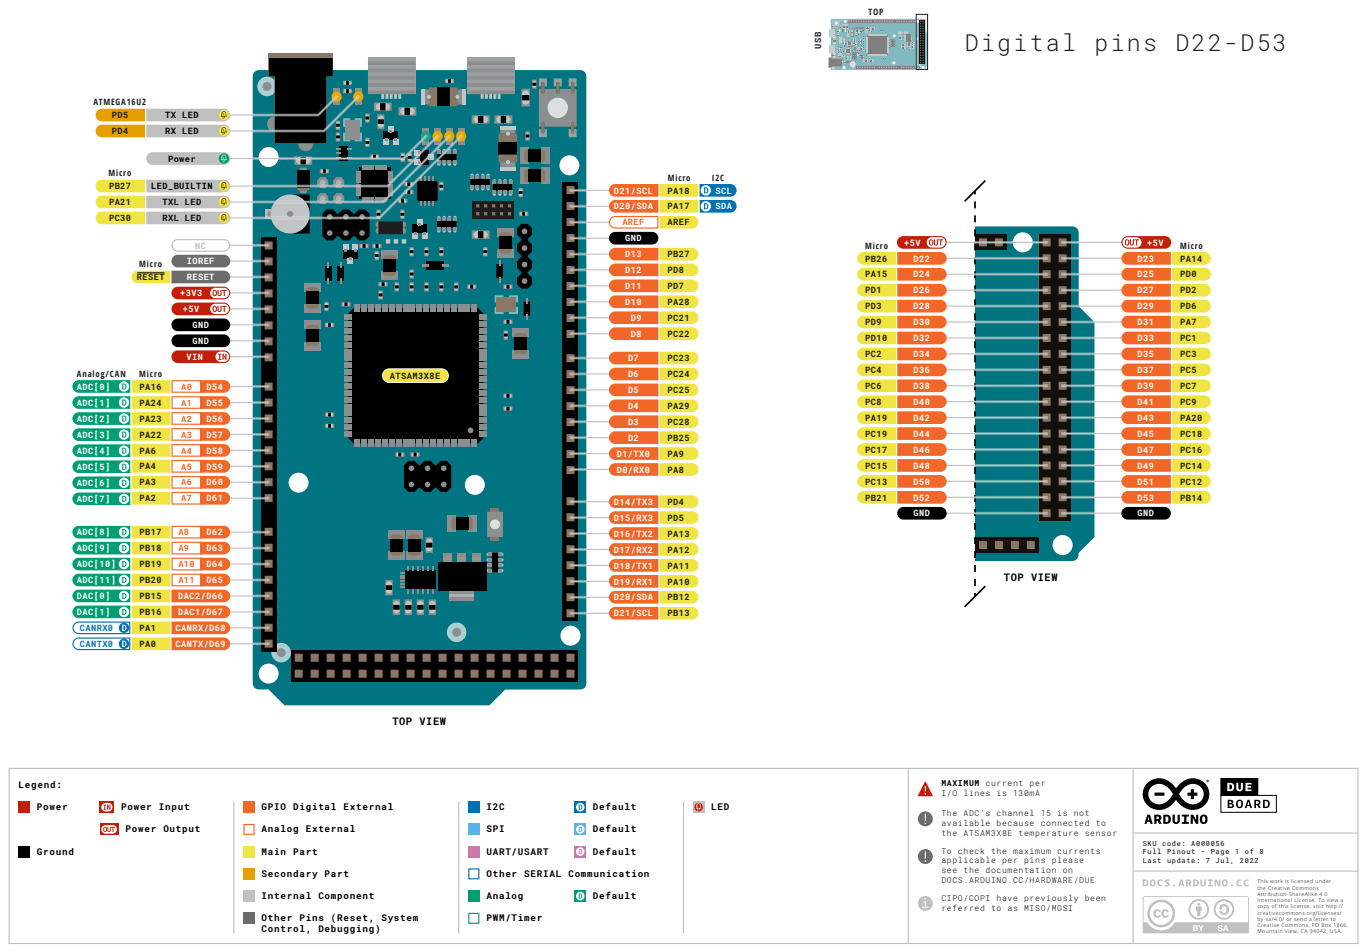
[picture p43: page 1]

MAXIMUM current per
I/O lines is 130mA
The ADC’s channel 15 is not
available because connected to
the ATSAM3X8E temperature sensor
To check the maximum currents
applicable per pins please
see the documentation on
DOCS.ARDUINO.CC/HARDWARE/DUE
CIPO/COPI have previously been
referred to as MISO/MOSI

GPIO Digital External
Analog External
Main Part
Secondary Part
Internal Component
Other Pins (Reset, System
Control, Debugging)

SKU code: A000056
Full Pinout - Page 1 of 8
Last update: 7 Jul, 2022

This work is licensed under
the Creative Commons
Attribution-ShareAlike 4.0
International License. To view a
copy of this license, visit http://
creativecommons.org/licenses/
by-sa/4.0/ or send a letter to
Creative Commons, PO Box 1866,
Mountain View, CA 94042, USA.

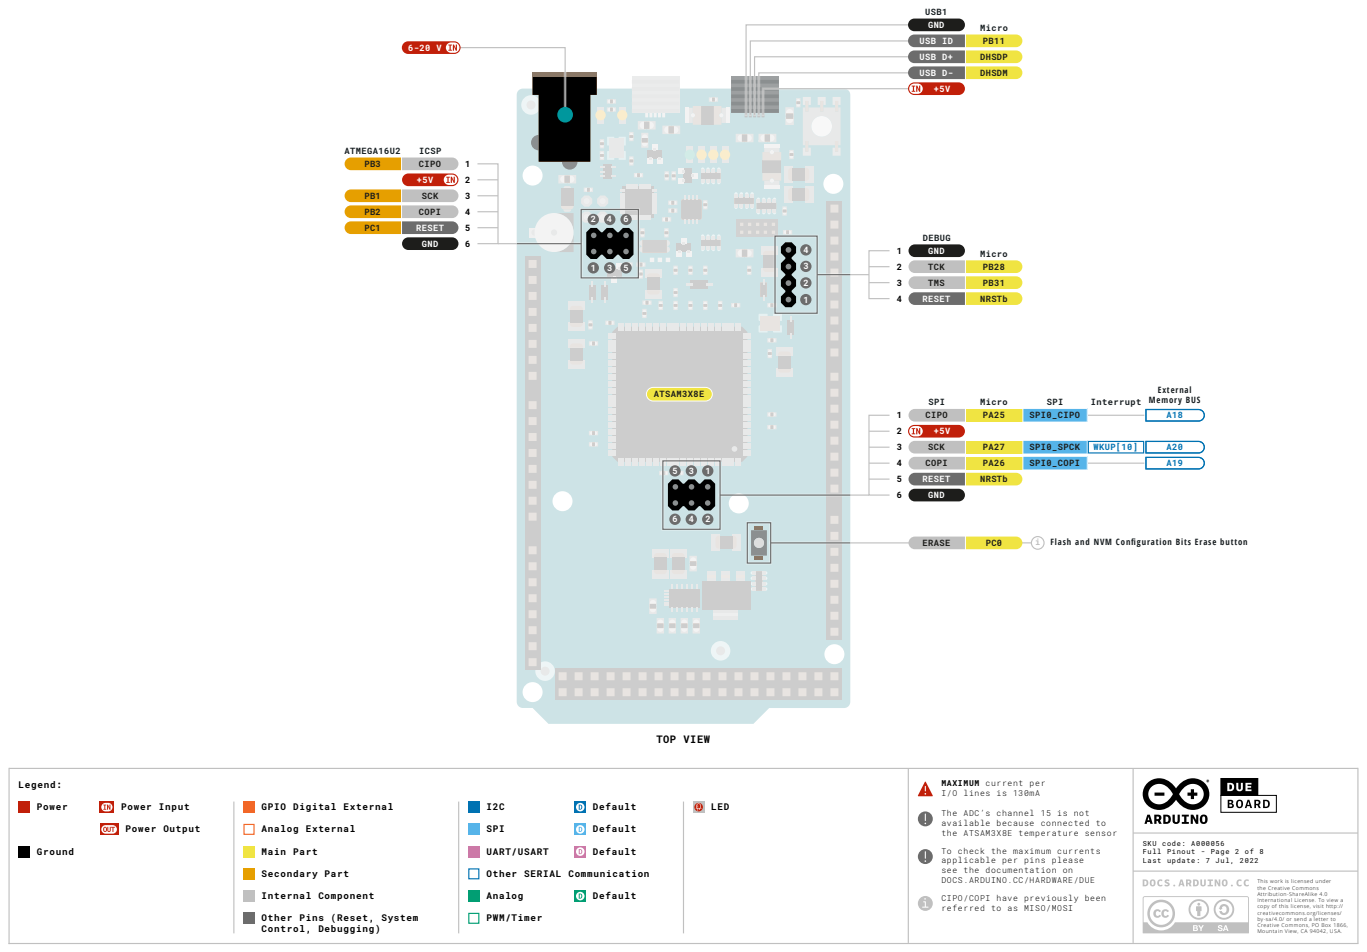
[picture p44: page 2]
Legend:; Power; Power Input; Power Output; Ground; Default; SPI; UART/USART; LED; TOP VIEW; USB D-; USB D+; USB ID; GND; DHSDM; DHSDP; PA27 PA26 NRSTb; i Flash and NVM Configuration Bits Erase button; CIPO; SCK COPI RESET GND; DEBUG; Micro; Interrupt; USB1; SPI0_CIPO; SPI0_SPCK SPI0_COPI; WKUP[10]; External Memory BUS; ATMEGA16U2; ICSP; ERASE; RESET; NRSTb; TMS; TCK; ATSAM3X8E

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

GPIO Digital External
Analog External
Main Part
Secondary Part

Other SERIAL Communication

SKU code: A000056
Full Pinout - Page 2 of 8
Last update: 7 Jul, 2022

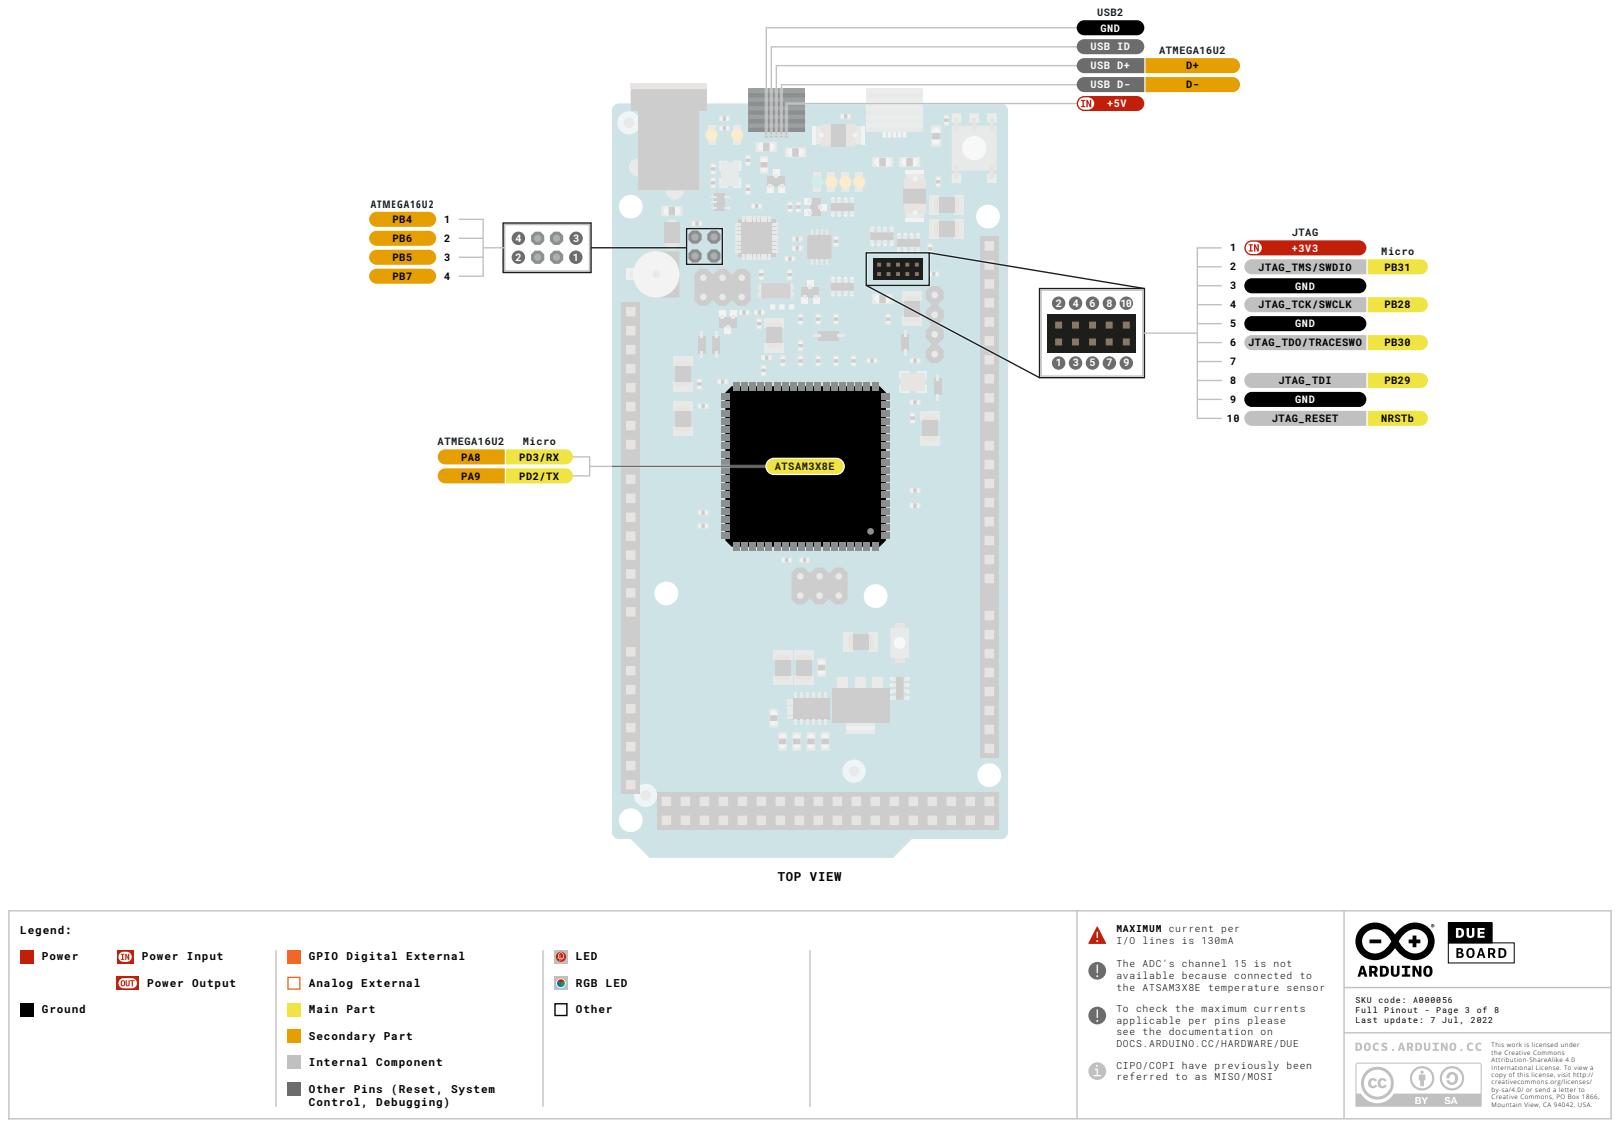
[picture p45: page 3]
Legend:; Power; Power Input; Power Output; Ground; LED; RGB LED; Other; TOP VIEW; ATMEGA16U2 PB4 PB6 PB5 PB7; ATMEGA16U2; Micro; USB D-; USB D+; NRSTb; JTAG; JTAG_TMS/SWDIO GND JTAG_TCK/SWCLK GND JTAG_TDO/TRACESWO; JTAG_TDI; JTAG_RESET; GND; USB ID; USB2; ATSAM3X8E

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

GPIO Digital External
Analog External
Main Part
Secondary Part

SKU code: A000056
Full Pinout - Page 3 of 8
Last update: 7 Jul, 2022

# WARNING!

# Advanced Section

# The following information is for advanced use only and may not be officially supported by Arduino software

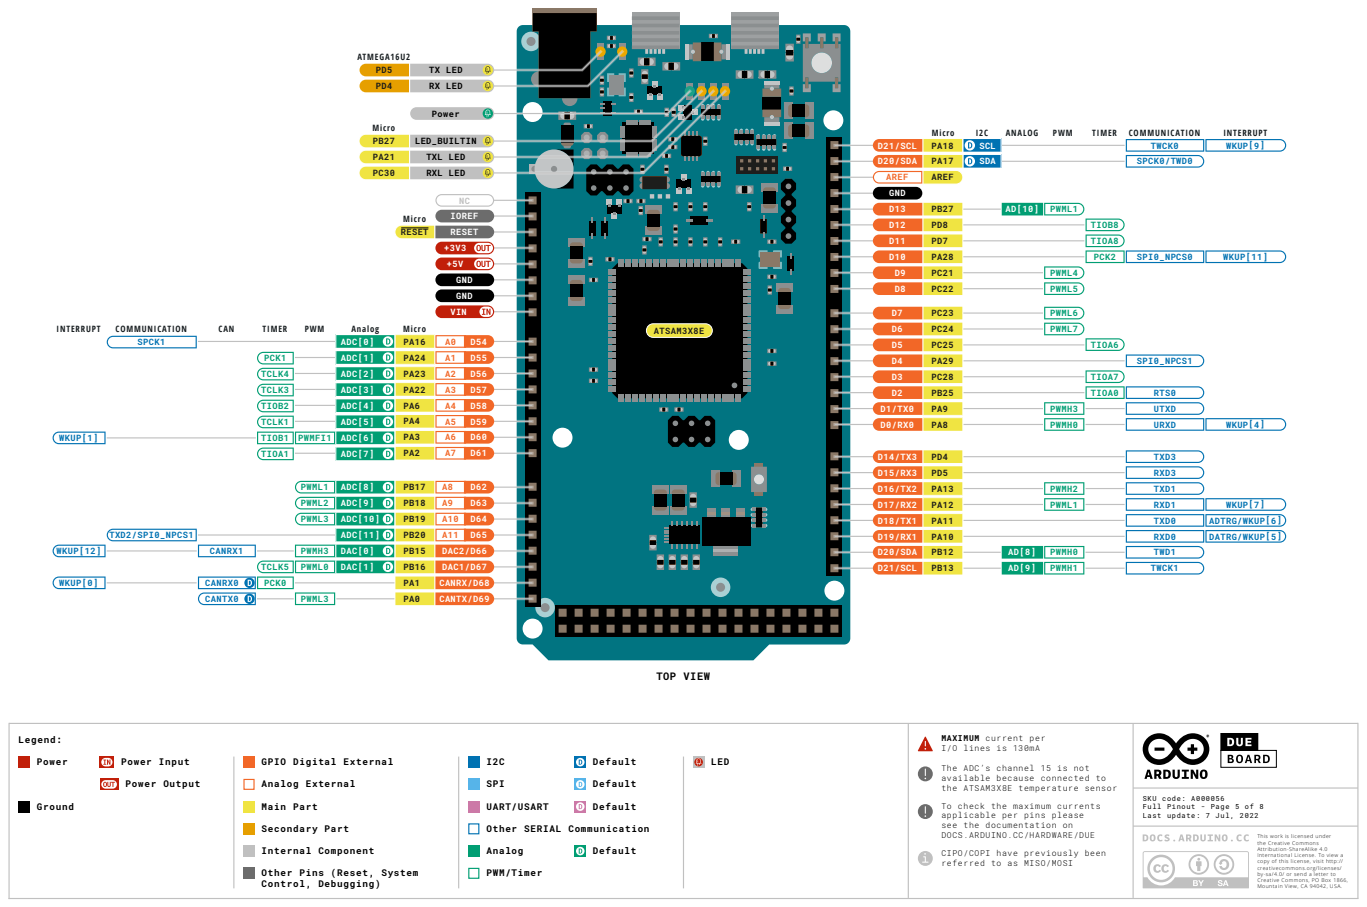
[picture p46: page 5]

ADC[0] | PA16
ADC[1] | PA24

ADC[4] | PA6
ADC[5] | PA4

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

SKU code: A000056
Full Pinout - Page 5 of 8
Last update: 7 Jul, 2022

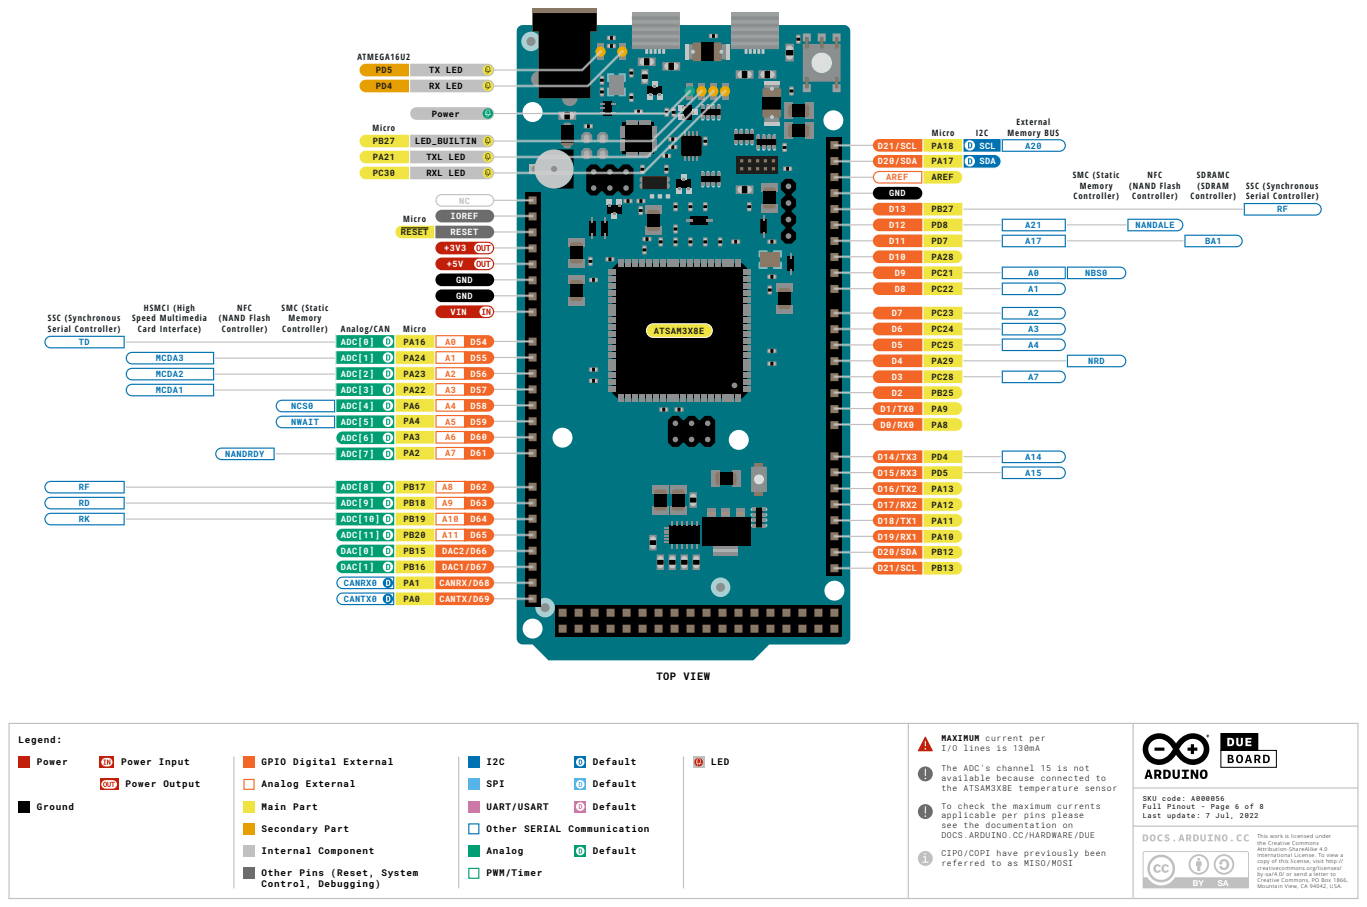
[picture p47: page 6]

ADC[0] | PA16
ADC[1] | PA24

ADC[3] | PA22
ADC[4] | PA6
ADC[5] | PA4

ADC[8] | PB17
ADC[9] | PB18
ADC[10] | PB19

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

SKU code: A000056
Full Pinout - Page 6 of 8
Last update: 7 Jul, 2022

# Digital pins D22-D53

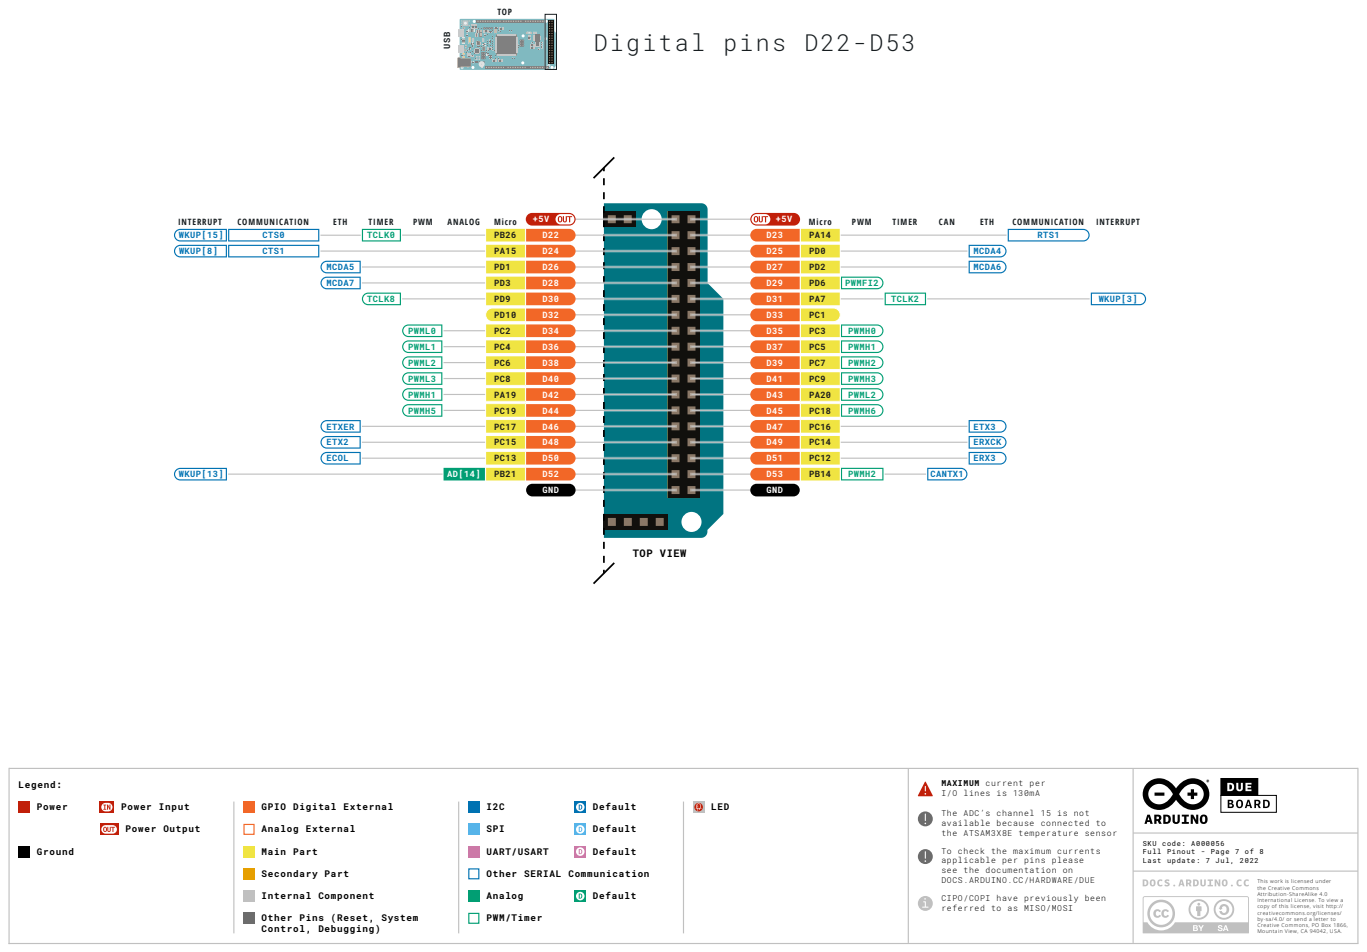
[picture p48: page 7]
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

SKU code: A000056
Full Pinout - Page 7 of 8
Last update: 7 Jul, 2022

# Digital pins D22-D53

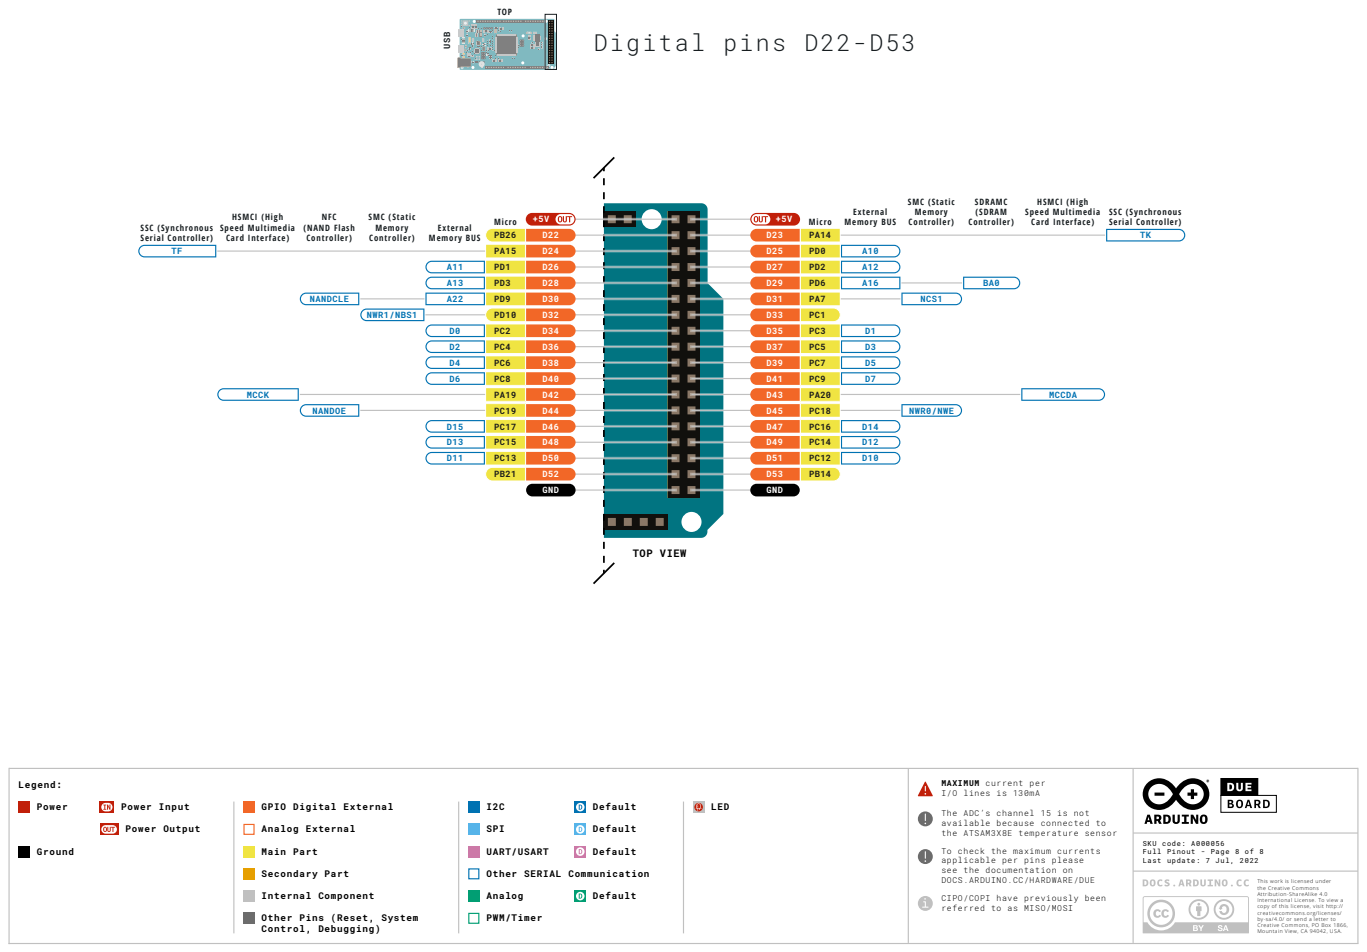
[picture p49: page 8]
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

SKU code: A000056
Full Pinout - Page 8 of 8
Last update: 7 Jul, 2022

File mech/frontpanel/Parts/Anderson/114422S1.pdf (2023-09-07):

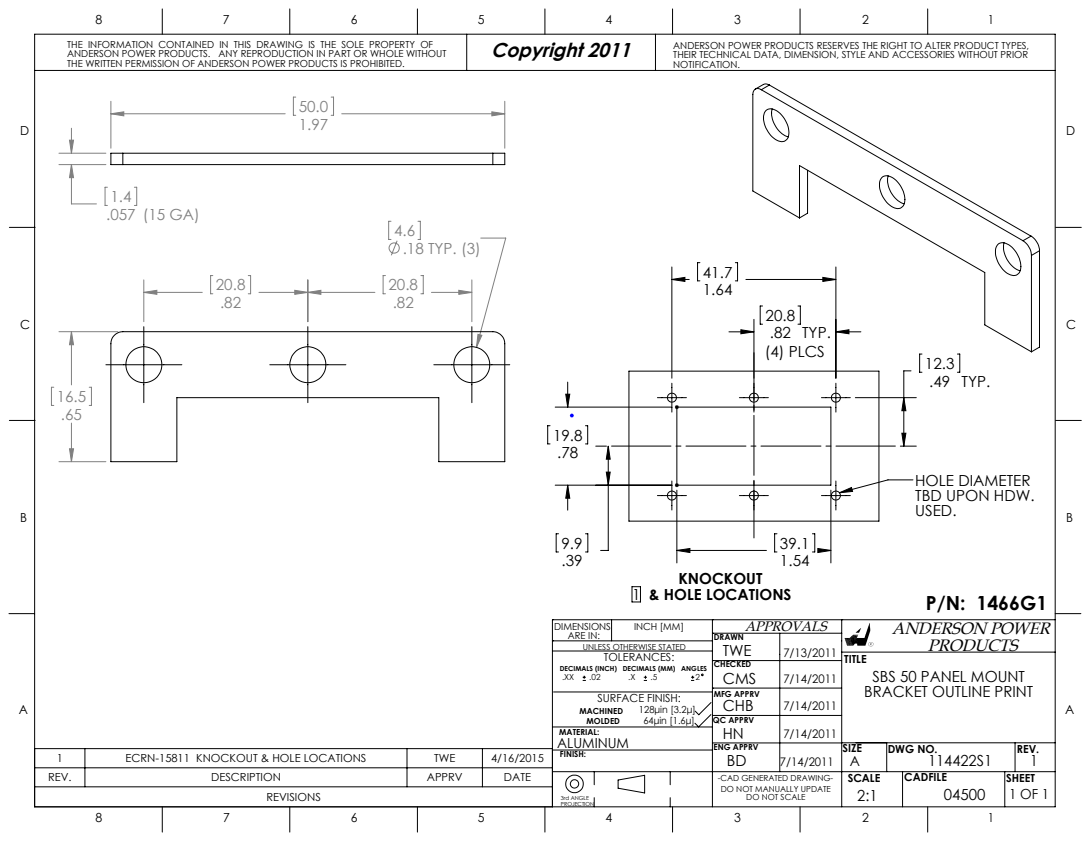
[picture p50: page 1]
.18 TYP. (3); .82 TYP. (4) PLCS; .49 TYP.; 1 & HOLE LOCATIONS; DWG NO.; Copyright 2011; APPROVALS DRAWN; MFG APPRV; QC APPRV; ENG APPRV; 7/13/2011 TOLERANCES:; 3rd ANGLE; INCH [MM]; 64μin [1.6μ]; 128μin [3.2μ]

THE INFORMATION CONTAINED IN THIS DRAWING IS THE SOLE PROPERTY OF
ANDERSON POWER PRODUCTS. ANY REPRODUCTION IN PART OR WHOLE WITHOUT
THE WRITTEN PERMISSION OF ANDERSON POWER PRODUCTS IS PROHIBITED.

ANDERSON POWER PRODUCTS RESERVES THE RIGHT TO ALTER PRODUCT TYPES,
THEIR TECHNICAL DATA, DIMENSION, STYLE AND ACCESSORIES WITHOUT PRIOR
NOTIFICATION.

HOLE DIAMETER
TBD UPON HDW.
USED.

ANDERSON POWER
PRODUCTS
SBS 50 PANEL MOUNT
BRACKET OUTLINE PRINT

DIMENSIONS
ARE IN:
UNLESS OTHERWISE STATED

DECIMALS (INCH) DECIMALS (MM) ANGLES
SURFACE FINISH:
MACHINED
MOLDED
MATERIAL:
ALUMINUM
FINISH:

1 | ECRN-15811 KNOCKOUT & HOLE LOCATIONS | TWE | 4/16/2015
REV. | DESCRIPTION | APPRV | DATE

-CAD GENERATED DRAWING-
DO NOT MANUALLY UPDATE
DO NOT SCALE

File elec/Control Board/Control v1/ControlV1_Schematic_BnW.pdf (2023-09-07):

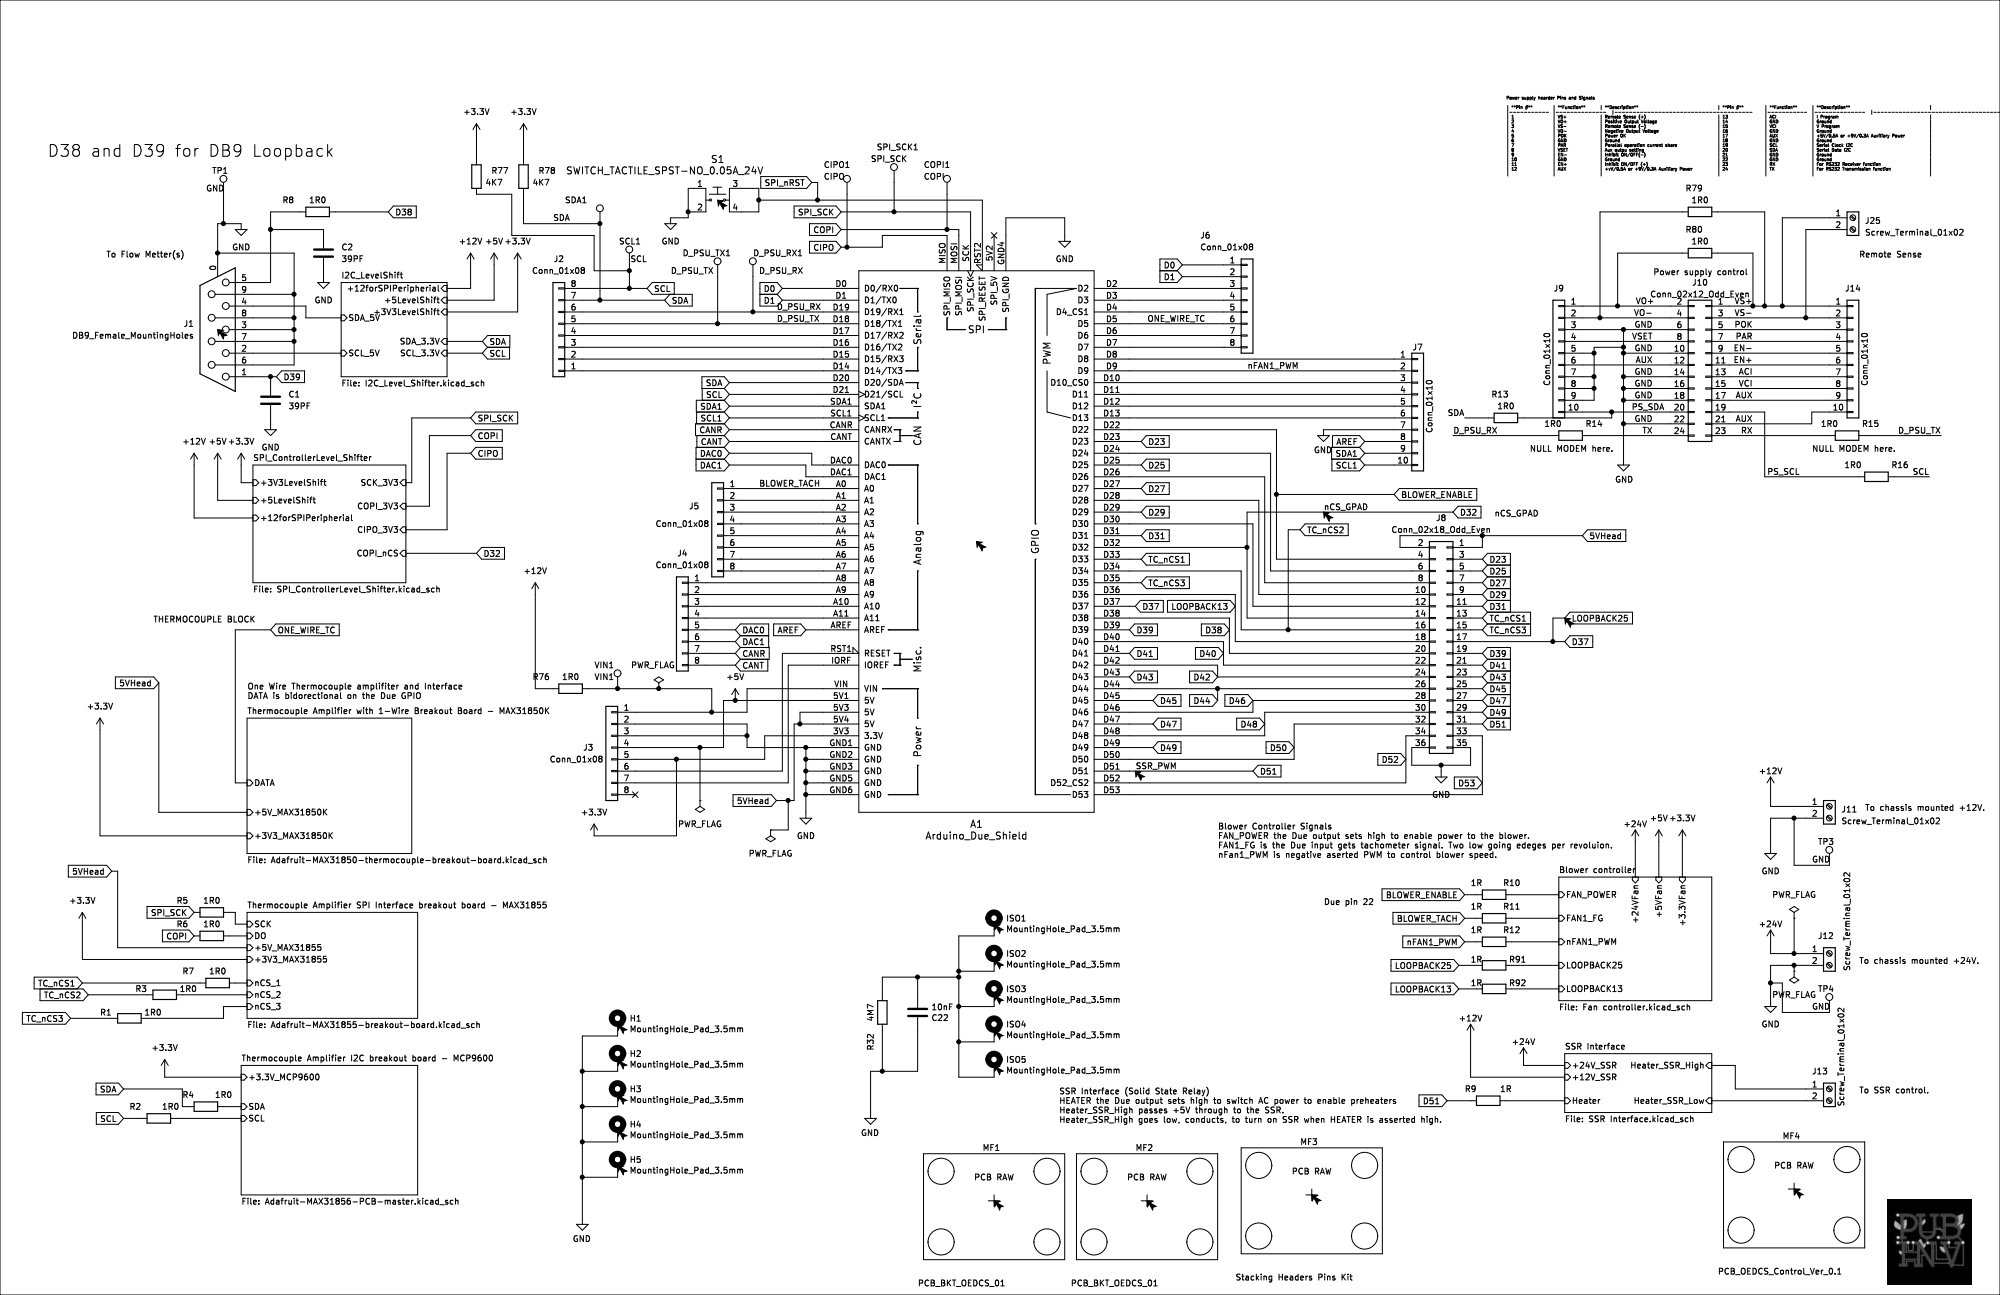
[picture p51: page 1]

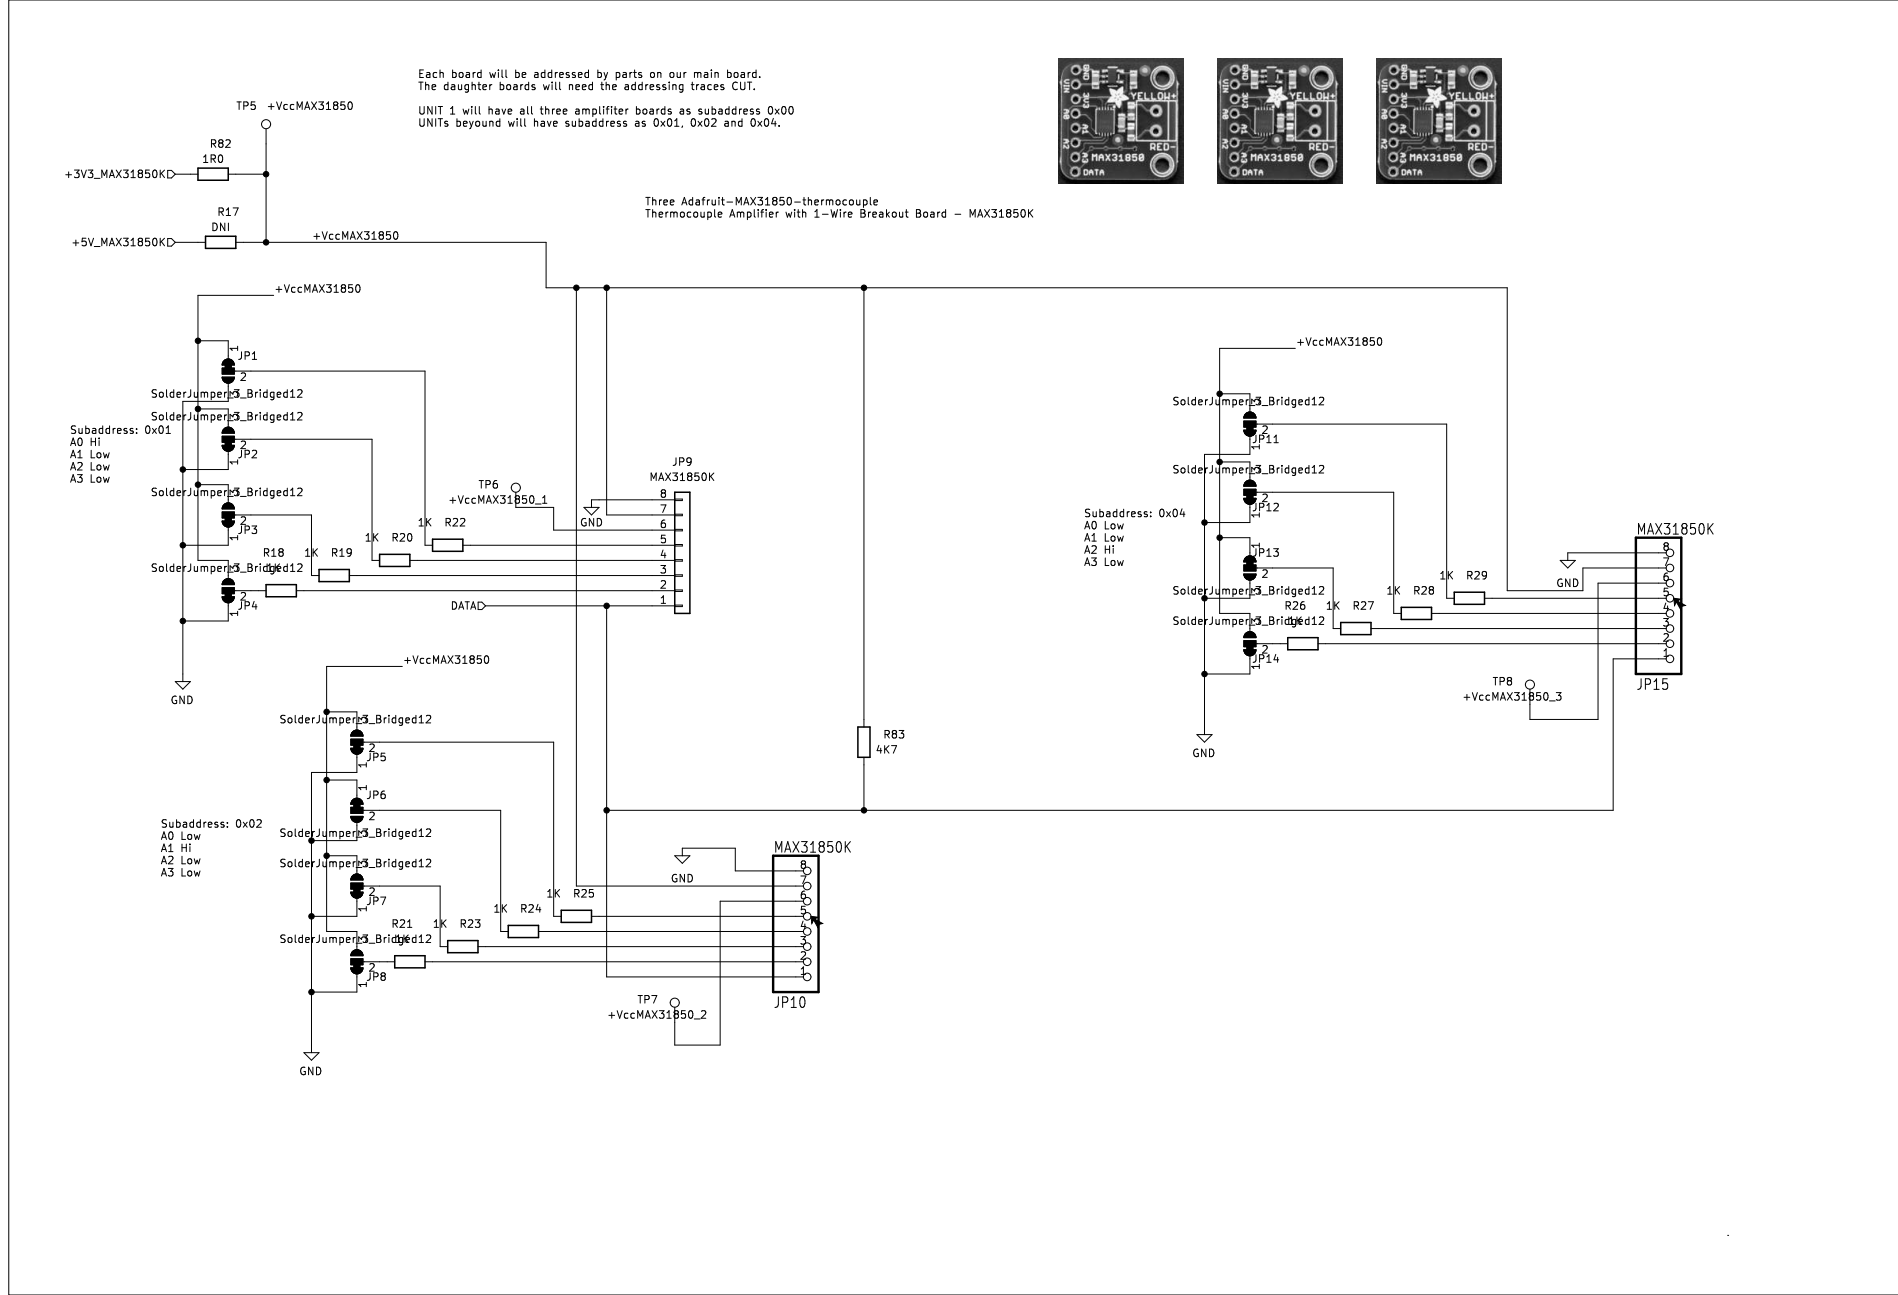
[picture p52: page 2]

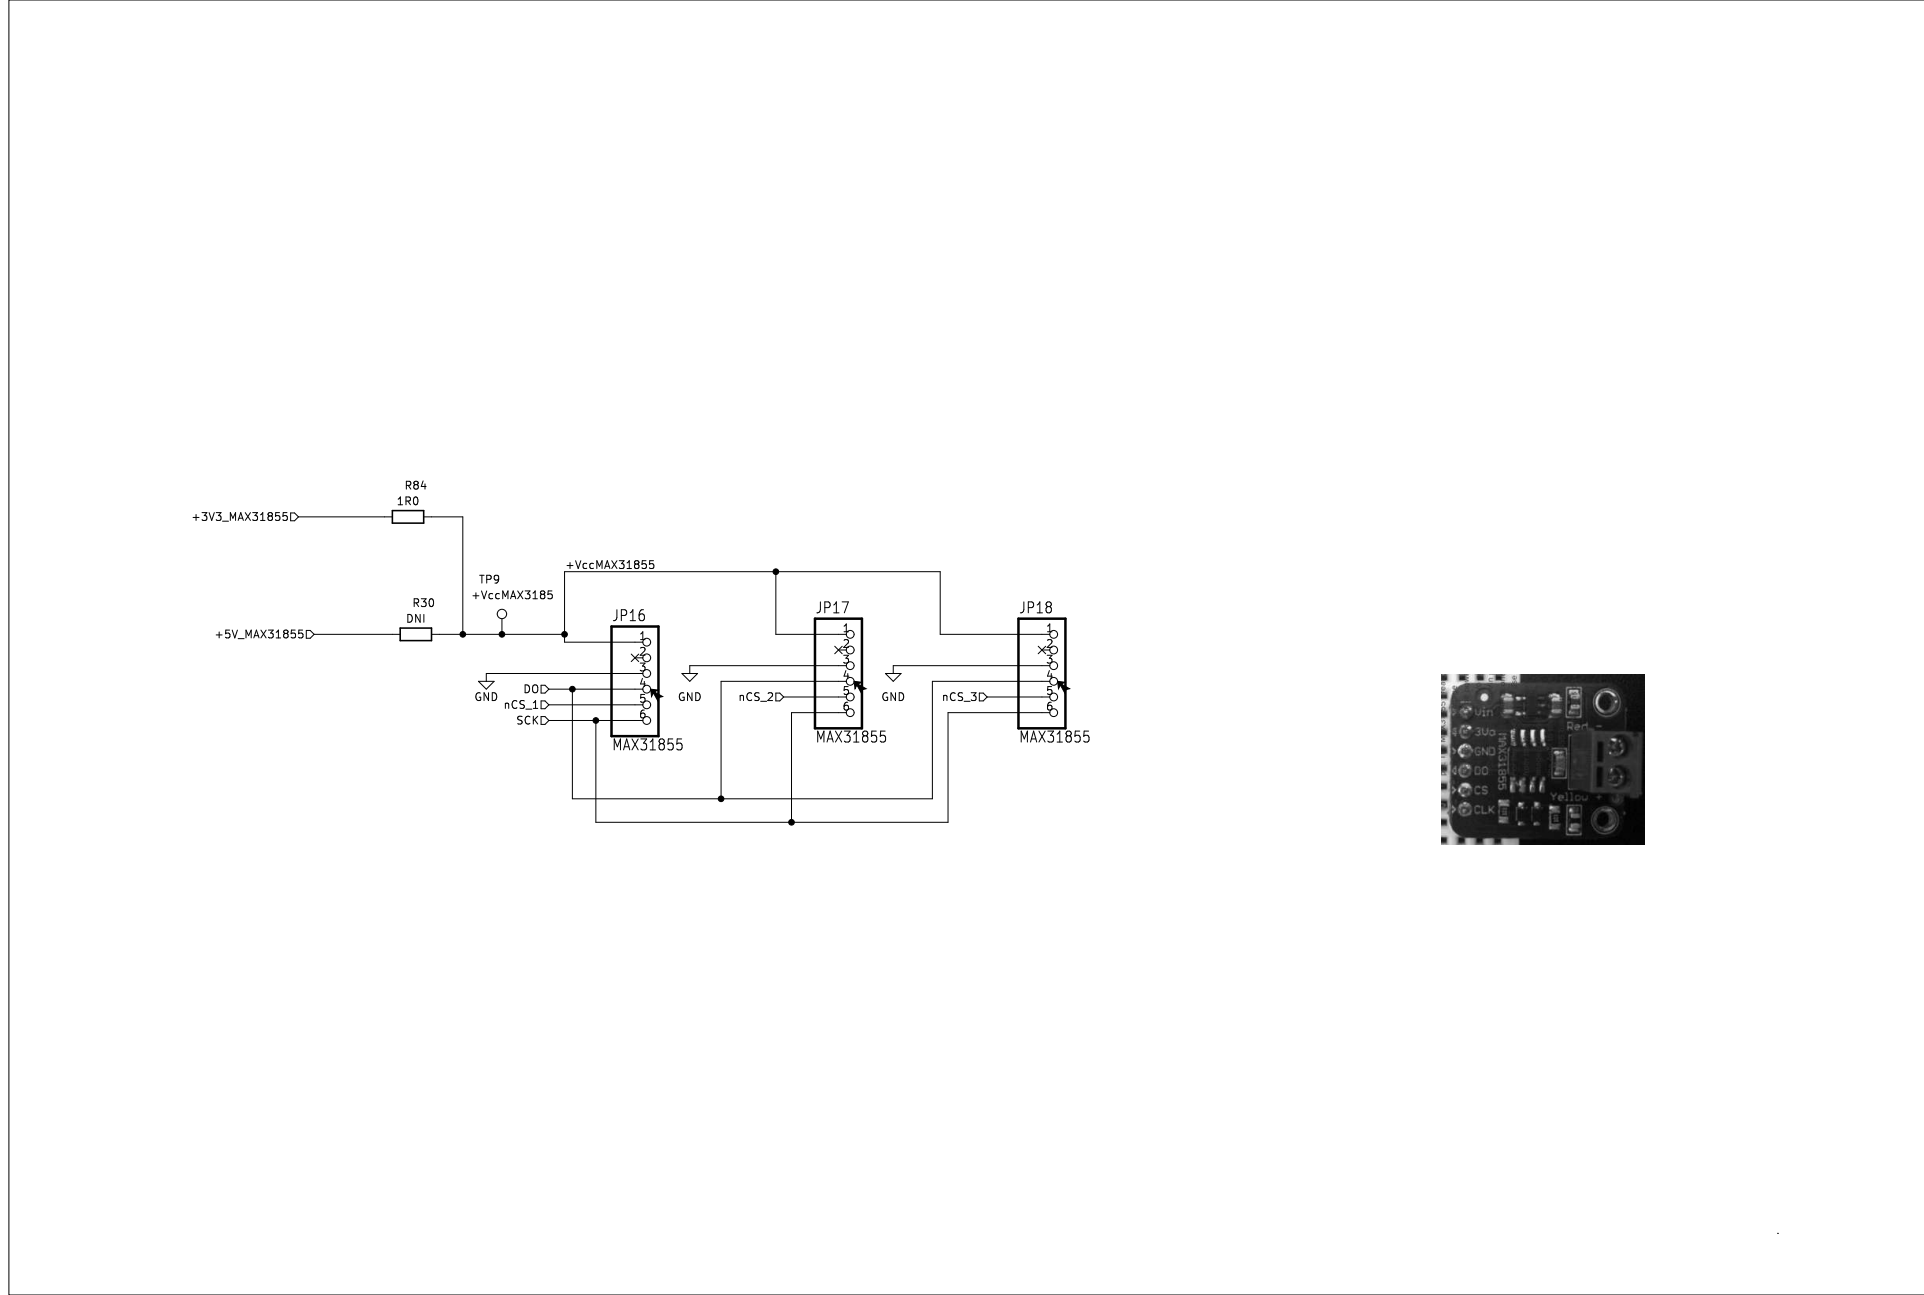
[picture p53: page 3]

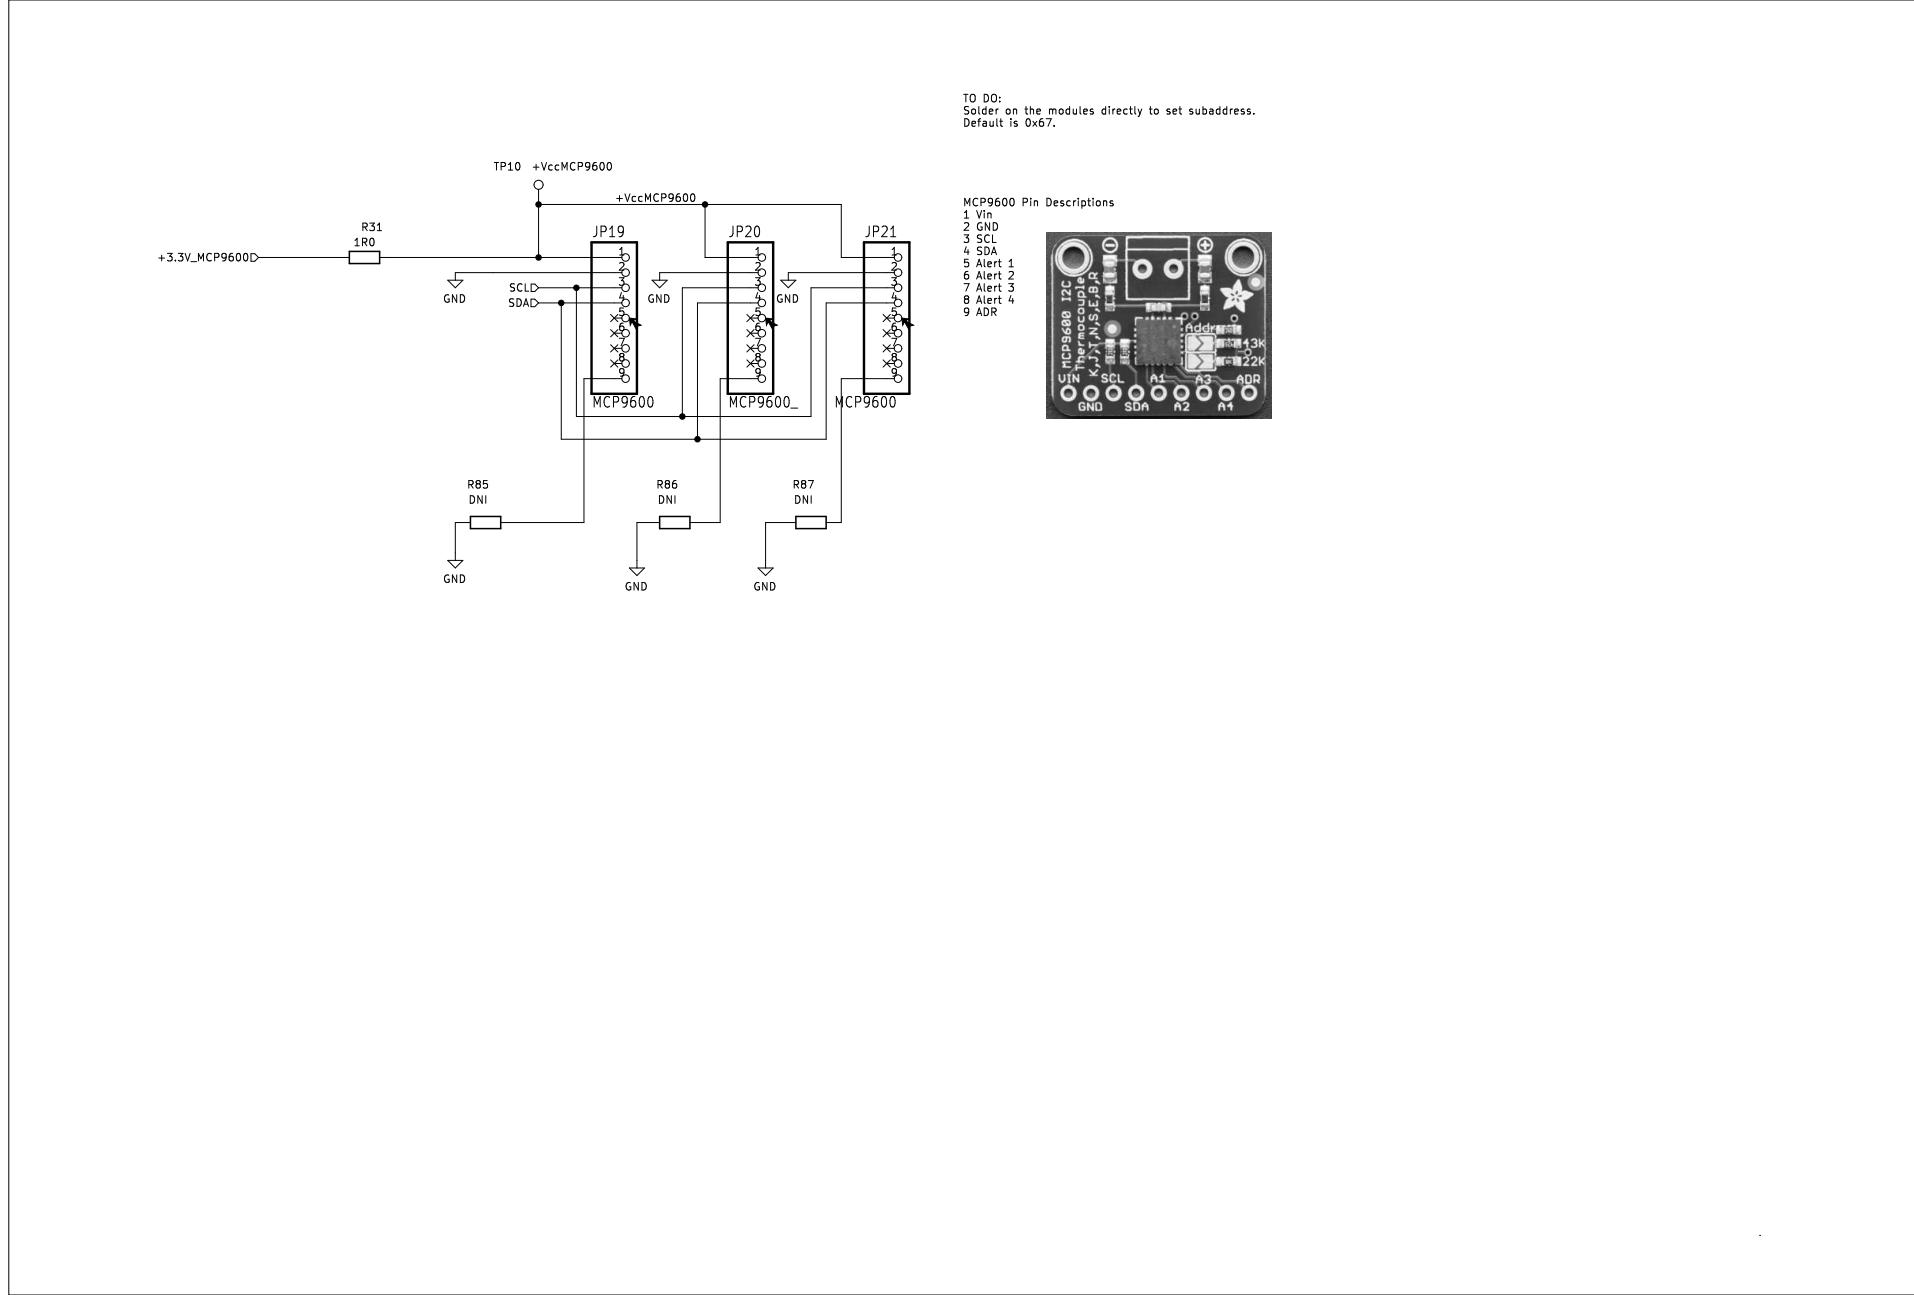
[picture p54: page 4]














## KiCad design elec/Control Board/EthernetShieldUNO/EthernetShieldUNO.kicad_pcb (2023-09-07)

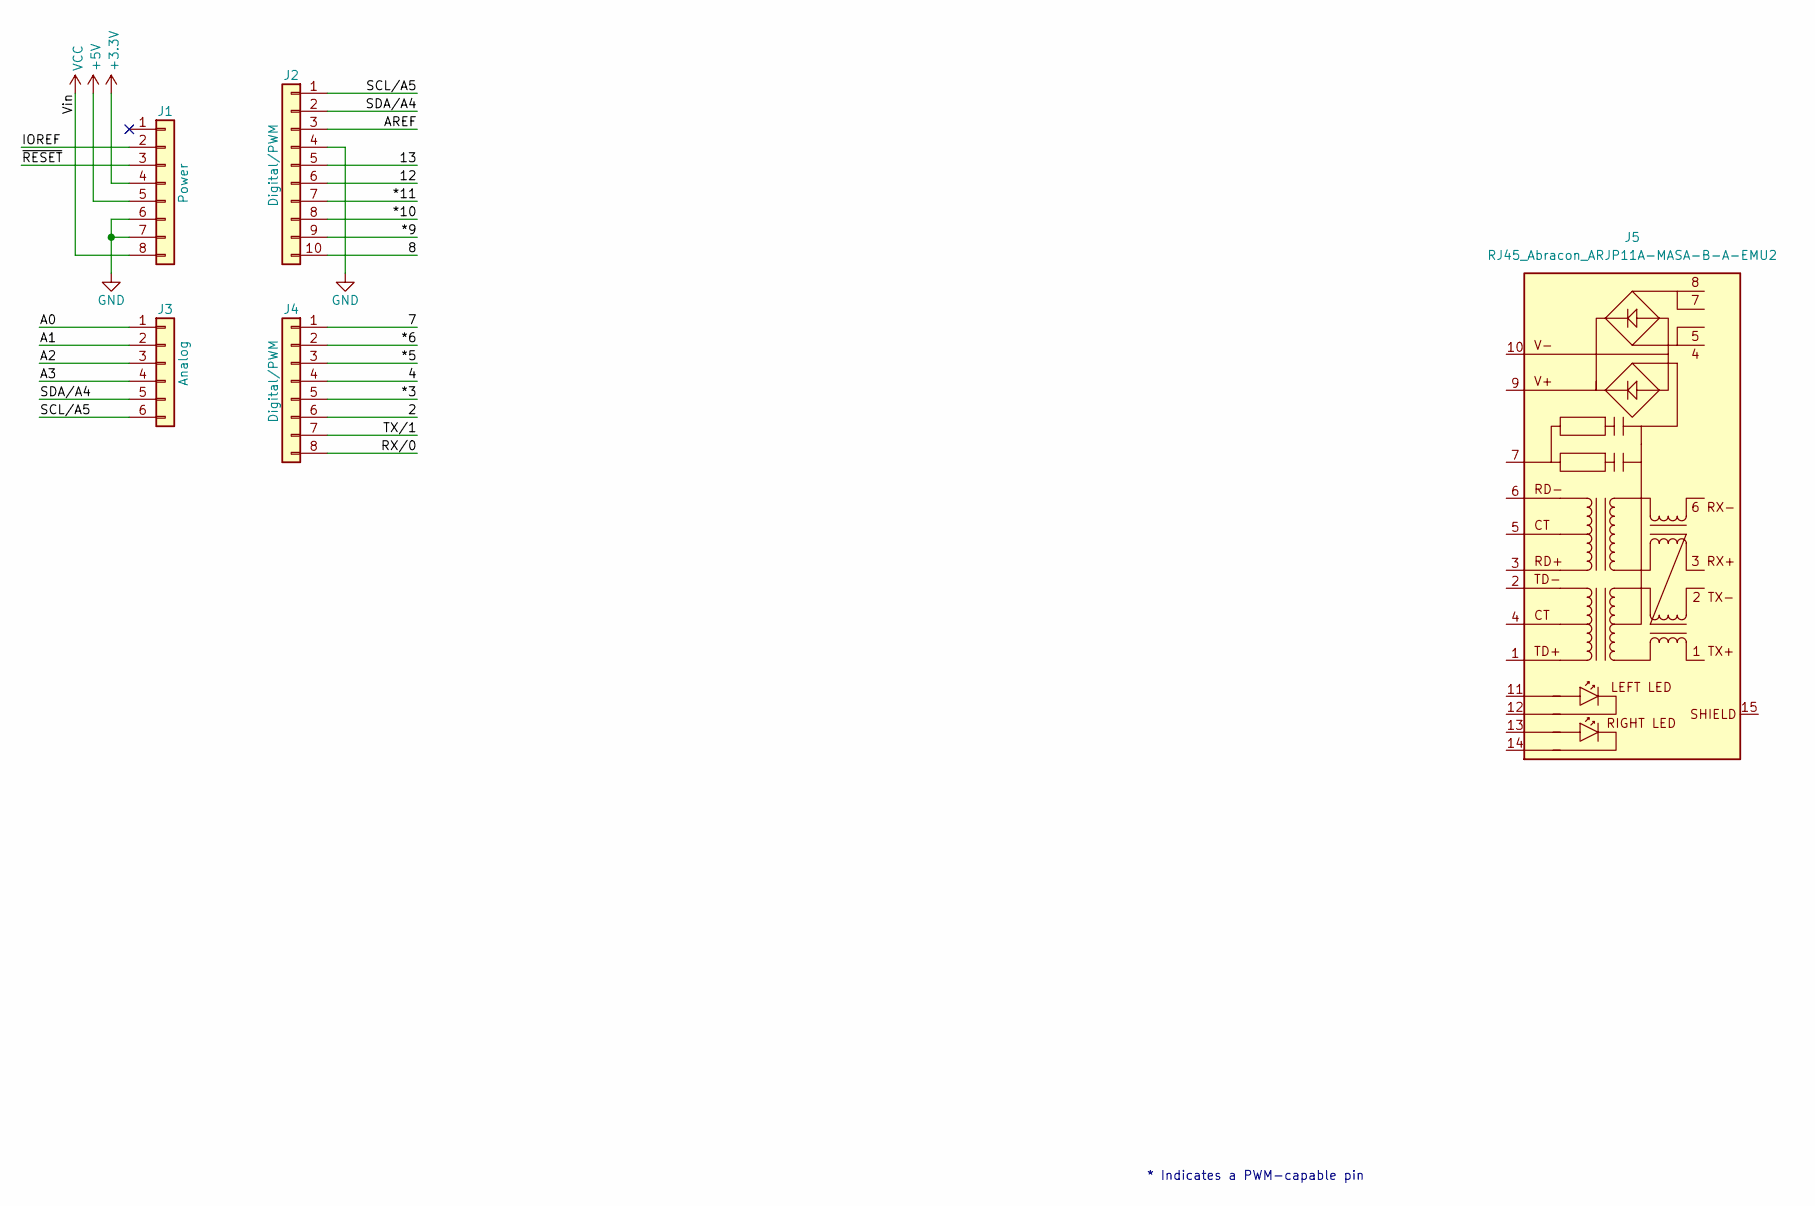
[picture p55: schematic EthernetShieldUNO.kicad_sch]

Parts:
J1: Power; PinSocket_1x08_P2.54mm_Vertical
J2: Digital/PWM; PinSocket_1x10_P2.54mm_Vertical
J3: Analog; PinSocket_1x06_P2.54mm_Vertical
J4: Digital/PWM; PinSocket_1x08_P2.54mm_Vertical
J5: RJ45_Abracon_ARJP11A-MASA-B-A-EMU2; RJ45_Abracon_ARJP11A-MA_Horizontal

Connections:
+3V3: J1.4
+5V: J1.5
/2: J4.6
/4: J4.4
/7: J4.1
/8: J2.10
/12: J2.6
/13: J2.5
/*3: J4.5
/*5: J4.3
/*6: J4.2
/*9: J2.9
/*10: J2.8
/*11: J2.7
/A0: J3.1
/A1: J3.2
/A2: J3.3
/A3: J3.4
/AREF: J2.3
/IOREF: J1.2
/RX/0: J4.8
/SCL/A5: J2.1, J3.6
/SDA/A4: J2.2, J3.5
/TX/1: J4.7
/~RESET: J1.3
GND: J1.6, J1.7, J2.4
VCC: J1.8

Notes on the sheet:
* Indicates a PWM-capable pin

Board: 2 copper layers, 9 parts (0 on the bottom side), 3 nets, no tracks yet.

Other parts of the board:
MH1, MH2, MH3, MH4: MountingHole_3.2mm

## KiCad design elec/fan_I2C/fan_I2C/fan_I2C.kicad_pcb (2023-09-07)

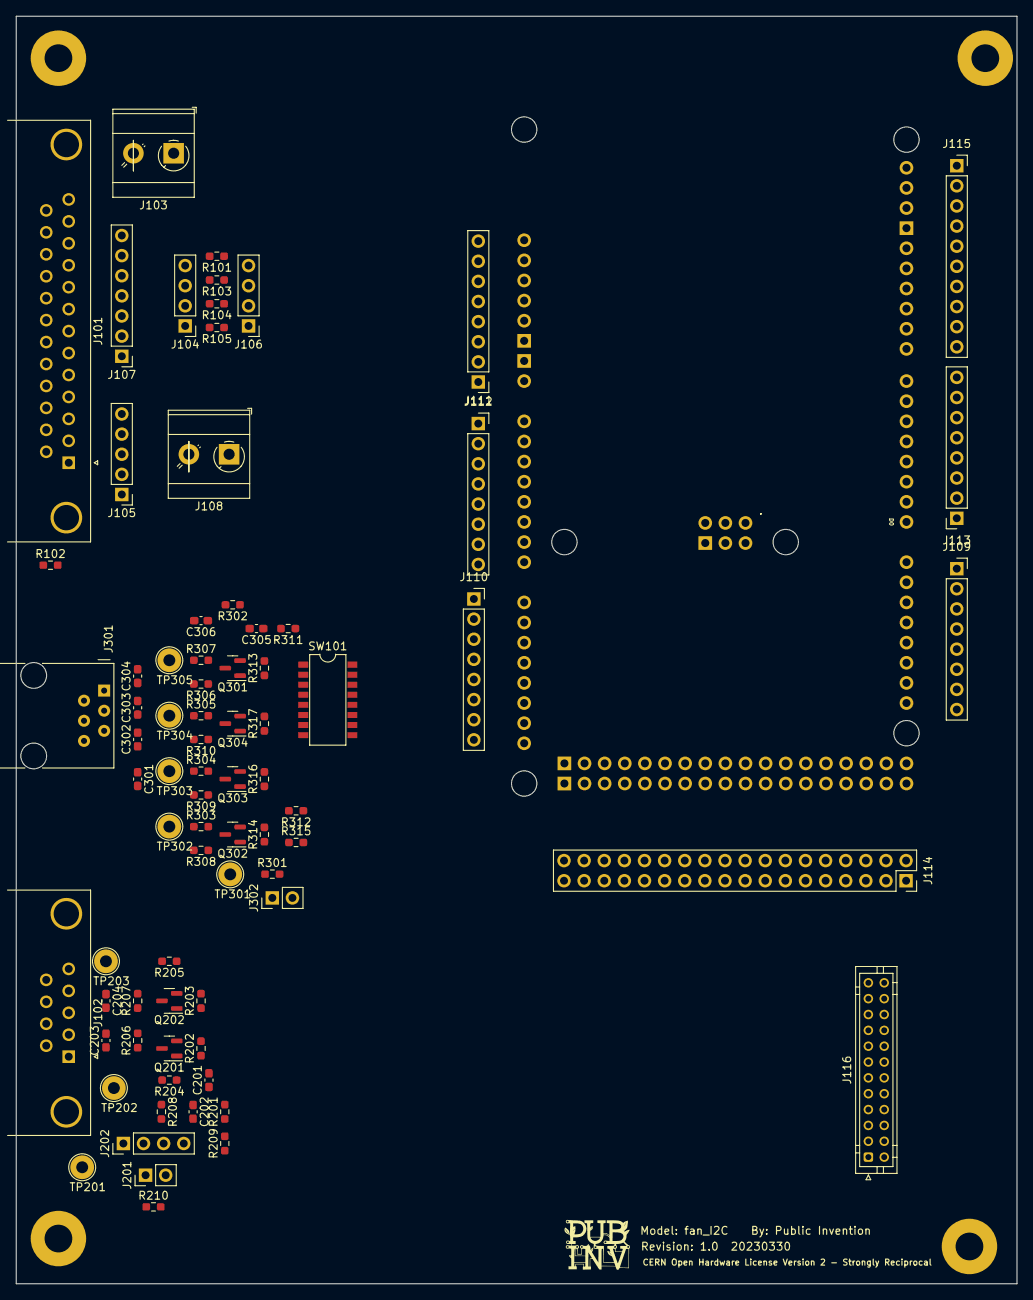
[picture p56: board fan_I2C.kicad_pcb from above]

Board: 2 copper layers, 126.3 x 160.0 mm, 78 parts (0 on the bottom side), 123 nets, no tracks yet.

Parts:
C201, C202, C305, C306: 1uF; C_0603_1608Metric_Pad1.08x0.95mm_HandSolder
C203, C204, C301, C302, C303, C304: 39PF; C_0603_1608Metric_Pad1.08x0.95mm_HandSolder
J101: DB25_Female_MountingHoles; DSUB-25_Female_Horizontal_P2.77x2.84mm_EdgePinOffset4.94mm_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
J102: DB9_Female_MountingHoles; DSUB-9_Female_Horizontal_P2.77x2.84mm_EdgePinOffset4.94mm_H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
J103, J108: Screw_Terminal_01x02; TerminalBlock_MetzConnect_Type073_RT02602HBLU_1x02_P5.08mm_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
J104, J106, J202: Conn_01x04; PinHeader_1x04_P2.54mm_Vertical
J105: Conn_01x05; PinHeader_1x05_P2.54mm_Vertical
J107: Conn_01x07; PinHeader_1x07_P2.54mm_Vertical
J109, J110, J112, J113: Conn_01x08; PinSocket_1x08_P2.54mm_Vertical
J111: Conn_01x08; PinHeader_1x08_P2.54mm_Vertical
J114: Conn_02x18_Odd_Even; PinSocket_2x18_P2.54mm_Vertical
J115: Conn_01x10_MountingPin; PinSocket_1x10_P2.54mm_Vertical
J116: Conn_02x12_Odd_Even; JST_PHD_B24B-PHDSS_2x12_P2.00mm_Vertical
J201, J302: 0.100_2Pin; PinHeader_1x02_P2.54mm_Vertical
J301: RJ12_6P6C_HORZ; RJ12_Amphenol_54601
Q201, Q202, Q301, Q302, Q303, Q304: BSS138; SOT-23
R101, R103, R104, R105: 540R; R_0603_1608Metric_Pad0.98x0.95mm_HandSolder
R102, R209, R210, R303, R304, R305, R307, R312, R315: DNI; R_0603_1608Metric_Pad0.98x0.95mm_HandSolder
R201, R208, R301, R302, R311: 1R; R_0603_1608Metric_Pad0.98x0.95mm_HandSolder
R202, R203, R204, R205, R308, R313, R316, R317: 10K; R_0603_1608Metric_Pad0.98x0.95mm_HandSolder
R206, R207: 39R; R_0603_1608Metric_Pad0.98x0.95mm_HandSolder
R306, R309, R310, R314: 1K; R_0603_1608Metric_Pad0.98x0.95mm_HandSolder
SW101: SW_DIP_x08; SMDIP-16_L11.39_W6.7mm
TP201: I2C_VCC; TestPoint_Loop_D2.54mm_Drill1.5mm_Beaded
TP202: SCL_5V; TestPoint_Loop_D2.54mm_Drill1.5mm_Beaded
TP203: SDA_5V; TestPoint_Loop_D2.54mm_Drill1.5mm_Beaded
TP301: ControllerVCC; TestPoint_Loop_D2.54mm_Drill1.5mm_Beaded
TP302: CPIO; TestPoint_Loop_D2.54mm_Drill1.5mm_Beaded
TP303: SCK; TestPoint_Loop_D2.54mm_Drill1.5mm_Beaded
TP304: COPI; TestPoint_Loop_D2.54mm_Drill1.5mm_Beaded
TP305: nCS; TestPoint_Loop_D2.54mm_Drill1.5mm_Beaded
XA101: Arduino_Due_Shield

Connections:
5V3: J114.1, XA101.5V3 (5V)
5V4: J114.2, XA101.5V4 (5V)
+3.3V: J106.2, J111.5, R101.1, R103.1, R104.1, R105.1, R311.1, XA101.3V3 (3.3V)
+5V: J111.4, R302.1, XA101.5V1 (5V)
+12V: J302.2, R301.2
/I2C_LevelShift/+3V3Local: C201.1, Q201.1 (G), Q202.1 (G), R201.2, R202.1, R203.1
/I2C_LevelShift/+5LevelShift: R208.2, R209.2
/I2C_LevelShift/+5VLocal: C202.1, R204.1, R205.1, R208.1
/I2C_LevelShift/+12forSPIPeripherial: J201.2, R210.2
/I2C_LevelShift/I2C_VCC: J201.1, J202.1, R209.1, R210.1, TP201.1
/I2C_LevelShift/SCL_5V: C203.1, J102.2, J202.2, R206.1, TP202.1
/I2C_LevelShift/SDA_5V: C204.1, J102.4, J202.4, R207.1, TP203.1
/SPI_ControllerLevel_Shifter/+3V3Local: C305.1, Q301.1 (G), Q302.1 (G), Q303.1 (G), Q304.1 (G), R311.2, R313.1, R314.1, R316.1, R317.1
/SPI_ControllerLevel_Shifter/+5VLocal: C306.1, R302.2, R306.1, R308.1, R309.1, R310.1
/SPI_ControllerLevel_Shifter/CIPO: C301.1, J301.6, Q302.3 (D), R303.1, R308.2, TP302.1
/SPI_ControllerLevel_Shifter/COPI: C303.1, J301.2, Q304.3 (D), R305.1, R310.2, TP304.1
/SPI_ControllerLevel_Shifter/COPI_nCS: Q301.2 (S), R307.2, R313.2, SW101.1, SW101.2, SW101.3, SW101.4, SW101.5, SW101.6, SW101.7, SW101.8
/SPI_ControllerLevel_Shifter/C_SCK: C302.1, J301.4, Q303.3 (D), R304.1, R309.2, TP303.1
/SPI_ControllerLevel_Shifter/ControllerVcc: J301.5, J302.1, R301.1, TP301.1
/SPI_ControllerLevel_Shifter/nCS: C304.1, J301.1, Q301.3 (D), R306.2, R307.1, TP305.1
AREF: J115.3, XA101.AREF
CANR: J110.7, XA101.CANR (CANRX)
CANT: J110.8, XA101.CANT (CANTX)
CIPO: Q302.2 (S), R303.2, R312.2, R314.2, XA101.MISO (SPI_MISO)
COPI: Q304.2 (S), R305.2, R317.2, XA101.MOSI (SPI_MOSI)
D0: J113.1, XA101.D0 (D0/RX0)
D1: J113.2, XA101.D1 (D1/TX0)
D23: J109.7, J114.4, XA101.D23
D25: J114.6, XA101.D25
D27: J114.8, XA101.D27
D29: J114.10, XA101.D29
D31: J114.12, XA101.D31
D33: J114.14, XA101.D33
D35: J114.16, XA101.D35
D37: J114.18, XA101.D37
D39: J114.20, XA101.D39
D41: J114.22, XA101.D41
D43: J114.24, XA101.D43
D45: J114.26, XA101.D45
D47: J114.28, XA101.D47
D49: J114.30, XA101.D49
D51: J114.32, XA101.D51
DAC0: J110.5, XA101.DAC0
DAC1: J110.6, XA101.DAC1
GND: C201.2, C202.2, C203.2, C204.2, C301.2, C302.2, C303.2, C304.2, C305.2, C306.2, J101.0 (PAD), J102.0 (PAD), J102.3, J102.6, J102.7, J102.8, J102.9, J106.1, J108.1, J111.2, J111.3, J114.35, J114.36, J115.4, J202.3, J301.3, R102.2, R315.1, XA101.GND1 (GND), XA101.GND2 (GND), XA101.GND3 (GND), XA101.GND5 (GND), XA101.GND6 (GND)
unnamed: J101.1, J105.1
unnamed: J101.2, J105.2
unnamed: J101.3, J105.3
unnamed: J101.4, J105.4
unnamed: J101.5, J104.1, R105.2
unnamed: J101.6, J104.2, R104.2
unnamed: J101.7, J104.3, R103.2
unnamed: J101.8, J104.4, R101.2
unnamed: J101.9, J101.10, J101.11, J101.12, J103.2
unnamed: J101.13, J106.4
unnamed: J101.14, J101.15, J101.16, J101.17, J103.1, R102.1
unnamed: J101.18, J107.1
unnamed: J101.19, J107.2
unnamed: J101.20, J107.3
unnamed: J101.21, J107.4
unnamed: J101.22, J107.5
unnamed: J101.23, J107.6
unnamed: J101.24, J107.7
unnamed: J101.25, J106.3
unnamed: J105.5, J108.2
unnamed: J109.1, XA101.D14 (D14/TX3)
unnamed: J109.2, XA101.D15 (D15/RX3)
unnamed: J109.3, XA101.D16 (D16/TX2)
unnamed: J109.4, XA101.D17 (D17/RX2)
unnamed: J109.5, XA101.D18 (D18/TX1)
unnamed: J109.6, XA101.D19 (D19/RX1)
unnamed: J110.1, XA101.A8
unnamed: J110.2, XA101.A9
unnamed: J110.3, XA101.A10
unnamed: J110.4, XA101.A11
unnamed: J111.1, XA101.VIN
unnamed: J111.6, XA101.RST1 (RESET)
unnamed: J111.7, XA101.IORF (IOREF)
unnamed: J112.1, XA101.A0
unnamed: J112.2, XA101.A1
unnamed: J112.3, XA101.A2
unnamed: J112.4, XA101.A3
unnamed: J112.5, XA101.A4
unnamed: J112.6, XA101.A5
unnamed: J112.7, XA101.A6
unnamed: J112.8, XA101.A7
unnamed: J113.3, XA101.D2
unnamed: J113.4, XA101.D3
unnamed: J113.5, XA101.D4 (D4_CS1)
unnamed: J113.6, XA101.D5
unnamed: J113.7, XA101.D6
unnamed: J113.8, XA101.D7
unnamed: J114.3, XA101.D22
unnamed: J114.5, XA101.D24
unnamed: J114.7, XA101.D26
unnamed: J114.9, XA101.D28
unnamed: J114.11, XA101.D30
unnamed: J114.13, XA101.D32
unnamed: J114.15, XA101.D34
unnamed: J114.17, XA101.D36
unnamed: J114.19, XA101.D38
unnamed: J114.21, XA101.D40
unnamed: J114.23, XA101.D42
unnamed: J114.25, XA101.D44
unnamed: J114.27, XA101.D46
unnamed: J114.29, XA101.D48
unnamed: J114.31, XA101.D50
unnamed: J114.33, XA101.D52 (D52_CS2)
unnamed: J114.34, XA101.D53
unnamed: J115.5, XA101.D13
unnamed: J115.6, XA101.D12
unnamed: J115.7, XA101.D11
unnamed: J115.8, XA101.D10 (D10_CS0)
unnamed: J115.9, XA101.D9
unnamed: J115.10, XA101.D8
unnamed: Q201.3 (D), R204.2, R206.2
unnamed: Q202.3 (D), R205.2, R207.2
unnamed: R312.1, R315.2
SCL: Q201.2 (S), R202.2, XA101.D21 (D21/SCL)
SCL1: J115.1, XA101.SCL1
SDA: Q202.2 (S), R203.2, XA101.D20 (D20/SDA)
SDA1: J115.2, XA101.SDA1
SPI_SCK: Q303.2 (S), R304.2, R316.2, XA101.SCK (SPI_SCK)

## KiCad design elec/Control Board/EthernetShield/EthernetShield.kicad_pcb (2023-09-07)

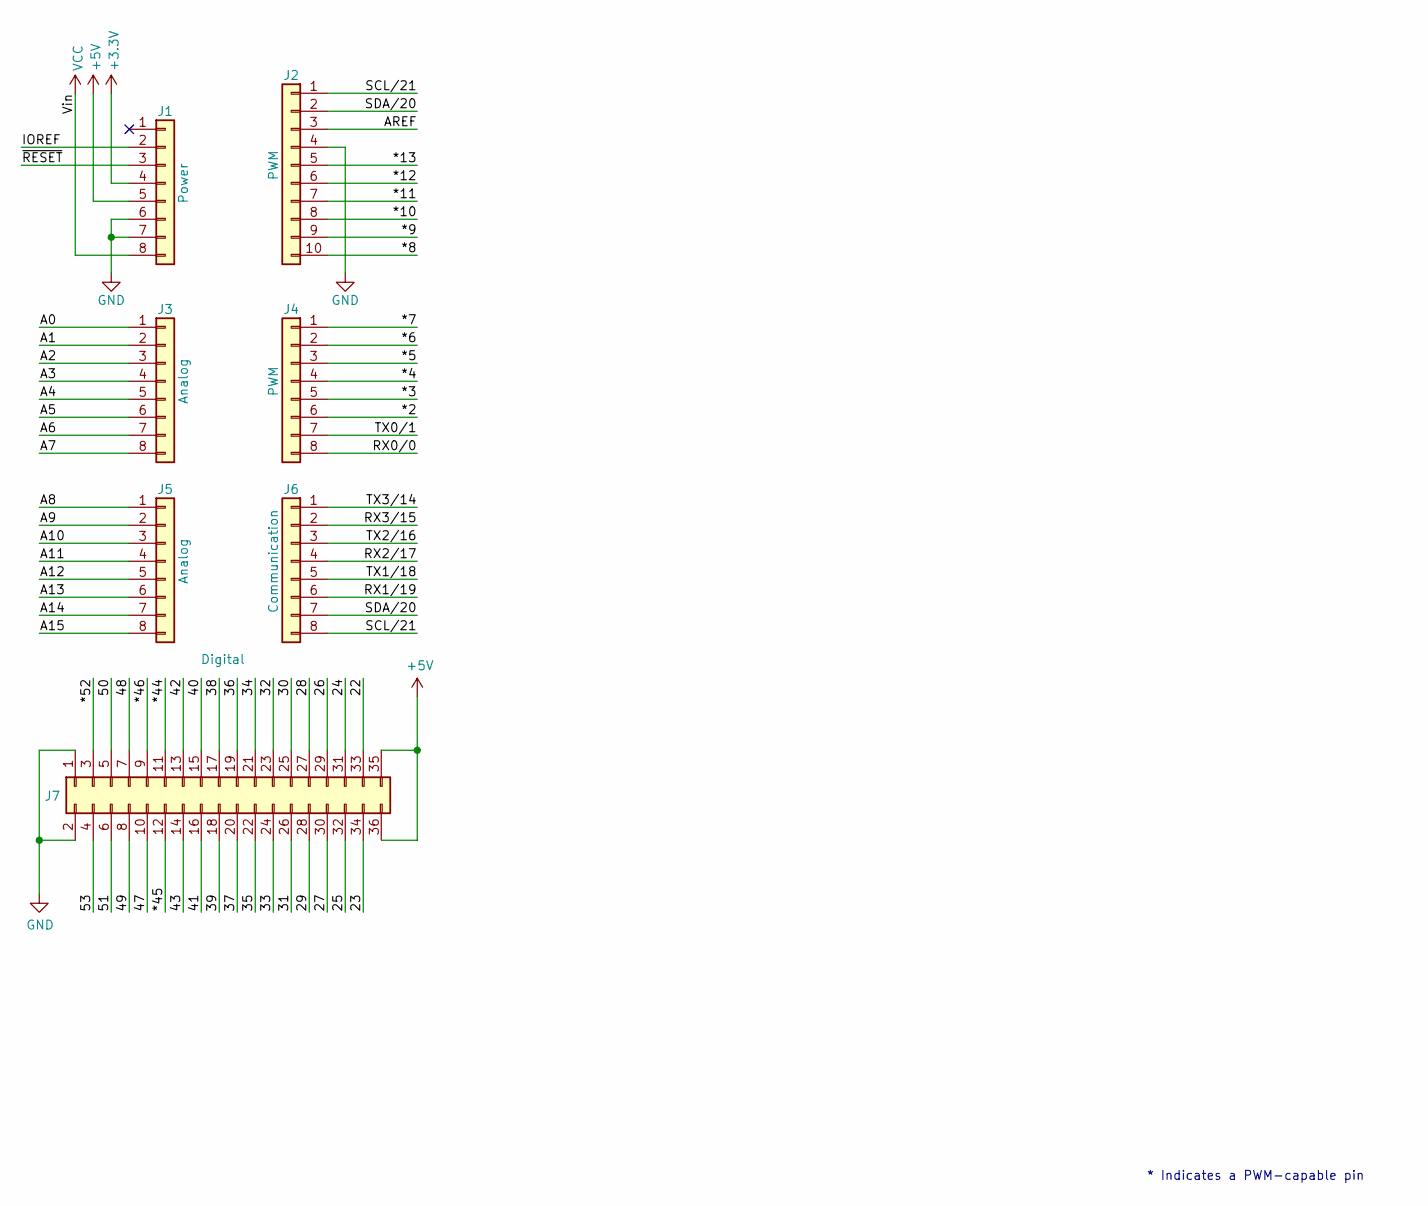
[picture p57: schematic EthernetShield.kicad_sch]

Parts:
J1: Power; PinSocket_1x08_P2.54mm_Vertical
J2: PWM; PinSocket_1x10_P2.54mm_Vertical
J3, J5: Analog; PinSocket_1x08_P2.54mm_Vertical
J4: PWM; PinSocket_1x08_P2.54mm_Vertical
J6: Communication; PinSocket_1x08_P2.54mm_Vertical
J7: Digital; PinSocket_2x18_P2.54mm_Vertical

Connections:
+3V3: J1.4
+5V: J1.5, J7.35, J7.36
/22: J7.33
/23: J7.34
/24: J7.31
/25: J7.32
/26: J7.29
/27: J7.30
/28: J7.27
/29: J7.28
/30: J7.25
/31: J7.26
/32: J7.23
/33: J7.24
/34: J7.21
/35: J7.22
/36: J7.19
/37: J7.20
/38: J7.17
/39: J7.18
/40: J7.15
/41: J7.16
/42: J7.13
/43: J7.14
/47: J7.10
/48: J7.7
/49: J7.8
/50: J7.5
/51: J7.6
/53: J7.4
/*2: J4.6
/*3: J4.5
/*4: J4.4
/*5: J4.3
/*6: J4.2
/*7: J4.1
/*8: J2.10
/*9: J2.9
/*10: J2.8
/*11: J2.7
/*12: J2.6
/*13: J2.5
/*44: J7.11
/*45: J7.12
/*46: J7.9
/*52: J7.3
/A0: J3.1
/A1: J3.2
/A2: J3.3
/A3: J3.4
/A4: J3.5
/A5: J3.6
/A6: J3.7
/A7: J3.8
/A8: J5.1
/A9: J5.2
/A10: J5.3
/A11: J5.4
/A12: J5.5
/A13: J5.6
/A14: J5.7
/A15: J5.8
/AREF: J2.3
/IOREF: J1.2
/RX0/0: J4.8
/RX1/19: J6.6
/RX2/17: J6.4
/RX3/15: J6.2
/SCL/21: J2.1, J6.8
/SDA/20: J2.2, J6.7
/TX0/1: J4.7
/TX1/18: J6.5
/TX2/16: J6.3
/TX3/14: J6.1
/~RESET: J1.3
GND: J1.6, J1.7, J2.4, J7.1, J7.2
VCC: J1.8

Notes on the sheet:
* Indicates a PWM-capable pin

Board: 2 copper layers, 13 parts (0 on the bottom side), 4 nets, no tracks yet.

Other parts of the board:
MH1, MH2, MH3, MH4, MH5, MH6: MountingHole_3.2mm

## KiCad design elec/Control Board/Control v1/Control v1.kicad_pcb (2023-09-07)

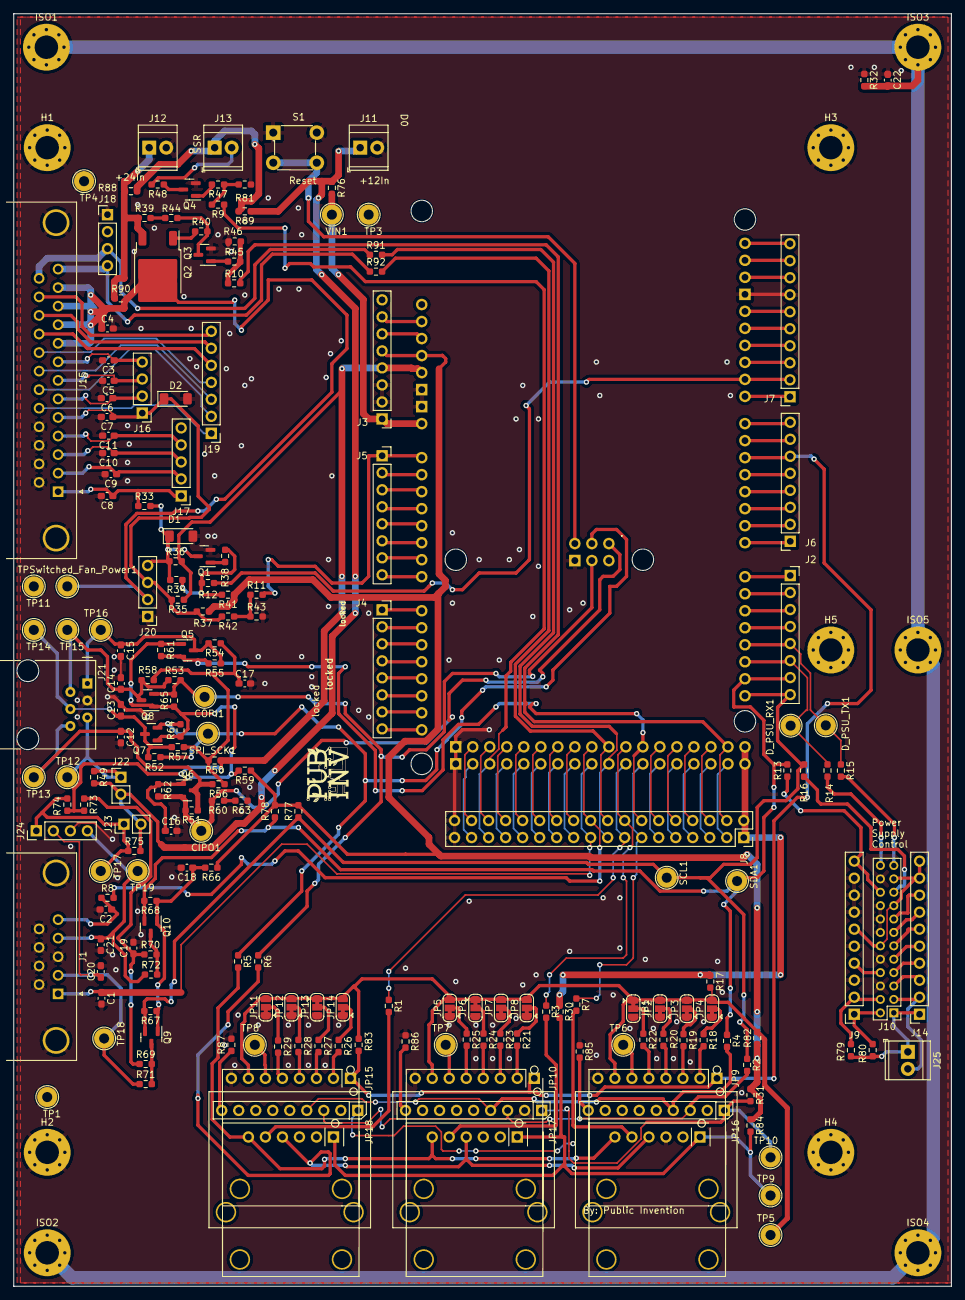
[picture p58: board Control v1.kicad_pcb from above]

Board: 2 copper layers, 140.0 x 190.0 mm, 211 parts (0 on the bottom side), 191 nets.

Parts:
A1: Arduino_Due_Shield
C1, C2, C12, C13, C14, C15, C20, C21: 39PF; C_0603_1608Metric_Pad1.08x0.95mm_HandSolder
C3, C4, C5, C6, C7, C8, C9, C10, C11: 39pF; C_0603_1608Metric_Pad1.08x0.95mm_HandSolder
C16, C17, C18, C19: 1uF; C_0603_1608Metric_Pad1.08x0.95mm_HandSolder
C22: 10nF; C_0603_1608Metric_Pad1.08x0.95mm_HandSolder
CIPO1: CIPO; TestPoint_Loop_D2.54mm_Drill1.5mm_Beaded
COPI1: COPI; TestPoint_Loop_D2.54mm_Drill1.5mm_Beaded
D1, D2: DNI; D_MiniMELF
D_PSU_RX1: D_PSU_RX; TestPoint_Loop_D2.54mm_Drill1.5mm_Beaded
D_PSU_TX1: D_PSU_TX; TestPoint_Loop_D2.54mm_Drill1.5mm_Beaded
H1, H2, H3, H4, H5: MountingHole_Pad_3.5mm; MountingHole_3.5mm_Pad_Via
ISO1, ISO2, ISO3, ISO4, ISO5: MountingHole_Pad_3.5mm; MountingHole_3.5mm_Pad_Via
J1: DB9_Female_MountingHoles; DSUB-9_Female_Horizontal_P2.77x2.84mm_EdgePinOffset4.94mm_H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
J2, J4, J5, J6: Conn_01x08; PinSocket_1x08_P2.54mm_Vertical
J3: Conn_01x08; PinHeader_1x08_P2.54mm_Vertical
J7, J9, J14: Conn_01x10; PinSocket_1x10_P2.54mm_Vertical
J8: Conn_02x18_Odd_Even; PinSocket_2x18_P2.54mm_Vertical
J10: Conn_02x12_Odd_Even; PinHeader_2x12_P2.00mm_Vertical
J11, J12, J13, J25: Screw_Terminal_01x02; TerminalBlock_TE_282834-2_1x02_P2.54mm_Horizontal
J15: DB25_Female_MountingHoles; DSUB-25_Female_Horizontal_P2.77x2.84mm_EdgePinOffset4.94mm_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
J16, J18, J20, J24: Conn_01x04; PinHeader_1x04_P2.54mm_Vertical
J17: Conn_01x05; PinHeader_1x05_P2.54mm_Vertical
J19: Conn_01x07; PinHeader_1x07_P2.54mm_Vertical
J21: RJ12_6P6C_HORZ; RJ12_Amphenol_54601
J22, J23: 0.100_2Pin; PinHeader_1x02_P2.54mm_Vertical
JP1, JP2, JP3, JP4, JP5, JP6, JP7, JP8, JP11, JP12, JP13, JP14: SolderJumper_3_Bridged12; SolderJumper-3_P1.3mm_Bridged12_RoundedPad1.0x1.5mm
JP9, JP10, JP15: MAX31850K; Adafruit_MAX31850K_Module
JP16, JP17, JP18: MAX31855; Adafruit_MAX31855_Module
JP19, JP21: MCP9600; Adafruit_MCP9600_Module
JP20: MCP9600_; Adafruit_MCP9600_Module
Q1, Q3, Q4, Q5, Q6, Q7, Q8, Q9, Q10: BSS138; SOT-23
Q2: NCE01P30K; TO-252-2
R1, R2, R3, R4, R5, R6, R7, R8, R13, R14, R15, R16, R31, R33, R48, R76, R79, R80, R82, R84, R88: 1R0; R_0603_1608Metric_Pad0.98x0.95mm_HandSolder
R9, R10, R11, R12, R49, R50, R59, R66, R73, R91, R92: 1R; R_0603_1608Metric_Pad0.98x0.95mm_HandSolder
R17, R30, R34, R35, R43, R51, R52, R53, R55, R60, R63, R74, R75, R85, R86, R87, R89, R90: DNI; R_0603_1608Metric_Pad0.98x0.95mm_HandSolder
R18, R19, R20, R21, R22, R23, R24, R25, R26, R27, R28, R29, R36, R37, R38, R42, R45, R47, R54, R57, R58, R62: 1K; R_0603_1608Metric_Pad0.98x0.95mm_HandSolder
R32: 4M7; R_0603_1608Metric_Pad0.98x0.95mm_HandSolder
R39, R40, R41, R44, R46, R56, R61, R64, R65, R67, R68, R69, R70, R81: 10K; R_0603_1608Metric_Pad0.98x0.95mm_HandSolder
R71, R72: 39R; R_0603_1608Metric_Pad0.98x0.95mm_HandSolder
R77, R78, R83: 4K7; R_0603_1608Metric_Pad0.98x0.95mm_HandSolder
S1: SWITCH_TACTILE_SPST-NO_0.05A_24V; Switch_Tactile_THT_6x6mm
SCL1: SCL; TestPoint_Loop_D2.54mm_Drill1.5mm_Beaded
SDA1: SDA; TestPoint_Loop_D2.54mm_Drill1.5mm_Beaded
SPI_SCK1: SPI_SCK; TestPoint_Loop_D2.54mm_Drill1.5mm_Beaded
TP1, TP3, TP4, TP11: GND; TestPoint_Loop_D2.54mm_Drill1.5mm_Beaded
TP5: +VccMAX31850; TestPoint_Loop_D2.54mm_Drill1.5mm_Beaded
TP6: +VccMAX31850_1; TestPoint_Loop_D2.54mm_Drill1.5mm_Beaded
TP7: +VccMAX31850_2; TestPoint_Loop_D2.54mm_Drill1.5mm_Beaded
TP8: +VccMAX31850_3; TestPoint_Loop_D2.54mm_Drill1.5mm_Beaded
TP9: +VccMAX3185; TestPoint_Loop_D2.54mm_Drill1.5mm_Beaded
TP10: +VccMCP9600; TestPoint_Loop_D2.54mm_Drill1.5mm_Beaded
TP12: ControllerVCC; TestPoint_Loop_D2.54mm_Drill1.5mm_Beaded
TP13: CPIO; TestPoint_Loop_D2.54mm_Drill1.5mm_Beaded
TP14: SCK; TestPoint_Loop_D2.54mm_Drill1.5mm_Beaded
TP15: COPI; TestPoint_Loop_D2.54mm_Drill1.5mm_Beaded
TP16: nCS; TestPoint_Loop_D2.54mm_Drill1.5mm_Beaded
TP17: I2C_VCC; TestPoint_Loop_D2.54mm_Drill1.5mm_Beaded
TP18: SCL_5V; TestPoint_Loop_D2.54mm_Drill1.5mm_Beaded
TP19: SDA_5V; TestPoint_Loop_D2.54mm_Drill1.5mm_Beaded
TPSwitched_Fan_Power1: Switched_Fan_Power; TestPoint_Loop_D2.54mm_Drill1.5mm_Beaded
VIN1: VIN1; TestPoint_Loop_D2.54mm_Drill1.5mm_Beaded

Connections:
5VHead: A1.5V3 (5V), A1.5V4 (5V), J8.1, J8.2, R17.1, R30.1
+3.3V: A1.3V3 (3.3V), J3.5, R31.1, R37.2, R41.1, R59.1, R66.1, R77.2, R78.2, R82.1, R84.1
+5V: A1.5V1 (5V), J3.4, R35.1, R36.2, R50.1, R73.2, R74.2
+12V: J11.1, J22.2, J23.2, R49.2, R75.2, R76.1, R89.1
+24V: J12.1, Q2.3 (S), R39.1, R88.1, R90.1
/ACI: J10.13, J14.7
/AUX: J9.6, J10.12, J10.17, J10.21, J14.9, J14.10
/Blower controller/FAN1_FG: R11.1, R42.1, R43.1
/Blower controller/FAN_POWER: R10.1, R45.2, R46.1
/Blower controller/LOOPBACK13: J15.13, J18.4, R92.1
/Blower controller/LOOPBACK25: J15.25, J18.3, R91.1
/Blower controller/PWMFan1: C8.1, J15.1, J17.1, R33.1
/Blower controller/PWMFan2: C9.1, J15.2, J17.2
/Blower controller/PWMFan3: C10.1, J15.3, J17.3
/Blower controller/PWMFan4: C11.1, J15.4, J17.4
/Blower controller/Switched_Fan_Power: C4.1, J15.9, J15.10, J15.11, J15.12, J20.2, Q2.2 (D), R90.2, TPSwitched_Fan_Power1.1
/Blower controller/TachFan1: C7.1, D2.1 (K), J15.5, J16.1, J20.3, R35.2, R37.1, R42.2
/Blower controller/TachFan2: C6.1, J15.6, J16.2
/Blower controller/TachFan3: C5.1, J15.7, J16.3
/Blower controller/TachFan4: C3.1, J15.8, J16.4
/Blower controller/nFAN1_PWM: R12.1, R34.1, R38.2, R41.2
/D_PSU_RX: A1.D19 (D19/RX1), D_PSU_RX1.1, J2.6, R14.2
/D_PSU_TX: A1.D18 (D18/TX1), D_PSU_TX1.1, J2.5, R15.1
/EN+: J10.11, J14.6
/EN-: J10.9, J14.5
/I2C_LevelShift/+3V3Local: C18.1, Q9.1 (G), Q10.1 (G), R66.2, R67.1, R68.1
/I2C_LevelShift/+5VLocal: C19.1, R69.1, R70.1, R73.1
/I2C_LevelShift/I2C_VCC: J23.1, J24.1, R74.1, R75.1, TP17.1
/I2C_LevelShift/SCL_5V: C20.1, J1.2, J24.2, R71.1, TP18.1
/I2C_LevelShift/SDA_5V: C21.1, J1.4, J24.4, R72.1, TP19.1
/PAR: J10.7, J14.4
/POK: J10.5, J14.3
/PS_SCL: J10.19, R16.2
/PS_SDA: J9.10, J10.20, R13.1
/RX: J10.23, R15.2
/SPI_ControllerLevel_Shifter/+3V3Local: C16.1, Q5.1 (G), Q6.1 (G), Q7.1 (G), Q8.1 (G), R59.2, R61.1, R62.1, R64.1, R65.1
/SPI_ControllerLevel_Shifter/+5VLocal: C17.1, R50.2, R54.1, R56.1, R57.1, R58.1
/SPI_ControllerLevel_Shifter/CIPO: C12.1, J21.6, Q6.3 (D), R51.1, R56.2, TP13.1
/SPI_ControllerLevel_Shifter/COPI: C14.1, J21.2, Q8.3 (D), R53.1, R58.2, TP15.1
/SPI_ControllerLevel_Shifter/C_SCK: C13.1, J21.4, Q7.3 (D), R52.1, R57.2, TP14.1
/SPI_ControllerLevel_Shifter/ControllerVcc: J21.5, J22.1, R49.1, TP12.1
/SPI_ControllerLevel_Shifter/nCS: C15.1, J21.1, Q5.3 (D), R54.2, R55.1, TP16.1
/SSR Interface/Heater: R9.2, R47.1, R81.1
/SSR Interface/Heater_SSR_High: J13.1, R88.2, R89.2
/SSR Interface/Heater_SSR_Low: J13.2, R48.2
/TX: J10.24, R14.1
/Thermocouple Amplifier I2C breakout board - MCP9600/+VccMCP9600: JP19.1, JP20.1, JP21.1, R31.2, TP10.1
/Thermocouple Amplifier I2C breakout board - MCP9600/SCL: JP19.3, JP20.3, JP21.3, R2.2
/Thermocouple Amplifier I2C breakout board - MCP9600/SDA: JP19.4, JP20.4, JP21.4, R4.2
/Thermocouple Amplifier SPI Interface breakout board - MAX31855 /+VccMAX31855: JP16.1, JP17.1, JP18.1, R30.2, R84.2, TP9.1
/Thermocouple Amplifier SPI Interface breakout board - MAX31855 /DO: JP16.4, JP17.4, JP18.4, R6.2
/Thermocouple Amplifier SPI Interface breakout board - MAX31855 /SCK: JP16.6, JP17.6, JP18.6, R5.2
/Thermocouple Amplifier SPI Interface breakout board - MAX31855 /nCS_1: JP16.5, R7.2
/Thermocouple Amplifier SPI Interface breakout board - MAX31855 /nCS_2: JP17.5, R3.2
/Thermocouple Amplifier SPI Interface breakout board - MAX31855 /nCS_3: JP18.5, R1.2
/Thermocouple Amplifier with 1-Wire Breakout Board - MAX31850K/+VccMAX31850: JP1.1 (A), JP2.3 (B), JP3.3 (B), JP4.3 (B), JP5.3 (B), JP6.1 (A), JP7.3 (B), JP8.3 (B), JP9.7, JP10.7, JP11.3 (B), JP12.3 (B), JP13.1 (A), JP14.3 (B), JP15.7, R17.2, R82.2, R83.2, TP5.1
/VCI: J10.15, J14.8
/VO+: J9.1, J10.2, R80.2
/VO-: J9.2, J10.4, R79.2
/VS+: J10.1, J14.1, J25.1, R79.1, R80.1
/VS-: J10.3, J14.2, J25.2
/VSET: J9.4, J10.8
AREF: A1.AREF, J7.8
BLOWER_ENABLE: A1.D22, J8.4, R10.2
BLOWER_TACH: A1.A0, J5.1, R11.2
CANR: A1.CANR (CANRX), J4.7
CANT: A1.CANT (CANTX), J4.8
CIPO: A1.MISO (SPI_MISO), CIPO1.1, Q6.2 (S), R51.2, R60.2, R62.2
COPI: A1.MOSI (SPI_MOSI), COPI1.1, Q8.2 (S), R6.1, R53.2, R65.2
D0: A1.D0 (D0/RX0), J6.1
D1: A1.D1 (D1/TX0), J6.2
D23: A1.D23, J8.3
D25: A1.D25, J8.5
D27: A1.D27, J8.7
D29: A1.D29, J8.9
D31: A1.D31, J8.11
D32: A1.D32, J8.14, Q5.2 (S), R55.2, R61.2
D37: A1.D37, J8.17, R91.2
D38: A1.D38, J8.20, R8.2
D39: A1.D39, C1.1, J1.1, J8.19
D40: A1.D40, J8.22
D41: A1.D41, J8.21
D42: A1.D42, J8.24
D43: A1.D43, J8.23
D44: A1.D44, J8.26
D45: A1.D45, J8.25
D46: A1.D46, J8.28
D47: A1.D47, J8.27
D48: A1.D48, J8.30
D49: A1.D49, J8.29
D50: A1.D50, J8.32
D51: A1.D51, J8.31, R9.1
D52: A1.D52 (D52_CS2), J8.34
D53: A1.D53, J8.33
DAC0: A1.DAC0, J4.5
DAC1: A1.DAC1, J4.6
GND: A1.GND1 (GND), A1.GND2 (GND), A1.GND3 (GND), A1.GND4 (SPI_GND), A1.GND5 (GND), A1.GND6 (GND), C1.2, C2.2, C3.2, C4.2, C5.2, C6.2, C7.2, C8.2, C9.2, C10.2, C11.2, C12.2, C13.2, C14.2, C15.2, C16.2, C17.2, C18.2, C19.2, C20.2, C21.2, C22.1, D1.2 (A), D2.2 (A), H1.1, H2.1, H3.1, H4.1, H5.1, J1.0 (PAD), J1.3, J1.6, J1.7, J1.8, J1.9, J3.2, J3.3, J7.7, J8.35, J8.36, J9.3, J9.5, J9.7, J9.8, J9.9, J10.6, J10.10, J10.14, J10.16, J10.18, J10.22, J11.2, J12.2, J15.0 (PAD), J15.14, J15.15, J15.16, J15.17, J18.1, J20.1, J21.3, J24.3, JP1.3 (B), JP2.1 (A), JP3.1 (A), JP4.1 (A), JP5.1 (A), JP6.3 (B), JP7.1 (A), JP8.1 (A), JP9.8, JP10.8, JP11.1 (A), JP12.1 (A), JP13.3 (B), JP14.1 (A), JP15.8, JP16.3, JP17.3, JP18.3, JP19.2, JP20.2, JP21.2, Q1.2 (S), Q3.2 (S), Q4.2 (S), R32.1, R43.2, R46.2, R63.1, R81.2, R85.1, R86.1, R87.1, S1.1, S1.2, TP1.1, TP3.1, TP4.1, TP11.1
LOOPBACK13: A1.D36, J8.18, R92.2
unnamed: A1.D4 (D4_CS1), J6.5
unnamed: A1.D10 (D10_CS0), J7.3
unnamed: A1.D14 (D14/TX3), J2.1
unnamed: A1.D15 (D15/RX3), J2.2
unnamed: A1.D16 (D16/TX2), J2.3
unnamed: A1.D17 (D17/RX2), J2.4
unnamed: A1.IORF (IOREF), J3.7
unnamed: A1.RST1 (RESET), J3.6
unnamed: C2.1, J1.5, R8.1
unnamed: C22.2, ISO1.1, ISO2.1, ISO3.1, ISO4.1, ISO5.1, R32.2
unnamed: D1.1 (K), J20.4, Q1.3 (D), R33.2, R34.2, R36.1
unnamed: A1.VIN, J3.1, R76.2, VIN1.1
unnamed: A1.A8, J4.1
unnamed: A1.A9, J4.2
unnamed: A1.A10, J4.3
unnamed: A1.A11, J4.4
unnamed: A1.A1, J5.2
unnamed: A1.A2, J5.3
unnamed: A1.A3, J5.4
unnamed: A1.A4, J5.5
unnamed: A1.A5, J5.6
unnamed: A1.A6, J5.7
unnamed: A1.A7, J5.8
unnamed: A1.D2, J6.3
unnamed: A1.D3, J6.4
unnamed: A1.D6, J6.7
unnamed: A1.D7, J6.8
unnamed: A1.D8, J7.1
unnamed: A1.D11, J7.4
unnamed: A1.D12, J7.5
unnamed: A1.D13, J7.6
unnamed: A1.D24, J8.6
unnamed: A1.D26, J8.8
unnamed: A1.D28, J8.10
unnamed: A1.D30, J8.12
unnamed: J15.18, J19.1
unnamed: J15.19, J19.2
unnamed: J15.20, J19.3
unnamed: J15.21, J19.4
unnamed: J15.22, J19.5
unnamed: J15.23, J19.6
unnamed: J15.24, J19.7
unnamed: JP1.2 (C), R22.1
unnamed: JP2.2 (C), R20.1
unnamed: JP3.2 (C), R19.1
unnamed: JP4.2 (C), R18.1
unnamed: JP5.2 (C), R25.1
unnamed: JP6.2 (C), R24.1
unnamed: JP7.2 (C), R23.1
unnamed: JP8.2 (C), R21.1
unnamed: JP9.2, R18.2
unnamed: JP9.3, R19.2
unnamed: JP9.4, R20.2
unnamed: JP9.5, R22.2
unnamed: JP9.6, TP6.1
unnamed: JP10.2, R21.2
unnamed: JP10.3, R23.2
unnamed: JP10.4, R24.2
unnamed: JP10.5, R25.2
unnamed: JP10.6, TP7.1
unnamed: JP11.2 (C), R29.1
unnamed: JP12.2 (C), R28.1
unnamed: JP13.2 (C), R27.1
unnamed: JP14.2 (C), R26.1
unnamed: JP15.2, R26.2
unnamed: JP15.3, R27.2
unnamed: JP15.4, R28.2
unnamed: JP15.5, R29.2
unnamed: JP15.6, TP8.1
unnamed: JP19.9, R85.2
unnamed: JP20.9, R86.2
unnamed: JP21.9, R87.2
unnamed: Q1.1 (G), R38.1
unnamed: Q2.1 (G), R40.1
unnamed: Q3.3 (D), R40.2, R44.2
unnamed: Q3.1 (G), R45.1
unnamed: Q4.3 (D), R48.1
unnamed: Q4.1 (G), R47.2
unnamed: Q9.3 (D), R69.2, R71.2
unnamed: Q10.3 (D), R70.2, R72.2
unnamed: R39.2, R44.1
unnamed: R60.1, R63.2
ONE_WIRE_TC: A1.D5, J6.6, JP9.1, JP10.1, JP15.1, R83.1
SCL: A1.D21 (D21/SCL), J2.8, Q9.2 (S), R2.1, R16.1, R67.2, R77.1, SCL1.1
SCL1: A1.SCL1, J7.10
SDA: A1.D20 (D20/SDA), J2.7, Q10.2 (S), R4.1, R13.2, R68.2, R78.1, SDA1.1
SDA1: A1.SDA1, J7.9
SPI_SCK: A1.SCK (SPI_SCK), Q7.2 (S), R5.1, R52.2, R64.2, SPI_SCK1.1
SPI_nRST: A1.RST2 (SPI_RESET), S1.3, S1.4
TC_nCS1: A1.D33, J8.13, R7.1
TC_nCS2: A1.D34, J8.16, R3.1
TC_nCS3: A1.D35, J8.15, R1.1
nFAN1_PWM: A1.D9, J7.2, R12.2

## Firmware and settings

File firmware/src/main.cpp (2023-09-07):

/* Copyright (C) 2023 Robert Read, Ben Coombs.

This program includes free software: you can redistribute it and/or modify
it under the terms of the GNU Affero General Public License as
published by the Free Software Foundation, either version 3 of the
License, or (at your option) any later version.

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
This program is distributed in the hope that it will be useful,
but WITHOUT ANY WARRANTY; without even the implied warranty of
MERCHANTABILITY or FITNESS FOR A PARTICULAR PURPOSE.
*/

#ifdef ARDUINO
#include <Arduino.h>
//#include <display.h>
#else // Native
//
#endif

#include <core.h>
#include <cog_hal.h>

#include <retrieve_script_UDP_task.h>
#include <cog_task.h>
#include <serial_task.h>
#include <fault_task.h>
#include <duty_cycle_task.h>
#include <heater_pid_task.h>
#include <read_temps_task.h>
#include <temp_refresh_task.h>
#include <serialReportTask.h>

// #include <fanPID_task.h>
#ifdef TEST_FANS_ONLY
#include <fanTEST_task.h>
#endif

using namespace OxCore;
static Core core;

/***** Declare your tasks here *****/

OxApp::RetrieveScriptUDPTask retrieveScriptUDPTask;
OxApp::CogTask cogTask;
OxApp::SerialTask serialTask;
OxApp::FaultTask faultTask;

HeaterPIDTask heaterPIDTask;
DutyCycleTask dutyCycleTask;
ReadTempsTask readTempsTask;
TempRefreshTask tempRefreshTask;
SerialReportTask serialReportTask;

#include <machine.h>

MachineConfig machineConfig;
/***********************************/

#define ETHERNET_BOARD_PRESENT 1
// #define ETHERNET_BOARD_PRESENT 0 //No ethernet.


// This is to allow a code idiom compatible with the way
// the machine config is found  inside the Tasks
MachineConfig *getConfig() {
  return &machineConfig;
}

// TODO: we need to have setups for individual pieces
// of the Hardware Abstraction Layer
void setup()
{
  OxCore::serialBegin(115200UL);
  delay(500);

  Debug<const char *>("Starting Ox...\n");
  delay(100);
  if (core.Boot() == false) {
      ErrorHandler::Log(ErrorLevel::Critical, ErrorCode::CoreFailedToBoot);
      // TODO: Output error message
      //return EXIT_FAILURE;
      return;
  }
  Debug<const char *>("Core booted...\n");
  delay(100);

  machineConfig.init();
  //  Eventually we will migrate all hardware to the COG_HAL..
  machineConfig.hal = new COG_HAL();
  bool initSuccess  = machineConfig.hal->init();
  if (!initSuccess) {
    Serial.println("Could not init Hardware Abastraction Layer Properly!");
    abort();
  }

  // Now we will set the machine state to "Off"
  getConfig()->ms = Off;

  /***** Configure and add your tasks here *****/

  OxCore::TaskProperties readTempsProperties;
  readTempsProperties.name = "readTemps";
  readTempsProperties.id = 19;
  readTempsProperties.period = readTempsTask.PERIOD_MS;
  readTempsProperties.priority = OxCore::TaskPriority::High;
  readTempsProperties.state_and_config = (void *) &machineConfig;
  bool readAdd = core.AddTask(&readTempsTask, &readTempsProperties);
  if (!readAdd) {
    OxCore::Debug<const char *>("ReadTemps Task add failed\n");
    abort();
  }

  OxCore::TaskProperties serialReportProperties;
  serialReportProperties.name = "serialReportTemps";
  serialReportProperties.id = 20;
  serialReportProperties.period = serialReportTask.PERIOD_MS;
  serialReportProperties.priority = OxCore::TaskPriority::High;
  serialReportProperties.state_and_config = (void *) &machineConfig;
  bool serialReportAdd = core.AddTask(&serialReportTask, &serialReportProperties);
  if (!serialReportAdd) {
    OxCore::Debug<const char *>("serialReport Task add failed\n");
    abort();
  }
  OxCore::TaskProperties cogProperties;
  cogProperties.name = "cog";
  cogProperties.id = 21;
  cogProperties.period = cogTask.PERIOD_MS;
  cogProperties.priority = OxCore::TaskPriority::High;
  cogProperties.state_and_config = (void *) &machineConfig;
  bool cogAdd = core.AddTask(&cogTask, &cogProperties);
  if (!cogAdd) {
    OxCore::Debug<const char *>("Cognitive Task add failed\n");
    abort();
  }

  getConfig()->ms = Off;
  cogTask.heaterPIDTask = &heaterPIDTask;


  OxCore::TaskProperties serialProperties;
  serialProperties.name = "serial";
  serialProperties.id = 22;
  serialProperties.period = 250;
  serialProperties.priority = OxCore::TaskPriority::High;
  serialProperties.state_and_config = (void *) &machineConfig;
   bool serialAdd = core.AddTask(&serialTask, &serialProperties);
  if (!serialAdd) {
    OxCore::Debug<const char *>("SerialProperties add failed\n");
    abort();
  }


  OxCore::TaskProperties TempRefreshProperties;
  TempRefreshProperties.name = "TempRefresh";
  TempRefreshProperties.id = 23;
  TempRefreshProperties.period = tempRefreshTask.PERIOD_MS;
  TempRefreshProperties.priority = OxCore::TaskPriority::Low;
  TempRefreshProperties.state_and_config = (void *) &machineConfig;
  bool tempRefresh = core.AddTask(&tempRefreshTask, &TempRefreshProperties);
  if (!tempRefresh) {
    OxCore::Debug<const char *>("Temp Refresh add failed\n");
    abort();
  }

  cogTask.tempRefreshTask = &tempRefreshTask;


  if (ETHERNET_BOARD_PRESENT) {
    OxCore::TaskProperties retrieveScriptUDPProperties;
    retrieveScriptUDPProperties.name = "retrieveScriptUDP";
    retrieveScriptUDPProperties.id = 24;
    retrieveScriptUDPProperties.period = 5000;
    retrieveScriptUDPProperties.priority = OxCore::TaskPriority::High;
    retrieveScriptUDPProperties.state_and_config = (void *) &machineConfig;

    retrieveScriptUDPTask.DEBUG_UDP = 2;
    bool retrieveScriptUDP = core.AddTask(&retrieveScriptUDPTask, &retrieveScriptUDPProperties);
    if (!retrieveScriptUDP) {
      OxCore::Debug<const char *>("Retrieve Script UDP\n");
      abort();
    }
  }

  dutyCycleTask.whichHeater = (Stage2Heater) 0;

  OxCore::Debug<const char *>("Duty Cycle Setup\n");
  OxCore::TaskProperties dutyCycleProperties;
  dutyCycleProperties.name = "dutyCycle";
  dutyCycleProperties.id = 25;
  dutyCycleProperties.period = dutyCycleTask.PERIOD_MS;
  dutyCycleProperties.priority = OxCore::TaskPriority::Low;
  dutyCycleProperties.state_and_config = (void *) &machineConfig;
  bool dutyCycleAdd = core.AddTask(&dutyCycleTask, &dutyCycleProperties);
  if (!dutyCycleAdd) {
    OxCore::Debug<const char *>("dutyCycleAdd Failed\n");
    abort();
  }
  dutyCycleTask.one_pin_heater = getConfig()->hal->_ac_heaters[0];

  OxCore::TaskProperties HeaterPIDProperties;
  HeaterPIDProperties.name = "HeaterPID";
  HeaterPIDProperties.id = 26;
  HeaterPIDProperties.period = heaterPIDTask.PERIOD_MS;
  HeaterPIDProperties.priority = OxCore::TaskPriority::High;
  HeaterPIDProperties.state_and_config = (void *) &machineConfig;
  bool heaterPIDAdd = core.AddTask(&heaterPIDTask, &HeaterPIDProperties);

  if (!heaterPIDAdd) {
    OxCore::Debug<const char *>("heaterPIDAdd Faild\n");
    abort();
  }

  heaterPIDTask.whichHeater = (Stage2Heater) 0;

  heaterPIDTask.dutyCycleTask = &dutyCycleTask;

  cogTask.heaterPIDTask = &heaterPIDTask;
  cogTask.tempRefreshTask = &tempRefreshTask;

  heaterPIDTask.DEBUG_PID = 1;
  cogTask.DEBUG_LEVEL = 2;

   OxCore::Debug<const char *>("Added tasks\n");

  /*********************************************/
}


void loop() {
  OxCore::Debug<const char *>("Loop starting...\n");

  // Blocking call
  if (core.Run() == false) {
      OxCore::ErrorHandler::Log(OxCore::ErrorLevel::Critical, OxCore::ErrorCode::CoreFailedToRun);
#ifdef ARDUINO
      // make sure we print anything needed!
      Serial.println("Critical error!");
      delay(100);
      // Loop endlessly to stop the program from running
      while (true) {
        Serial.println("INTERNAL ERROR!");
        delay(100);
      }
#endif
      return;
  } else {
    Serial.println("INTERNAL ERROR!");
    delay(100);
  }
}

#ifndef ARDUINO
int main(int argc, char **argv)
{
  setup();
  while (true) {
    loop();
  }
  return 0;
}
#endif

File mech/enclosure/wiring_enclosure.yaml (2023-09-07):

#templates for generalized connectors
#utilizes https://github.com/wireviz/WireViz
templates:
  - &template_con
    type: Anderson Power SB50 SB
    subtype:  Dual
    pinlabels: [V+, V-, V+, V-]
  - &template_wire
    gauge: 6.00 mm2
    length: 0.2
    colors: [RD,BK,RD,BK]
    category: bundle
  - &ac_hookup
        wirecount: 3
        length: 0.2 //15ft
        category: bundle
        colors: [BK,WH,GN]
        gauge: 12 awg
  - &tc_hookup
        wirecount: 2
        length: 0.02
        category: bundle
        colrs: [YL,RD]
cables:   # dictionary of all used cables and wires
  W0:
    gauge: 1 mm2
    show_equiv: true
    length: 0.5
    color_code: IEC
    wirecount: 3
    category: bundle

  W1:    # unique cable designator/name
    gauge: 6.0 mm2
    # defaults to false; can auto-convert between mm2 and AWG and display the result when set to true
    show_equiv: true
     # <int/float> is assumed to be in meters unless <unit> is specified
                                # e.g. length: 2.5 -> assumed to be 2.5 m
                                # or   length: 2.5 ft -> "ft" is used as the unit
                                # Units are not converted during BOM generation;
                                # different units result in separate BOM entries.
    length: 0.5
    #color_code: IEC
    wirecount: 2
    category: bundle
    colors: [RD,BK]     # list of colors (see below)
    wirelabels: [V+,V-] # optional; one label for each wire
  W2:
    gauge: 0.25 mm2
    show_equiv: true
    length: 0.5
    color_code: IEC
    wirecount: 24
    category: bundle

  W3: #TC 1
    <<: *tc_hookup
    length: 0.2
    show_equiv: true
  W4: #TC 2
    <<: *tc_hookup
    length: 0.2
    show_equiv: true
  W5: #TC 3
    <<: *tc_hookup
    length: 0.2
    show_equiv: true
  W6: 
    <<: *template_wire

  W7: #DC powersupply_12v
    <<: *ac_hookup

  W8: #DC powersupply_24v
    <<: *ac_hookup

  W9: #DC powersupply_programmable
    <<: *ac_hookup

  power_cord:
      wirecount: 3
      length: 5000 //15ft
      category: bundle
      colors: [BK,WH,GN]

connectors:  # dictionary of all used connectors
  ferrule_spade:  # unique connector designator/name
    style: simple
    autogenerate: true
    type: Spade ferrule
    subtype: spade
  ferrule_crimp:
    style: simple
    autogenerate: true
    type: Crimp ferrule
    subtype: 0.25 mm²
    color: YE

  CN2:
    type: JST PHDR-24VS
    subtype: female
    pincount: 24
    pinlabels: [VS+, VO+, VS-, VO-, POK, GND, PAR, VSET, EN-, GND, EN+, AUX, ACI, GND, VCI, GND, AUX, GND, SCL, SDA, AUX, GND, RX, TX]

  X1:
    type: D-Sub
    subtype: male
    pincount: 9
#    pinlabels: []

  X2:
    type: D-Sub
    subtype: male
    pincount: 25
    pinlabels: [NP,NP,NP,NP,PWM1,PWM2,PWM3,PWM4,+12v,+12v,+12v,+12v,NP,GND,GND,GND,GND,PWM5,PWM6,PWM7,PWM8,PWM9,PWM10,PWM11,NP]
    notes: Pin 5-8 have 470 Ohm Pull Up resistors
  X3:
    <<: *template_con
  X4:
    <<: *template_con
  X5:
    <<: *template_con
  X6:
    <<: *template_con
  Arduino_Due:
    type: jumpers
    pinlabels: [TX,RX, TX1, RX1, SDA, SCL, VIN, GND, A0, A1, A2, A3, A4, A5, A6, A7, A8, A9, A10, A11, D0, D1, D2, D3, D4, D5, D6, D7, D8, D9, D10, D11, D12, D13, D14, D15, D16, D17, D18, D19, D20, D21, 3.3V, GND]
  Fan_Interface:
    type: jumpers
    pinlabels: [ nFAN1_PWM, FAN1_FG, nFAN2_PWM, FAN2_FG, FAN3_FG, nFAN3_PWM, FAN4_FG, nFAN4_PWM]

connections:  # list of all connections to be made between cables and connectors
  -
    - ferrule_crimp
    - W1: [1-2]
    - ferrule_crimp
  -
    - CN2: [1-24]
    - W2: [1-24]
    - ferrule_crimp
  -
    - X1: [5,2,3]
    - W0: [1-3]
    - Arduino_Due: [D0,D1,D21]
  -
    - X3: [1-4]
    - W3: [1-4]
    - ferrule_crimp
  -
    - X4: [1-4]
    - W4: [1-4]
    - ferrule_crimp
  -
    - X5: [1-4]
    - W5: [1-4]
    - ferrule_crimp
  -
     - ferrule_crimp
     - W7: [1-3]
  -  
     - ferrule_crimp
     - Arduino_Due: [A0, D4, D9, D18, D19, D51, 3.3V, GND]
     - nFAN1_PWM
     - FAN1_FG
     - nFAN2_PWM
     - FAN2_FG
     - FAN3_FG
     - nFAN3_PWM
     - FAN4_FG
     - nFAN4_PWM
     
#  -

#additional_bom_items:  # custom items to add to BOM
#  - zip ties           # BOM item (see below)

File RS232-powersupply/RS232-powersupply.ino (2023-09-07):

//#include <Arduino.h>
#include <SPI.h>
#include <Ethernet.h>
#include <EthernetUdp.h> // UDP library from: bjoern@cs.stanford.edu 12/30/2008

// #define ADDRESS 0x04
#define ADDRESS 0x00
#define MYDELAY 500

uint32_t epoch = 0;
uint32_t startMillis = 0;

char packetBuffer[10 * 1024];

#define TIMESERVER "time.nist.gov"
#define DATASERVER "cogs.coslabs.com"
#define DATAPORT 6060

#define localPort 2390
#define UDP_TIMEOUT 5000

IPAddress ip(192, 168, 1, 177);

// An EthernetUDP instance to let us send and receive packets over UDP
EthernetUDP Udp;

#define NUMBER_OF_MAC      20
byte mac[][NUMBER_OF_MAC] =
{
  { 0xDE, 0xAD, 0xBE, 0xEF, 0xFE, 0x01 },
  { 0xDE, 0xAD, 0xBE, 0xEF, 0xBE, 0x02 },
  { 0xDE, 0xAD, 0xBE, 0xEF, 0xFE, 0x03 },
  { 0xDE, 0xAD, 0xBE, 0xEF, 0xBE, 0x04 },
  { 0xDE, 0xAD, 0xBE, 0xEF, 0xFE, 0x05 },
  { 0xDE, 0xAD, 0xBE, 0xEF, 0xBE, 0x06 },
  { 0xDE, 0xAD, 0xBE, 0xEF, 0xFE, 0x07 },
  { 0xDE, 0xAD, 0xBE, 0xEF, 0xBE, 0x08 },
  { 0xDE, 0xAD, 0xBE, 0xEF, 0xFE, 0x09 },
  { 0xDE, 0xAD, 0xBE, 0xEF, 0xBE, 0x0A },
  { 0xDE, 0xAD, 0xBE, 0xEF, 0xFE, 0x0B },
  { 0xDE, 0xAD, 0xBE, 0xEF, 0xBE, 0x0C },
  { 0xDE, 0xAD, 0xBE, 0xEF, 0xFE, 0x0D },
  { 0xDE, 0xAD, 0xBE, 0xEF, 0xBE, 0x0E },
  { 0xDE, 0xAD, 0xBE, 0xEF, 0xFE, 0x0F },
  { 0xDE, 0xAD, 0xBE, 0xEF, 0xBE, 0x10 },
  { 0xDE, 0xAD, 0xBE, 0xEF, 0xFE, 0x11 },
  { 0xDE, 0xAD, 0xBE, 0xEF, 0xBE, 0x12 },
  { 0xDE, 0xAD, 0xBE, 0xEF, 0xFE, 0x13 },
  { 0xDE, 0xAD, 0xBE, 0xEF, 0xBE, 0x14 },
};

char manuf[17]; // INFO 0
char model[17];  // INFO 1
char voltage_string[5]; // INFO 2
char revision[5]; // INFO 3
char manuf_date[9];  // INFO 4
char serial[17];  // INFO 5
char country[17];  // INFO 6
uint16_t rate_voltage;  //50-51
uint16_t rate_current;  //52-53
uint16_t max_voltage;  //54-55
uint16_t max_current;  //56-57
uint16_t out_voltage;  //60-61
uint16_t out_current;  //62-63
uint8_t temp;  //68
uint8_t status0;  //6C
uint8_t status1;  //6F
uint16_t set_voltage; // 70-71 r/w
uint16_t set_current; // 72-73 r/w
uint8_t control; //  7C  r/w
uint8_t on_off;

int setPS_Addr(uint8_t addr) {
  Serial1.print("ADDS "); Serial1.print(addr); Serial1.print("\r\n");
  delay(50);
  char buff[5];
  uint8_t c = Serial1.readBytesUntil('\n', buff, sizeof buff);
  if (c != 3 || buff[0] != '=' || buff[1] != '>') return 0;
  return 1;
}

int setPS_Val(uint8_t addr, const char *loc, const char *val) {
  if (!setPS_Addr(addr)) {
    Serial.println("didn't set address");
    return 0;
  }

  Serial1.print(loc); Serial1.print(' '); Serial1.print(val); Serial1.print("\r\n");
  delay(100);
  char b[5];
  int c = Serial1.readBytesUntil('\n', b, sizeof b);
  if (c != 3 || b[0] != '=' || b[1] != '>') return 0;
  return 1;
}

int setPS_GlobOnOff(uint8_t addr, const char *val) {
  if (strcasecmp(val, "on") == 0) val = "1";
  else val = "0";
  return setPS_Val(addr, "GLOB", val);
}

int setPS_OnOff(uint8_t addr, const char *val) {
  if (strcasecmp(val, "on") == 0) val = "1";
  else val = "0";
  return setPS_Val(addr, "POWER", val);
}

int setPS_Voltage(uint8_t addr, uint16_t volts) {
  char b[7];
  snprintf(b, sizeof b, "%4.1f", volts / 100.0);
  return setPS_Val(addr, "SV", b);
}

int setPS_Current(uint8_t addr, uint16_t amps) {
  char b[7];
  snprintf(b, sizeof b, "%4.1f", amps / 100.0);
  return setPS_Val(addr, "SI", b);
}

// TODO: This is untested
int setPS_GCurrent(uint8_t addr, uint16_t amps) {
  char b[7];
  snprintf(b, sizeof b, "%4.1f", amps / 100.0);
  return setPS_Val(addr, "GSI", b);
}

char *getPS_Val(uint8_t addr, const char *val) {
  static char rval[50];
  if (!setPS_Addr(addr)) {
    Serial.println("didn't set address");
    return 0;
  }

  Serial1.print(val); Serial1.print("\r\n");
  delay(100);
  int c = Serial1.readBytesUntil('\n', rval, sizeof rval);
  rval[c-1] = '\0';
  delay(10);
  char b[5];
  c = Serial1.readBytesUntil('\n', b, sizeof b);
  if (c != 3 || b[0] != '=' || b[1] != '>') return NULL;
  return rval;
}

void getPS_Manuf(int addr) {
  char *r = getPS_Val(addr, "INFO 0");
  strncpy(manuf, r, sizeof manuf);
}

void getPS_Model(int addr) {
  char *r = getPS_Val(addr, "INFO 1");
  strncpy(model, r, sizeof model);
}

void getPS_VoltageString(int addr) {
  char *r = getPS_Val(addr, "INFO 2");
  strncpy(voltage_string, r, sizeof voltage_string);
}

void getPS_Revision(int addr) {
  char *r = getPS_Val(addr, "INFO 3");
  strncpy(revision, r, sizeof revision);
}

void getPS_ManufDate(int addr) {
  char *r = getPS_Val(addr, "INFO 4");
  strncpy(manuf_date, r, sizeof manuf_date);
}

void getPS_Serial(int addr) {
  char *r = getPS_Val(addr, "INFO 5");
  strncpy(serial, r, sizeof serial);
}

void getPS_Country(int addr) {
  char *r = getPS_Val(addr, "INFO 6");
  strncpy(country, r, sizeof country);
}

void getPS_RateVoltage(int addr) {
  char *r = getPS_Val(addr, "RATE?");
  char b[20];
  strncpy(b, r, sizeof b);
  char *ptr = NULL;
  rate_voltage = -1;
  if ((ptr = strchr(b, ' '))) {
    *ptr = '\0';
    rate_voltage = int(atof(b) * 100);
  }
}

void getPS_RateCurrent(int addr) {
  char *r = getPS_Val(addr, "RATE?");
  char b[20];
  strncpy(b, r, sizeof b);
  char *ptr = NULL;
  rate_current = -1;
  if ((ptr = strchr(b, ' '))) {
    rate_current = int(atof(ptr + 1) * 100);
  }
}

void getPS_OnOff(int addr) {
  char *r = getPS_Val(addr, "POWER 2");
  switch (r[0]) {
  case '0': on_off = 0; break;
  case '1': on_off = 1; break;
  case '2': on_off = 0; break;
  case '3': on_off = 1; break;
  }
}

void getPS_MaxVoltage(int addr) {
  max_voltage = -1;
}

void getPS_MaxCurrent(int addr) {
  max_current = -1;
}

void getPS_OutVoltage(int addr) {
  char *r = getPS_Val(addr, "RV?");
  out_voltage = int(atof(r) * 100);
}

void getPS_OutCurrent(int addr) {
  char *r = getPS_Val(addr, "RI?");
  out_current = int(atof(r) * 100);
}

void getPS_Status0(int addr) {
  char *r = getPS_Val(addr, "STUS 0");
  status0 = (r[0] - '0') << 4;
  status0 += (r[1] - '0') & 0x0F;
}

void getPS_Status1(int addr) {
  char *r = getPS_Val(addr, "STUS 1");
  status1 = (r[0] - '0') << 4;
  status1 += (r[1] - '0') & 0x0F;
}

void getPS_Temp(int addr) {
  char *r = getPS_Val(addr, "RT?");
  temp = atoi(r);
}

void getPS_SetVoltage(int addr) {
  char *r = getPS_Val(addr, "SV?");
  set_voltage = int(atof(r) * 100);
}

void getPS_SetCurrent(int addr) {
  char *r = getPS_Val(addr, "SI?");
  set_current = int(atof(r) * 100);
}

void getPS_Control(int addr) {
}
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

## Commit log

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2020-10-30 fixed bug in makefile
    [main.cpp]
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2020-10-31 Added basic display code, fixed Arduino timer
    [main.cpp]
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2021-08-22 Rename pioc to ox(#21)
    * Replace PIOC with Ox
    [main.cpp]
2021-12-08 Mega shaped shield with solenoid drivers and a range of sensors (#27)
    * Updated Ox MEGA2560 PCB V4
    * Latest Mega Shield for testing
    [Ox_MEGA2560_Rev3e_V4.brd, Ox_MEGA2560_Rev3e_V4.sch, Ox_MEGA2560_Rev3e_V5.brd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]
2021-12-19 WIP: Core lib (#25)
    * first
    * Add networking library
    * Core lib rework
    * Add cpp file template
    * Add static list and queue
    * Move PSA valve control to Task
    * More refactoring
    * Changes
    * Make the display a task
    * Core additions
    * Add support for PIRDS and PIRCS to database. (#26)
    * Update readme.
    * Align Python datetime ISO format with JavaScript
    * Fetch only the last minute of data.
    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
    [main.cpp]
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2021-12-28 Update core scheduler and error handler.
    [main.cpp]
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2022-01-10 Complete error handling flow.
    [main.cpp]
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2022-08-04 Fixing a bug in the warmup temperature machine state logic
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2022-09-08 partially working, but tachometer on fan doesn't work, even though a sketch with the same code seems to work
    [main.cpp]
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2022-09-10 Finally have the DeltaFan behavior somewhat properly, but PID controller is not working.
    [main.cpp]
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2023-03-08 fixing AC coming on
    [main.cpp]
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2023-03-15 Change, rotate, Anderson Connectors for over and under pins orentation each circuit.
    [frontpanel.FCStd]
2023-03-15 Fix errors on Anderson connector on some holes. Add AC recepticals.
    [frontpanel.FCStd]
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2023-03-16 Add dxf file. Make a PDF of the dxf file using LibreCAD.
    [frontpanel-frontpanelfrontpanel001.dxf, frontpanel.FCStd]
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2023-03-18 Create README.md
    FreeCAD screen capture showing images of some of the parts behind the "frontpanel". Note there appears to be an error on the holes for the Anderson front panel connector mount.
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2023-03-23 Fix size on Anderson Panel holder. Fix size on image of same.
    [frontpanel.FCStd]
2023-03-23 Move thermo couples to left side. Move DB25 and DB9 to right and in line with thermo couples.
    [frontpanel.FCStd]
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2023-03-24 Enlarge Opening and fix holes for Anderson Connector. Mark PDF as Version 1.2
    [frontpanel.FCStd]
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2023-03-27 Create a dxf file of the Rev1.2 front panel for quoting of fabrication.
    [frontpanel.FCStd, frontpanel_Rev1_2.dxf]
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2023-03-29 Added 3D models and additions for the 15" and 24" depth version of the cases
    [2020_profile.scad, aluminium_extrusion_plate_brackets.scad, customizable_aluminium_extrusion_plate_brackets.scad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]
2023-03-30 Initial commit of fan_I2C schematic and pcb with a .gitignore for KiCad.
    [fan_I2C.kicad_pcb, fan_I2C.kicad_sch]
2023-03-30 Add SPI and I2C level shifter circuits lifted from the PolyVent Interface Card.
    [I2C_Level_Shifter.kicad_sch, SPI_ControllerLevel_Shifter.kicad_sch, fan_I2C.kicad_sch]
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2023-04-02 added svg wiring diagram initial push, also added updated enclosure 15" depth with middle mounting plate
    [enclosure_15.scad, enclosure_15.stl]
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2023-04-05 Change width to 440mm. Move edge mounting holes to center of 20x20. Fix some techdrawing bugs.
    [frontpanel.FCStd]
2023-04-05 Updates to frontpanel for version 1.3 per issue number 59 and more. New fabrication files at version 1.3.
    [frontpanel.FCStd, frontpanel_Rev1_3.dxf]
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2023-05-21 clean up of testa and creation of an interactive test for the DC power supply
    [FanControllerFinal.fzz]
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2023-07-28 Reorder objects on Frontpanel making the pad and the perimiter holes first.
    [frontpanel.FCStd]
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2023-07-28 Generate dxf and step for RearPanel and rename Part in frontpanel file.
    [RearPanel3.dxf, RearPanel3.step, frontpanel.FCStd]
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2023-07-30 Import Decora receptical cover image. Scale and place. Move one Anderson Bezel forward to see interference.
    [frontpanel.FCStd]
2023-07-31 Add a drawing with dimensions for the two horizontal DIN rails on the bottom panel as per the March 2023 controller version 1.
    [frontpanel.FCStd]
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2023-07-31 Regenerate DXF files for Bottom and Rear using TechDraw and then right click export.
    [BottomPlateV1.dxf, RearPanel3.dxf, frontpanel.FCStd]
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2023-07-31 After pressing the recaculate button. And Selecting the AutoDesk DXF export. This worked to export a DXF!
    [frontpanel.FCStd]
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2023-08-02 Select only rear panel visible to import to A2plus assembly work bench.
    [frontpanel.FCStd]
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2023-08-03 Enclosure rough manual placement with constraint errors.
    [ASSY_ODECOS_V2.FCStd, Extrusions_Simple.FCStd]
2023-08-03 Changes to the Assy Odecos V2 and add lots of parts that make up the enclosure design and references to same.
    [20X28CornerBracket.step, ASSY_ODECOS_V2.FCStd, Decora cover v5.step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]
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2023-08-07 Add a parts info list and parts list. They are useless as is.
    [ASSY_ODECOS_V2.FCStd]
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2023-08-09 Add IEC AC power. Scale and move Thermocouple. Move DB25 and DB9.
    [frontpanel.FCStd]
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2023-08-10 Add PDF drawing of PowerWerx SB1 PanelPlate. and STEP and STL files.
    [PanelPlate_SB-PartBodySB1.step, PanelPlate_SB-PartBodySB1.stl, PanelPlate_SB.FCStd]
2023-08-10 As printing SB1 from STL. Update NASA COG Plantpanel for two IEC recepticals.
    [PanelPlate_SB-PartBodySB1.step, PanelPlate_SB-PartBodySB1.stl, PanelPlate_SB.FCStd]
2023-08-10 Add PDF drawing of PowerWerx SB2 PanelPlate and STEP and STL files.
    [PanelPlate_SB-PartSB2BodySB2.step, PanelPlate_SB-PartSB2BodySB2.stl, PanelPlate_SB.FCStd]
2023-08-10 Change PlantPanel for single Anderson SB1 plate. Update dimensions on PDF of SB1.
    [PanelPlate_SB.FCStd]
2023-08-11 added control interface board v1
    imported thermocouple projects from adafruit
    imported Due shield block
    added
    [Adafruit-MAX31850-thermocouple-breakout-board.kicad_sch, Adafruit-MAX31855-breakout-board.kicad_sch, Adafruit-MAX31856-PCB-master.kicad_sch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]
2023-08-11 Add a FreeCad Drawing of thermocouple jack panel with size guesses. Add jack panel to PlantPanel.
    [JackPanel_MJP.FCStd]
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2023-08-14 added labels for heiarchy sheets, and first pass on basic control interface circuits
    [Adafruit-MAX31850-thermocouple-breakout-board.kicad_sch, Adafruit-MAX31855-breakout-board.kicad_sch, Adafruit-MAX31856-PCB-master.kicad_sch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]
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2023-08-16 Update README.md
    Add to Front Panel Parts List:
    ground bar
    Details on thermocouple jack panel, snap strips and Miniature connectors.
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2023-08-16 3" 1/4" from the top sepeartion of low voltage from high voltage adds in a C19 C20 cutout and keeps the junction box wire nuts
    [rear panel edit 1_3.dxf]
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2023-08-17 imported Lee's changed inputs into the folder Control Board,
    Also added in Robert's pin labels
    ToDo: clean up broken links, and import in the layout files from Lee's project
    Clean up the fan control pinout, the DB25 is a bit of a mess
    consider using IDC to DB25 connectors for ease of assembly and installation.
    [Control v1.kicad_sch, Fan controller.kicad_sch, I2C_Level_Shifter.kicad_sch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]
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2023-08-18 Add Lees PublicInvention submodule library. Update Control V1 project and schematic for new library.
    [Adafruit-MAX31850-thermocouple-breakout-board.kicad_sch, Adafruit-MAX31855-breakout-board.kicad_sch, Control v1.kicad_sch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]
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2023-08-21 Update README.md
    More fixing on J9 and J10 for PWM and FG signal names.
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2023-08-22 Update README.md
    Add more schematic links to KiCanvas.
    Fix KiCad Library for Arduino library thumbnail.
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2023-08-23 fixing a bug in the data logging, seems to be working now
    [main.cpp, test_heater_ramp.cpp]
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2023-08-24 fixing a frustrating NPE that was my own fault
    [test_heater_ramp.cpp]
2023-08-24 Add footprints for thermoucouple modules to schematic and PCB. This commit does NOT capture the library changes.
    [Adafruit-MAX31850-thermocouple-breakout-board.kicad_sch, Adafruit-MAX31855-breakout-board.kicad_sch, Adafruit-MAX31856-PCB-master.kicad_sch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]
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2023-08-24 Flip the front panel around.
    [ASSY_ODECOS_V2.FCStd]
2023-08-24 Fix mounting holes for thermocouple.
    [Adafruit-MAX31850-thermocouple-breakout-board.kicad_sch, Control v1.kicad_pcb]
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2023-08-25 Fix swome ERC errors.
    [Adafruit-MAX31850-thermocouple-breakout-board.kicad_sch, Adafruit-MAX31855-breakout-board.kicad_sch, Adafruit-MAX31856-PCB-master.kicad_sch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]
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2023-08-27 Update README.md
    Ad to Due Pin Wiring up to Master reset.
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2023-08-28 Fixing some DRC errors on PCB.
    [Control v1.kicad_sch]
2023-08-28 fixing bug #148 by inceasing MAX_TASKS and some other improvements
    [main.cpp]
2023-08-28 Errors eliminated or ignored. Generating files for first attempt to submit to JCLPCB.
    [Adafruit-MAX31856-PCB-master.kicad_sch]
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2023-08-30 Add footprints to KiCad board. Make simple Due and Ethernte boards for pullin into FreeCAD assembly and do so.
    [ASSY_ODECOS_V2.FCStd, Control v1.kicad_pcb, EthernetShield.kicad_pcb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]
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2023-09-02 Fixing a major bug in the Sanyo Fan speed, and adding debugging to the scheduler to try to catch hangs
    [main.cpp]
2023-09-02 working mostly on improving ability to survive resets and other debugging
    [main.cpp]
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2023-09-04 checking if isinf on ohms values to avoid string being printed and messing up Cumulocity
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2023-09-06 finally have the temperatures being read correctly. However, warmup mode has not yet been tested.
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2023-09-06 Add Controler Support to Assy ODECOS, Move PCB dimensions to correct layer.
    [ControllerSupportRT.FCStd]
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2023-09-06 Reporting reset(watchdog) counts. UPdate screen shot.
    [WatchDog_Due_Eval.ino]
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2023-09-07 Update Watchdog to rev 6. Save to flash only when D12 low. Increment flash count on reset. Add serial number to structure.
    [WatchDog_Due_Eval.ino]

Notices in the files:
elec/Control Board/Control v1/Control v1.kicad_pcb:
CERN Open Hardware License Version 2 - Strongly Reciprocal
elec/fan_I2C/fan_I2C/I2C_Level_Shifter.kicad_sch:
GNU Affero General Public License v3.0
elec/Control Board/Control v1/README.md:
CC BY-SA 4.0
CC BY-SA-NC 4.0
